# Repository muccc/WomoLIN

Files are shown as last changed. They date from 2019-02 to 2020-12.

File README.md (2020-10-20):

use: git clone https://github.com/muccc/WomoLIN.git

# WomoLIN Hardware und sonstige Infos zum Projekt

Neue Wege in der konfigurierbaren Software Entwicklung eines Community Projektes

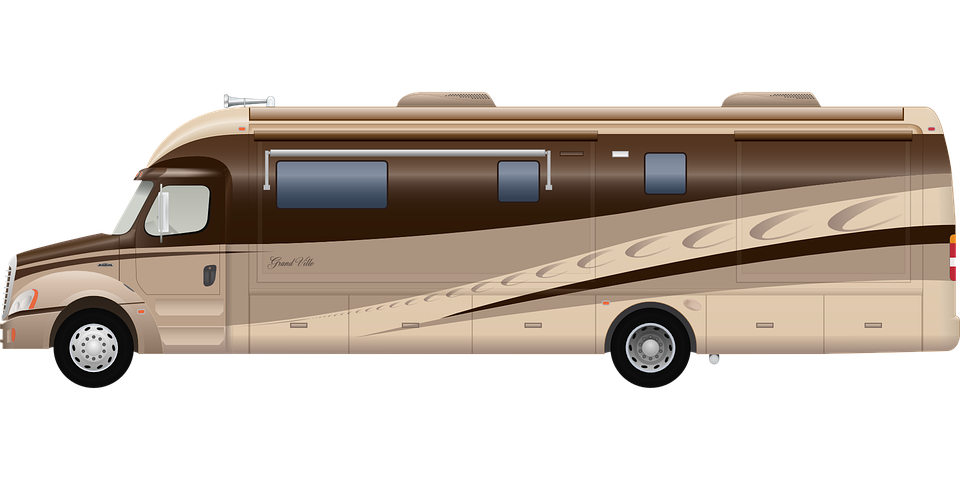
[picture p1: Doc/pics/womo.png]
Womo Bild


Alle Infos findet Ihr in unserem Wiki hier auf Github. 

https://github.com/muccc/WomoLIN/wiki/Home

# WomoLIN Meilensteine und Projektfortschritt

**18.Okt 2020  :** 100. Mitglied in unserer Telegramgruppe <br/>
**10.Aug 2020  :** Inbetriebnahme Controlboard 2.0.<br/>
**10.Juli 2020  :** Controlboard 2.0.<br/>
**10.Juni 2020  :** Beginn Einbau Controlboard in Womo von Jan.<br/>
**15.Mai 2020  :** Erstes Displayboard Kleinserie.<br/>
**11.Apr 2020  :** Erste Inbetriebnahme Display Unit mit Display.<br/>
**19.Mrz 2020  :** Die ersten Hardware für die Display Unit ist angekommen.<br/>
**16.Dez. bis 30.Dez.2019 :** 36th Chaos Communication Congress in Leipzig, Jan stellt die Hardware vor.<br/>
**10.Dez 2019  :** Die ersten Leiterplatten der Main Unit / Controlboard sind angekommen.<br/>
**03.Dez 2019  :** Der Schaltplan der Main Unit ist fertig gestellt.<br/> 

## **10.Aug 2020  :** Inbetriebnahme Controlboard 2.0.<br/>
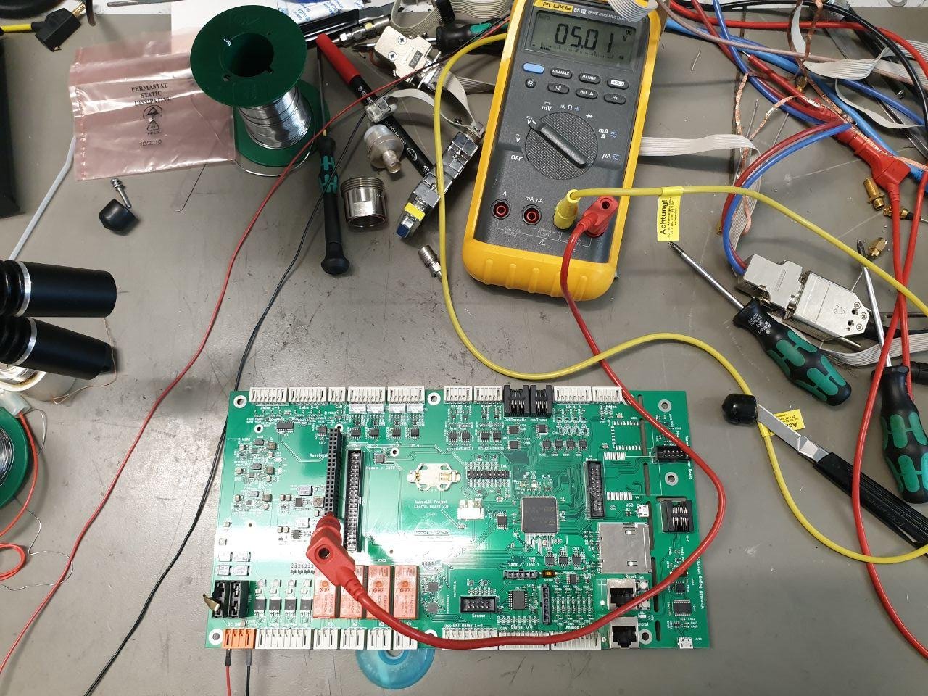
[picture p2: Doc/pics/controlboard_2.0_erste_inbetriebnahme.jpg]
Inbetriebnahme Controlboard 2.0


## **10.Juli 2020  :** Controlboard 2.0.<br/>
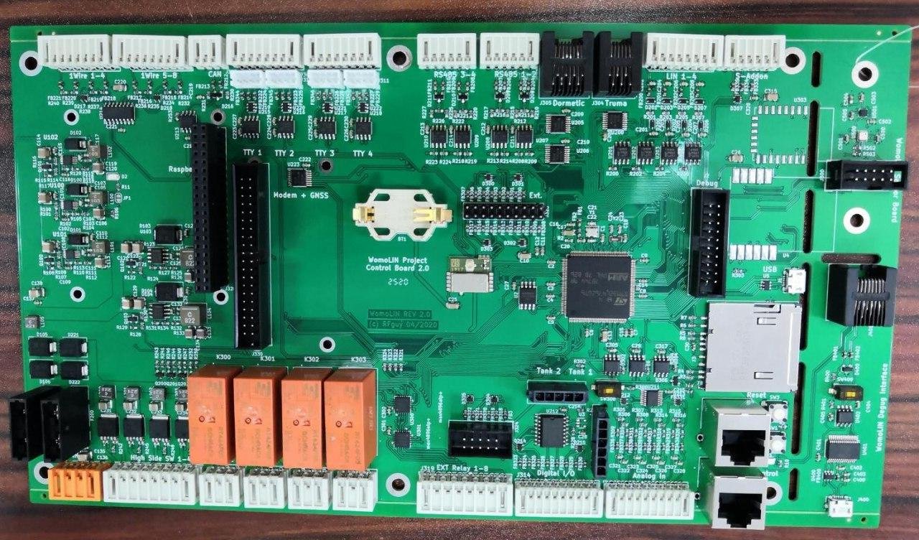
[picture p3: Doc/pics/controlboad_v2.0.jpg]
Controlboard 2.0


## **10.Juni 2020  :** Beginn Einbau Controlboard in Womo von Jan.<br/>
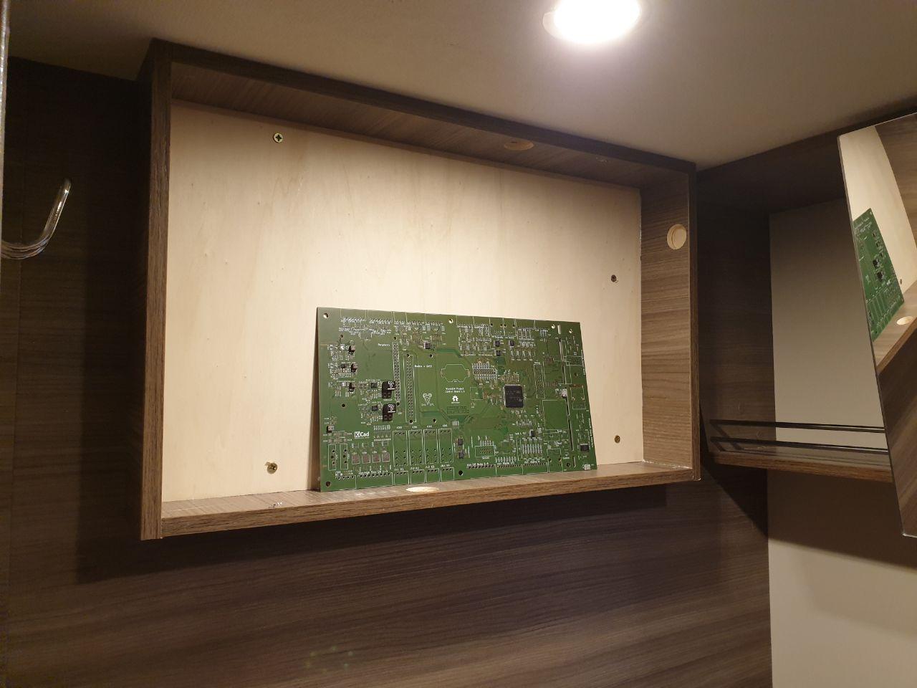
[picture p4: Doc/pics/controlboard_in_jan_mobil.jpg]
Beginn Einbau Controlboard in Womo von Jan


## **15.Mai 2020  :** Erstes Displayboard Kleinserie.<br/>
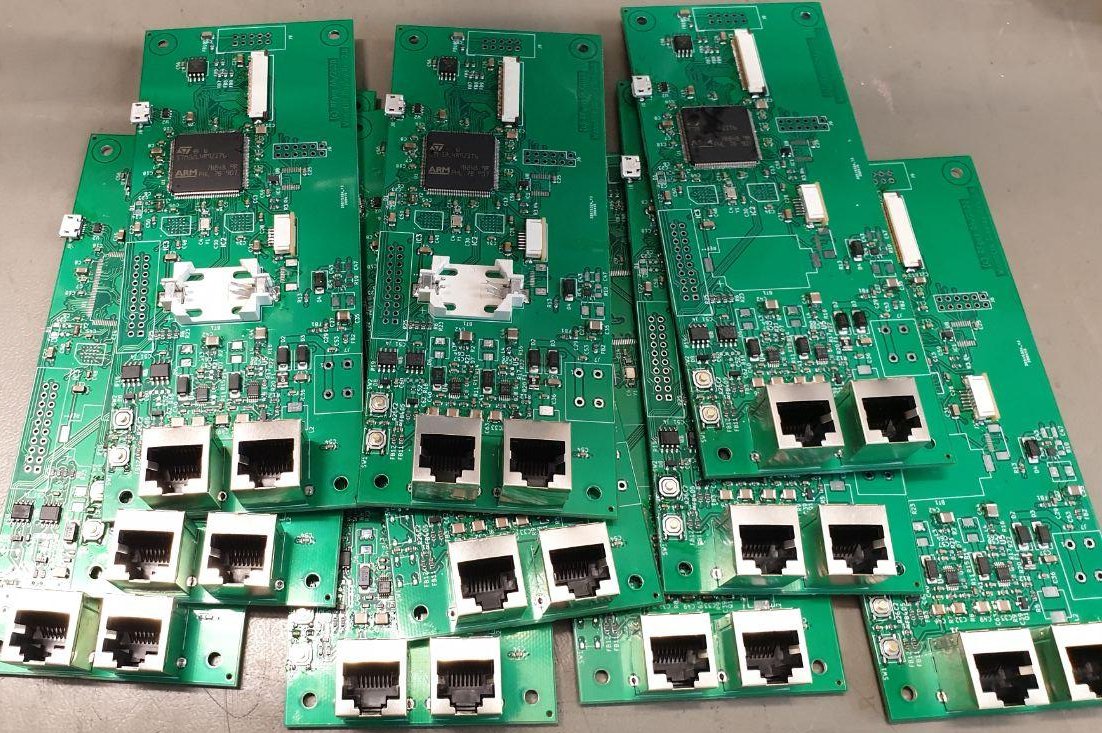
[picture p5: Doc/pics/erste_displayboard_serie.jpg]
Erstes Displayboard Kleinserie


## **11.Apr 2020  :** Erste Inbetriebnahme Display Unit mit Display.<br/>
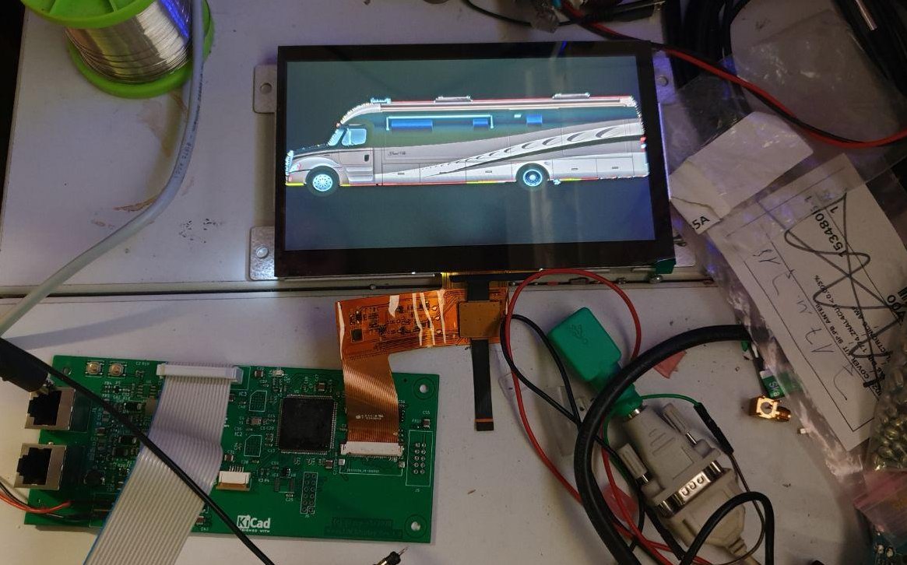
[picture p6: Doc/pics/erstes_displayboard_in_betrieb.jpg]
Erstes Displayboard in Betrieb mit Display


## **19.Mrz 2020  :** Die ersten Hardware für die Display Unit ist angekommen.<br/>
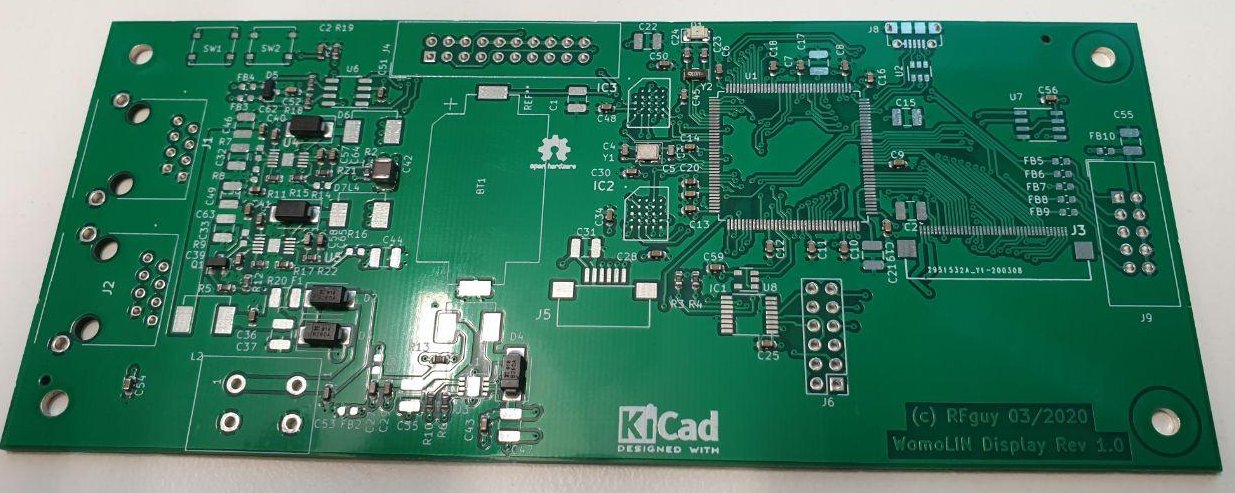
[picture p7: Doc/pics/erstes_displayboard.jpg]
Erstes Displayboard


## **16.Dez. bis 30.Dez.2019 :** 36th Chaos Communication Congress in Leipzig, Jan stellt die Hardware vor.<br/> 

## **10.Dez 2019  :** Die ersten Leiterplatten der Main Unit / Controlboard sind angekommen.<br/>
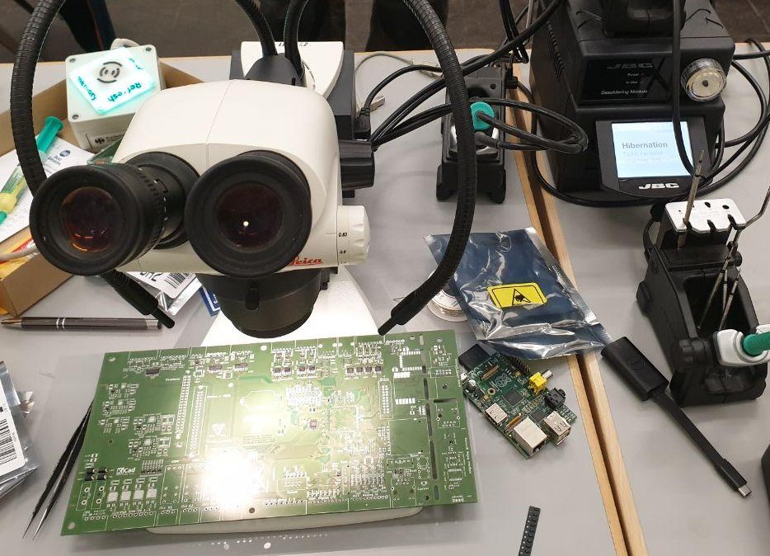
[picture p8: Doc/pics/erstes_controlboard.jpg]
Erstes Controlboard


## **03.Dez 2019  :** Der Schaltplan der Main Unit ist fertig gestellt.<br/>

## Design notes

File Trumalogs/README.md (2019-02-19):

# Womo_LIN

Open Source Steuerung von LIN Bus Geräten im Caravan Bereich.

Hier soll erstmal das System analysiert werden, die Caravanindustrie macht einen Riesenalarm um diese Daten, eine kommerzielle Nutzung könnte fraglich sein. Der ganze CI Bus kram läuft unter NDA.

Benutzt wir der Microchip Lin Bus Analyzer APGDT001, Pin3 vom RJ12 ist LIN, Pin5 ist GND. Masse und 12 V parallel zur Stromversorgung der Truma Inet Box. Alle Komponenten sind parallel am TIN1 Bus geschaltet (Mit RJ12 Verteilern).

Benutz wird die MAC Version V3 von Microchip.

## Truma CP plus iNet ready

Microcontroller ist ein [STM32L152R8](https://www.st.com/en/microcontrollers/stm32l152r8.html). 
Es gibt auf der Platine einen unbestückten 2x10 Pinheader mit viel GND. Das könnte ein ARM-JTAG
Connector sein.

## Logs

| Logfile | Truma Devices | Comment |
|---|---|---|
| cp_plus-combi_6d_e-inet_box.log | CP plus, Combi D6 E, iNet Box | Just powering on, no inputs done |
| cp_plus.log | CP plus | Just powering on the CP plus without connecting anything else |
| cp_plus-set_fan_eco.log | CP plus, Combi D6 E, iNet Box | Setting just the fan from high to eco mode once |
| cp_plus-set_fan_high.log | CP plus, Combi D6 E, iNet Box | Setting just the fan from eco to high mode once |
| cp_plus-set_heating_to_19.log | CP plus, Combi D6 E, iNet Box | Setting heating temperature to 19°C |
| cp_plus-set_heating_to_20.log | CP plus, Combi D6 E, iNet Box | Setting heating temperature to 20°C |
| cp_plus-set_heating_to_21.log | CP plus, Combi D6 E, iNet Box | Setting heating temperature to 21°C |
| cp_plus-toggle_fan.log | CP plus, Combi D6 E, iNet Box | Toggling the fan mode multiple times |
| cp_plus-toggle_heating_19_20.log | CP plus, Combi D6 E, iNet Box | Toggling the temperature between 19° and 20°C multiple times  |
| Log Truma CP Plus init mit AC | | |
| Log Truma CP Plus init mit Combi 6 | | |
| Log Truma CP Plus init mit Combi 6 und AC | | |
| truma_app-disable_heating.log | CP plus, Combi D6 E, iNet Box | Disable heating via android app |
| truma_app-enable_heating.log | CP plus, Combi D6 E, iNet Box | Enable heating via android app |
| truma_app-energy_sel_el1.log | CP plus, Combi D6 E, iNet Box | Set energy mode to EL1 via android app |
| truma_app-energy_sel_el2.log | CP plus, Combi D6 E, iNet Box | Set energy mode to EL2 via android app |
| truma_app-energy_sel_fuel.log | CP plus, Combi D6 E, iNet Box | Set energy mode to fuel  via android app |
| truma_app-energy_sel_mix1.log | CP plus, Combi D6 E, iNet Box | Set energy mode to MIX1 via android app |
| truma_app-energy_sel_mix2.log | CP plus, Combi D6 E, iNet Box | Set energy mode to MIX2 via android app |
| truma_app-set_fan_eco.log | CP plus, Combi D6 E, iNet Box | Set fan mode to eco  via android app |
| truma_app-set_fan_high.log | CP plus, Combi D6 E, iNet Box | Set fan mode to high via  via android app |
| truma_app-set_heating_to_13.log | CP plus, Combi D6 E, iNet Box | Set temperature to 13 °C via android app |
| truma_app-set_heating_to_14.log | CP plus, Combi D6 E, iNet Box | Set temperature to 14 °C via android app |
| truma_app-set_heating_to_15.log | CP plus, Combi D6 E, iNet Box | Set temperature to 15 °C via android app |
| truma_app-set_heating_to_16.log | CP plus, Combi D6 E, iNet Box | Set temperature to 16 °C via android app |
| truma_app-set_heating_to_17.log | CP plus, Combi D6 E, iNet Box | Set temperature to 17 °C via android app |
| truma_app-set_heating_to_18.log | CP plus, Combi D6 E, iNet Box | Set temperature to 18 °C via android app |
| truma_app-set_heating_to_19.log | CP plus, Combi D6 E, iNet Box | Set temperature to 19 °C via android app |
| truma_app-set_heating_to_20.log | CP plus, Combi D6 E, iNet Box | Set temperature to 20 °C via android app |
| truma_app-set_heating_to_21.log | CP plus, Combi D6 E, iNet Box | Set temperature to 21 °C via android app |
| truma_app-set_heating_to_22.log | CP plus, Combi D6 E, iNet Box | Set temperature to 22 °C via android app |

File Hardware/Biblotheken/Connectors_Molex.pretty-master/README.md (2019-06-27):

# Connectors_Molex.pretty

This library contains PCB footprints for Molex connectors - http://www.molex.com/molex/home

## Note

This repository is now marked as read-only and will no longer accept pull requests. To contribute, refer to the new footprints library at https://github.com/kicad/kicad-footprints

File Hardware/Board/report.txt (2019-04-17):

Hinweis: Überprüfe aus der Netzliste den Symbolfootprint „C52:/5C8BBC9A/5CC0C224:“.

Hinweis: Überprüfe aus der Netzliste den Symbolfootprint „C62:/5C9E4308/5CA32332:“.

Hinweis: Überprüfe aus der Netzliste den Symbolfootprint „C61:/5C9E4308/5CA32292:“.

Hinweis: Überprüfe aus der Netzliste den Symbolfootprint „C60:/5C8BC88B/5CB2F4A7:“.

Hinweis: Überprüfe aus der Netzliste den Symbolfootprint „C59:/5C8BC88B/5CC019EB:“.

Hinweis: Überprüfe aus der Netzliste den Symbolfootprint „C58:/5C8BC88B/5CC01965:“.

Hinweis: Überprüfe aus der Netzliste den Symbolfootprint „C57:/5C8BBC9A/5CA4FC89:“.

Hinweis: Überprüfe aus der Netzliste den Symbolfootprint „C56:/5C8BBC9A/5CA4FBFF:“.

Hinweis: Überprüfe aus der Netzliste den Symbolfootprint „C55:/5C8BBC9A/5CC0C17C:“.

Hinweis: Überprüfe aus der Netzliste den Symbolfootprint „C54:/5C8BBC9A/5CA4FC47:“.

Hinweis: Überprüfe aus der Netzliste den Symbolfootprint „C53:/5C8BBC9A/5CB6E23E:“.

Hinweis: Überprüfe aus der Netzliste den Symbolfootprint „D1:/5C8BBC94/5CAADD43:Package_TO_SOT_SMD:SOT-353_SC-70-5“.

Hinweis: Überprüfe aus der Netzliste den Symbolfootprint „C51:/5C8BBC9A/5CBBDA5B:“.

Hinweis: Überprüfe aus der Netzliste den Symbolfootprint „C50:/5C8BBC9A/5CC0C1AB:“.

Hinweis: Überprüfe aus der Netzliste den Symbolfootprint „C49:/5C8BBC9A/5CB6E102:“.

Hinweis: Überprüfe aus der Netzliste den Symbolfootprint „C48:/5C8BBC9A/5CA4FE23:“.

Hinweis: Überprüfe aus der Netzliste den Symbolfootprint „C47:/5C8BBC9A/5CC0C20A:“.

Hinweis: Überprüfe aus der Netzliste den Symbolfootprint „C46:/5C8BBC9A/5CC0C1A4:“.

Hinweis: Überprüfe aus der Netzliste den Symbolfootprint „C45:/5C8BBC9A/5CB6E345:“.

Hinweis: Überprüfe aus der Netzliste den Symbolfootprint „C44:/5C8BBC9A/5CA4FA44:“.

Hinweis: Überprüfe aus der Netzliste den Symbolfootprint „C43:/5C8BBC9A/5CB6E445:“.

Hinweis: Überprüfe aus der Netzliste den Symbolfootprint „D11:/5C8BBC97/5CA09B16:“.

Hinweis: Überprüfe aus der Netzliste den Symbolfootprint „FB6:/5C8BBC97/5CBC1E32:“.

Hinweis: Überprüfe aus der Netzliste den Symbolfootprint „FB5:/5C8BBC97/5CBB7155:“.

Hinweis: Überprüfe aus der Netzliste den Symbolfootprint „FB4:/5C8BBC97/5CBB38BB:“.

Hinweis: Überprüfe aus der Netzliste den Symbolfootprint „FB3:/5C8BBC97/5CB9B191:“.

Hinweis: Überprüfe aus der Netzliste den Symbolfootprint „FB2:/5C8BBC97/5CBA2081:“.

Hinweis: Überprüfe aus der Netzliste den Symbolfootprint „FB1:/5C8BBC97/5CB9AFD5:“.

Hinweis: Überprüfe aus der Netzliste den Symbolfootprint „F1:/5C8BBC9A/5CB6DEB6:“.

Hinweis: Überprüfe aus der Netzliste den Symbolfootprint „D13:/5C9E4308/5CA2F87E:Package_TO_SOT_SMD:SOT-353_SC-70-5“.

Hinweis: Überprüfe aus der Netzliste den Symbolfootprint „D12:/5C9E4308/5CA2F7A2:Package_TO_SOT_SMD:SOT-353_SC-70-5“.

Hinweis: Überprüfe aus der Netzliste den Symbolfootprint „C41:/5C8BBC9A/5CA4FAF6:“.

Hinweis: Überprüfe aus der Netzliste den Symbolfootprint „D10:/5C8BBC97/5CA046D0:“.

Hinweis: Überprüfe aus der Netzliste den Symbolfootprint „D9:/5C8BBC97/5CA5CD14:“.

Hinweis: Überprüfe aus der Netzliste den Symbolfootprint „D8:/5C8BBC97/5CA4F5D6:“.

Hinweis: Überprüfe aus der Netzliste den Symbolfootprint „D7:/5C8BBC97/5CA5F6FE:“.

Hinweis: Überprüfe aus der Netzliste den Symbolfootprint „D6:/5C8BBC97/5C9F7A03:“.

Hinweis: Überprüfe aus der Netzliste den Symbolfootprint „D5:/5C8BBC97/5C9F7854:“.

Hinweis: Überprüfe aus der Netzliste den Symbolfootprint „D4:/5C8BBC97/5C9F7715:“.

Hinweis: Überprüfe aus der Netzliste den Symbolfootprint „D3:/5C8BBC94/5CA2F4B9:Package_TO_SOT_SMD:SOT-353_SC-70-5“.

Hinweis: Überprüfe aus der Netzliste den Symbolfootprint „D2:/5C8BBC94/5CAB197E:Package_TO_SOT_SMD:SOT-353_SC-70-5“.

Hinweis: Überprüfe aus der Netzliste den Symbolfootprint „C11:/5C8BBC94/5CA058B6:“.

Hinweis: Überprüfe aus der Netzliste den Symbolfootprint „C20:/5C8BBC97/5C9B9A0F:“.

Hinweis: Überprüfe aus der Netzliste den Symbolfootprint „C19:/5C8BBC97/5C9B9930:“.

Hinweis: Überprüfe aus der Netzliste den Symbolfootprint „U2:/5C8BBC94/5C9E12E3:Package_SO:TSSOP-8_4.4x3mm_P0.65mm“.

Hinweis: Überprüfe aus der Netzliste den Symbolfootprint „C18:/5C8BBC97/5C9B97EB:“.

Hinweis: Überprüfe aus der Netzliste den Symbolfootprint „C17:/5C8BBC97/5C9B96D7:“.

Hinweis: Überprüfe aus der Netzliste den Symbolfootprint „C16:/5C8BBC97/5C9B95B0:“.

Hinweis: Überprüfe aus der Netzliste den Symbolfootprint „C15:/5C8BBC94/5CA9B7A9:“.

Hinweis: Überprüfe aus der Netzliste den Symbolfootprint „C14:/5C8BBC94/5CC5CD10:“.

Hinweis: Überprüfe aus der Netzliste den Symbolfootprint „C13:/5C8BBC94/5CA1D165:“.

Hinweis: Überprüfe aus der Netzliste den Symbolfootprint „C12:/5C8BBC94/5CA1D026:“.

Hinweis: Überprüfe aus der Netzliste den Symbolfootprint „C21:/5C8BBC97/5C9B9B27:“.

Hinweis: Überprüfe aus der Netzliste den Symbolfootprint „C10:/5C8BBC94/5CA05796:“.

Hinweis: Überprüfe aus der Netzliste den Symbolfootprint „C9:/5C8BBC94/5CA058F8:“.

Hinweis: Überprüfe aus der Netzliste den Symbolfootprint „U3:/5C8BBC97/5C8BC1B4:Package_SO:SOIC-8_3.9x4.9mm_P1.27mm“.

Hinweis: Überprüfe aus der Netzliste den Symbolfootprint „C8:/5C8BBC94/5C9DF521:“.

Hinweis: Überprüfe aus der Netzliste den Symbolfootprint „C7:/5C8BBC94/5C9DF5C2:“.

Hinweis: Überprüfe aus der Netzliste den Symbolfootprint „C6:/5C8BBC94/5C9DF60F:“.

Hinweis: Überprüfe aus der Netzliste den Symbolfootprint „C5:/5C8BBC94/5C9DF7EC:“.

Hinweis: Überprüfe aus der Netzliste den Symbolfootprint „C4:/5C8BBC94/5C9DF857:“.

Hinweis: Überprüfe aus der Netzliste den Symbolfootprint „C3:/5C8BBC94/5CA2B1BF:“.

Hinweis: Überprüfe aus der Netzliste den Symbolfootprint „C31:/5C8BBC9A/5CA8404B:“.

Hinweis: Überprüfe aus der Netzliste den Symbolfootprint „C40:/5C8BBC9A/5CA4FB3E:“.

Hinweis: Überprüfe aus der Netzliste den Symbolfootprint „C39:/5C8BBC9A/5CA78528:“.

Hinweis: Überprüfe aus der Netzliste den Symbolfootprint „C38:/5C8BBC9A/5CA5F7DC:“.

Hinweis: Überprüfe aus der Netzliste den Symbolfootprint „C37:/5C8BBC9A/5CA770C1:“.

Hinweis: Überprüfe aus der Netzliste den Symbolfootprint „C36:/5C8BBC9A/5CACF0A8:“.

Hinweis: Überprüfe aus der Netzliste den Symbolfootprint „C35:/5C8BBC9A/5CA78550:“.

Hinweis: Überprüfe aus der Netzliste den Symbolfootprint „C34:/5C8BBC9A/5CA63ED7:“.

Hinweis: Überprüfe aus der Netzliste den Symbolfootprint „C33:/5C8BBC9A/5CA770E9:“.

Hinweis: Überprüfe aus der Netzliste den Symbolfootprint „C32:/5C8BBC9A/5CAB698C:“.

Hinweis: Überprüfe aus der Netzliste den Symbolfootprint „FB7:/5C8BBC97/5CBC582D:“.

Hinweis: Überprüfe aus der Netzliste den Symbolfootprint „C30:/5C8BBC9A/5CA630A8:“.

Hinweis: Überprüfe aus der Netzliste den Symbolfootprint „C29:/5C8BBC9A/5CA8259F:“.

Hinweis: Überprüfe aus der Netzliste den Symbolfootprint „C28:/5C8BBC9A/5CA84058:“.

Hinweis: Überprüfe aus der Netzliste den Symbolfootprint „C27:/5C8BBC9A/5CA67A0B:“.

Hinweis: Überprüfe aus der Netzliste den Symbolfootprint „C26:/5C8BBC9A/5CA825AC:“.

Hinweis: Überprüfe aus der Netzliste den Symbolfootprint „C25:/5C8BBC97/5CA2DCD5:“.

Hinweis: Überprüfe aus der Netzliste den Symbolfootprint „C24:/5C8BBC97/5C9CD5F6:“.

Hinweis: Überprüfe aus der Netzliste den Symbolfootprint „C23:/5C8BBC97/5C9DF7C6:“.

Hinweis: Überprüfe aus der Netzliste den Symbolfootprint „C22:/5C8BBC97/5C9CCACE:“.

Hinweis: Überprüfe aus der Netzliste den Symbolfootprint „R16:/5C8BBC9A/5CB0A520:“.

Hinweis: Überprüfe aus der Netzliste den Symbolfootprint „R23:/5C8BBC9A/5CA770DC:“.

Hinweis: Überprüfe aus der Netzliste den Symbolfootprint „R22:/5C8BBC9A/5CA770D5:“.

Hinweis: Überprüfe aus der Netzliste den Symbolfootprint „R44:/5C9E4308/5CB09421:“.

Hinweis: Überprüfe aus der Netzliste den Symbolfootprint „R21:/5C8BBC9A/5CAB3DDA:“.

Hinweis: Überprüfe aus der Netzliste den Symbolfootprint „R20:/5C8BBC9A/5CA8406F:“.

Hinweis: Überprüfe aus der Netzliste den Symbolfootprint „R45:/5C9E4308/5CB0AFCE:“.

Hinweis: Überprüfe aus der Netzliste den Symbolfootprint „R19:/5C8BBC9A/5CA6F323:“.

Hinweis: Überprüfe aus der Netzliste den Symbolfootprint „R18:/5C8BBC9A/5CA825C3:“.

Hinweis: Überprüfe aus der Netzliste den Symbolfootprint „R46:/5C9E4308/5CB09A98:“.

Hinweis: Überprüfe aus der Netzliste den Symbolfootprint „R17:/5C8BBC9A/5CB07864:“.

Hinweis: Überprüfe aus der Netzliste den Symbolfootprint „R43:/5C9E4308/5CB0A956:“.

Hinweis: Überprüfe aus der Netzliste den Symbolfootprint „R47:/5C9E4308/5CB0B63D:“.

Hinweis: Überprüfe aus der Netzliste den Symbolfootprint „R15:/5C8BBC9A/5CAA3D7C:“.

Hinweis: Überprüfe aus der Netzliste den Symbolfootprint „R14:/5C8BBC9A/5CAA5DC1:“.

Hinweis: Überprüfe aus der Netzliste den Symbolfootprint „SW1:/5C8BBC94/5CA4B2AF:“.

Hinweis: Überprüfe aus der Netzliste den Symbolfootprint „R13:/5C8BBC9A/5CB04AF0:“.

Hinweis: Überprüfe aus der Netzliste den Symbolfootprint „R12:/5C8BBC9A/5CAFE75A:“.

Hinweis: Überprüfe aus der Netzliste den Symbolfootprint „U1:/5C8BBC94/5C9ED2F4:Package_QFP:LQFP-100_14x14mm_P0.5mm“.

Hinweis: Überprüfe aus der Netzliste den Symbolfootprint „R11:/5C8BBC97/5C9D51AA:“.

Hinweis: Überprüfe aus der Netzliste den Symbolfootprint „R10:/5C8BBC97/5CA09D45:“.

Hinweis: Überprüfe aus der Netzliste den Symbolfootprint „R30:/5C8BBC9A/5CA5594B:“.

Hinweis: Überprüfe aus der Netzliste den Symbolfootprint „R36:/5C8BBC9A/5CC0C190:“.

Hinweis: Überprüfe aus der Netzliste den Symbolfootprint „R37:/5C8BBC9A/5CC0C197:“.

Hinweis: Überprüfe aus der Netzliste den Symbolfootprint „R35:/5C8BBC9A/5CA5005E:“.

Hinweis: Überprüfe aus der Netzliste den Symbolfootprint „R34:/5C8BBC9A/5CC0C203:“.

Hinweis: Überprüfe aus der Netzliste den Symbolfootprint „R38:/5C8BBC9A/5CA4FF24:“.

Hinweis: Überprüfe aus der Netzliste den Symbolfootprint „R33:/5C8BBC9A/5CC0C1F2:“.

Hinweis: Überprüfe aus der Netzliste den Symbolfootprint „R32:/5C8BBC9A/5CB4A203:“.

Hinweis: Überprüfe aus der Netzliste den Symbolfootprint „R39:/5C8BBC9A/5CA4FFFE:“.

Hinweis: Überprüfe aus der Netzliste den Symbolfootprint „R31:/5C8BBC9A/5CC0C242:“.

Hinweis: Überprüfe aus der Netzliste den Symbolfootprint „R9:/5C8BBC97/5CA09C3A:“.

Hinweis: Überprüfe aus der Netzliste den Symbolfootprint „R40:/5C9E4308/5CB0822F:“.

Hinweis: Überprüfe aus der Netzliste den Symbolfootprint „R29:/5C8BBC9A/5CC0C23B:“.

Hinweis: Überprüfe aus der Netzliste den Symbolfootprint „R28:/5C8BBC9A/5CA54E27:“.

Hinweis: Überprüfe aus der Netzliste den Symbolfootprint „R41:/5C9E4308/5CB0A108:“.

Hinweis: Überprüfe aus der Netzliste den Symbolfootprint „R27:/5C8BBC9A/5CA78543:“.

Hinweis: Überprüfe aus der Netzliste den Symbolfootprint „R26:/5C8BBC9A/5CA7853C:“.

Hinweis: Überprüfe aus der Netzliste den Symbolfootprint „R42:/5C9E4308/5CB08DA5:“.

Hinweis: Überprüfe aus der Netzliste den Symbolfootprint „R25:/5C8BBC9A/5CA60ED9:“.

Hinweis: Überprüfe aus der Netzliste den Symbolfootprint „R24:/5C8BBC9A/5CA60ED2:“.

Hinweis: Überprüfe aus der Netzliste den Symbolfootprint „J2:/5C8BBC94/5CA7452F:“.

Hinweis: Überprüfe aus der Netzliste den Symbolfootprint „J11:/5CC9A992/5CBD13E9:“.

Hinweis: Überprüfe aus der Netzliste den Symbolfootprint „J10:/5CC9A992/5CB5FC2E:“.

Hinweis: Überprüfe aus der Netzliste den Symbolfootprint „J9:/5CC9A992/5CB5FBA8:“.

Hinweis: Überprüfe aus der Netzliste den Symbolfootprint „J8:/5CC9A992/5CB5F9FC:“.

Hinweis: Überprüfe aus der Netzliste den Symbolfootprint „J7:/5CC9A992/5CBD1756:“.

Hinweis: Überprüfe aus der Netzliste den Symbolfootprint „J6:/5C8BC88B/5C8BC8C5:“.

Hinweis: Überprüfe aus der Netzliste den Symbolfootprint „J5:/5C8BBC94/5CA25131:“.

Hinweis: Überprüfe aus der Netzliste den Symbolfootprint „J4:/5C8BBC94/5CA74436:“.

Hinweis: Überprüfe aus der Netzliste den Symbolfootprint „J3:/5C8BBC94/5CA22A0B:“.

Hinweis: Überprüfe aus der Netzliste den Symbolfootprint „J12:/5CC9A992/5CBD1556:“.

Hinweis: Überprüfe aus der Netzliste den Symbolfootprint „J1:/5C8BBC94/5CB67827:SamacSys_Parts:1-1734592-2“.

Hinweis: Überprüfe aus der Netzliste den Symbolfootprint „FB15:/5C9E4308/5CB802AF:“.

Hinweis: Überprüfe aus der Netzliste den Symbolfootprint „FB14:/5C9E4308/5CB7EBBA:“.

Hinweis: Überprüfe aus der Netzliste den Symbolfootprint „FB13:/5C9E4308/5CB802A8:“.

Hinweis: Überprüfe aus der Netzliste den Symbolfootprint „FB12:/5C9E4308/5CB7BD43:“.

Hinweis: Überprüfe aus der Netzliste den Symbolfootprint „FB11:/5C9E4308/5CB802A1:“.

Hinweis: Überprüfe aus der Netzliste den Symbolfootprint „FB10:/5C9E4308/5CB7A78A:“.

Hinweis: Überprüfe aus der Netzliste den Symbolfootprint „FB9:/5C9E4308/5CB8029A:“.

Hinweis: Überprüfe aus der Netzliste den Symbolfootprint „FB8:/5C9E4308/5CB78DEE:“.

Hinweis: Überprüfe aus der Netzliste den Symbolfootprint „Q3:/5C8BBC9A/5CA54BA8:“.

Hinweis: Überprüfe aus der Netzliste den Symbolfootprint „R8:/5C8BBC97/5CA11B40:“.

Hinweis: Überprüfe aus der Netzliste den Symbolfootprint „R7:/5C8BBC97/5CA11A13:“.

Hinweis: Überprüfe aus der Netzliste den Symbolfootprint „R6:/5C8BBC97/5C9B6CCB:“.

Hinweis: Überprüfe aus der Netzliste den Symbolfootprint „R5:/5C8BBC97/5C9B6BDC:“.

Hinweis: Überprüfe aus der Netzliste den Symbolfootprint „R4:/5C8BBC97/5C9B6B4C:“.

Hinweis: Überprüfe aus der Netzliste den Symbolfootprint „R3:/5C8BBC97/5C9B6F96:“.

Hinweis: Überprüfe aus der Netzliste den Symbolfootprint „R2:/5C8BBC97/5C9B6ECE:“.

Hinweis: Überprüfe aus der Netzliste den Symbolfootprint „R1:/5C8BBC97/5C9B6DD5:“.

Hinweis: Überprüfe aus der Netzliste den Symbolfootprint „Q4:/5C8BBC9A/5CC0C22E:“.

Hinweis: Überprüfe aus der Netzliste den Symbolfootprint „C42:/5C8BBC9A/5CC0C1C2:“.

Hinweis: Überprüfe aus der Netzliste den Symbolfootprint „Q2:/5C8BBC9A/5CB04AE3:“.

Hinweis: Überprüfe aus der Netzliste den Symbolfootprint „Q1:/5C8BBC9A/5CAED088:“.

Hinweis: Überprüfe aus der Netzliste den Symbolfootprint „L6:/5C8BBC9A/5CC0C183:“.

Hinweis: Überprüfe aus der Netzliste den Symbolfootprint „L5:/5C8BBC9A/5CA4FCEF:“.

Hinweis: Überprüfe aus der Netzliste den Symbolfootprint „L4:/5C8BBC9A/5CB6DCC1:“.

Hinweis: Überprüfe aus der Netzliste den Symbolfootprint „L3:/5C8BBC9A/5CA7852F:“.

Hinweis: Überprüfe aus der Netzliste den Symbolfootprint „L2:/5C8BBC9A/5CA5F7E3:“.

Hinweis: Überprüfe aus der Netzliste den Symbolfootprint „L1:/5C8BBC9A/5CA770C8:“.

Hinweis: Überprüfe aus der Netzliste den Symbolfootprint „J13:/5CC9A992/5CBE3A31:“.

Hinweis: Überprüfe aus der Netzliste den Symbolfootprint „C2:/5C8BBC94/5CA2B358:“.

Hinweis: Überprüfe aus der Netzliste den Symbolfootprint „U10:/5C8BBC9A/5CA4BA4B:Package_DFN_QFN:DFN-12-1EP_3x3mm_P0.5mm_EP2.05x2.86mm“.

Hinweis: Überprüfe aus der Netzliste den Symbolfootprint „U9:/5C8BBC9A/5CA4B9FD:Package_DFN_QFN:DFN-12-1EP_3x3mm_P0.5mm_EP2.05x2.86mm“.

Hinweis: Überprüfe aus der Netzliste den Symbolfootprint „U11:/5C8BBC9A/5CC0C21D:Package_DFN_QFN:DFN-12-1EP_3x3mm_P0.5mm_EP2.05x2.86mm“.

Hinweis: Überprüfe aus der Netzliste den Symbolfootprint „U8:/5C8BBC9A/5CA4B92D:Package_DFN_QFN:DFN-12-1EP_3x3mm_P0.5mm_EP2.05x2.86mm“.

Hinweis: Überprüfe aus der Netzliste den Symbolfootprint „U12:/5C8BBC9A/5CA4BB0F:Package_DFN_QFN:QFN-24-1EP_4x5mm_P0.5mm_EP2.65x3.65mm“.

Hinweis: Überprüfe aus der Netzliste den Symbolfootprint „U7:/5C8BBC97/5C8BC743:Package_SO:SOIC-8_3.9x4.9mm_P1.27mm“.

Hinweis: Überprüfe aus der Netzliste den Symbolfootprint „U6:/5C8BBC97/5C8BC5DF:Package_SO:SOIC-8_3.9x4.9mm_P1.27mm“.

Hinweis: Überprüfe aus der Netzliste den Symbolfootprint „U13:/5C8BC88B/5CAB8BB3:RF_Module:ESP-12E“.

Hinweis: Überprüfe aus der Netzliste den Symbolfootprint „U5:/5C8BBC97/5C8BC4A4:Package_SO:SOIC-8_3.9x4.9mm_P1.27mm“.

Hinweis: Überprüfe aus der Netzliste den Symbolfootprint „U4:/5C8BBC97/5C8BC3EB:Package_SO:SOIC-8_3.9x4.9mm_P1.27mm“.

Hinweis: Überprüfe aus der Netzliste den Symbolfootprint „Y2:/5C8BBC94/5CA1CD9F:“.

Hinweis: Überprüfe aus der Netzliste den Symbolfootprint „U14:/5C9E4308/5C9E4327:21-0041B_16“.

Hinweis: Überprüfe aus der Netzliste den Symbolfootprint „C1:/5C8BBC94/5CA39760:“.

Hinweis: Überprüfe aus der Netzliste den Symbolfootprint „Y1:/5C8BBC94/5CA1CF07:“.

Ändere Netzname von Footprint „U11:/5C8BBC9A/5CC0C21D“ Pin „6“ von „“ zu "Net-(R33-Pad1)".

Ändere Netzname von Footprint „U11:/5C8BBC9A/5CC0C21D“ Pin „13“ von „“ zu "GND".

Ändere Netzname von Footprint „U1:/5C8BBC94/5C9ED2F4“ Pin „30“ von „“ zu "Disp_SCK".

Ändere Netzname von Footprint „U11:/5C8BBC9A/5CC0C21D“ Pin „7“ von „“ zu "Net-(R36-Pad2)".

Ändere Netzname von Footprint „U1:/5C8BBC94/5C9ED2F4“ Pin „31“ von „“ zu "Disp_MISO".

Füge neues Bauteil „U11:/5C8BBC9A/5CC0C21D“ mit Footprint „Package_DFN_QFN:DFN-12-1EP_3x3mm_P0.5mm_EP2.05x2.86mm“ hinzu.

Ändere Netzname von Footprint „U1:/5C8BBC94/5C9ED2F4“ Pin „32“ von „“ zu "Disp_MOSI".

Ändere Netzname von Footprint „U1:/5C8BBC94/5C9ED2F4“ Pin „33“ von „“ zu "Net-(U1-Pad33)".

Ändere Netzname von Footprint „U10:/5C8BBC9A/5CA4BA4B“ Pin „7“ von „“ zu "Net-(R26-Pad2)".

Ändere Netzname von Footprint „U1:/5C8BBC94/5C9ED2F4“ Pin „34“ von „“ zu "Net-(U1-Pad34)".

Ändere Netzname von Footprint „U10:/5C8BBC9A/5CA4BA4B“ Pin „6“ von „“ zu "Net-(R20-Pad1)".

Ändere Netzname von Footprint „U1:/5C8BBC94/5C9ED2F4“ Pin „35“ von „“ zu "Net-(U1-Pad35)".

Ändere Netzname von Footprint „U10:/5C8BBC9A/5CA4BA4B“ Pin „13“ von „“ zu "GND".

Ändere Netzname von Footprint „U1:/5C8BBC94/5C9ED2F4“ Pin „36“ von „“ zu "Net-(U1-Pad36)".

Ändere Netzname von Footprint „U10:/5C8BBC9A/5CA4BA4B“ Pin „12“ von „“ zu "GND".

Ändere Netzname von Footprint „U1:/5C8BBC94/5C9ED2F4“ Pin „37“ von „“ zu "Net-(U1-Pad37)".

Ändere Netzname von Footprint „U1:/5C8BBC94/5C9ED2F4“ Pin „25“ von „“ zu "Net-(U1-Pad25)".

Ändere Netzname von Footprint „U1:/5C8BBC94/5C9ED2F4“ Pin „21“ von „“ zu "Net-(U1-Pad21)".

Ändere Netzname von Footprint „U11:/5C8BBC9A/5CC0C21D“ Pin „4“ von „“ zu "Net-(C46-Pad1)".

Ändere Netzname von Footprint „U1:/5C8BBC94/5C9ED2F4“ Pin „22“ von „“ zu "Net-(C10-Pad1)".

Ändere Netzname von Footprint „U11:/5C8BBC9A/5CC0C21D“ Pin „5“ von „“ zu "Net-(C52-Pad2)".

Ändere Netzname von Footprint „U1:/5C8BBC94/5C9ED2F4“ Pin „23“ von „“ zu "Net-(U1-Pad23)".

Ändere Netzname von Footprint „U11:/5C8BBC9A/5CC0C21D“ Pin „8“ von „“ zu "GND".

Ändere Netzname von Footprint „U1:/5C8BBC94/5C9ED2F4“ Pin „24“ von „“ zu "Net-(U1-Pad24)".

Ändere Netzname von Footprint „U11:/5C8BBC9A/5CC0C21D“ Pin „9“ von „“ zu "Net-(C47-Pad1)".

Ändere Netzname von Footprint „U1:/5C8BBC94/5C9ED2F4“ Pin „29“ von „“ zu "Net-(U1-Pad29)".

Ändere Netzname von Footprint „U11:/5C8BBC9A/5CC0C21D“ Pin „10“ von „“ zu "Net-(C50-Pad2)".

Ändere Netzname von Footprint „U1:/5C8BBC94/5C9ED2F4“ Pin „26“ von „“ zu "Net-(U1-Pad26)".

Ändere Netzname von Footprint „U11:/5C8BBC9A/5CC0C21D“ Pin „11“ von „“ zu "Net-(C50-Pad1)".

Ändere Netzname von Footprint „U1:/5C8BBC94/5C9ED2F4“ Pin „27“ von „“ zu "GND".

Ändere Netzname von Footprint „U11:/5C8BBC9A/5CC0C21D“ Pin „12“ von „“ zu "GND".

Ändere Netzname von Footprint „U1:/5C8BBC94/5C9ED2F4“ Pin „28“ von „“ zu "+3V3".

Ändere Netzname von Footprint „U10:/5C8BBC9A/5CA4BA4B“ Pin „11“ von „“ zu "Net-(C35-Pad1)".

Füge neues Bauteil „D13:/5C9E4308/5CA2F87E“ mit Footprint „Package_TO_SOT_SMD:SOT-353_SC-70-5“ hinzu.

Ändere Netzname von Footprint „U1:/5C8BBC94/5C9ED2F4“ Pin „47“ von „“ zu "Net-(U1-Pad47)".

Ändere Netzname von Footprint „D12:/5C9E4308/5CA2F7A2“ Pin „5“ von „“ zu "Net-(D12-Pad5)".

Ändere Netzname von Footprint „U1:/5C8BBC94/5C9ED2F4“ Pin „48“ von „“ zu "Net-(U1-Pad48)".

Ändere Netzname von Footprint „U9:/5C8BBC9A/5CA4B9FD“ Pin „1“ von „“ zu "+BATT".

Ändere Netzname von Footprint „D13:/5C9E4308/5CA2F87E“ Pin „5“ von „“ zu "Net-(D13-Pad5)".

Ändere Netzname von Footprint „D13:/5C9E4308/5CA2F87E“ Pin „4“ von „“ zu "Net-(D13-Pad4)".

Ändere Netzname von Footprint „D13:/5C9E4308/5CA2F87E“ Pin „2“ von „“ zu "GND".

Ändere Netzname von Footprint „D13:/5C9E4308/5CA2F87E“ Pin „3“ von „“ zu "Net-(D13-Pad3)".

Ändere Netzname von Footprint „D13:/5C9E4308/5CA2F87E“ Pin „1“ von „“ zu "Net-(D13-Pad1)".

Füge neues Bauteil „U10:/5C8BBC9A/5CA4BA4B“ mit Footprint „Package_DFN_QFN:DFN-12-1EP_3x3mm_P0.5mm_EP2.05x2.86mm“ hinzu.

Ändere Netzname von Footprint „U9:/5C8BBC9A/5CA4B9FD“ Pin „2“ von „“ zu "Net-(Q1-Pad1)".

Ändere Netzname von Footprint „D12:/5C9E4308/5CA2F7A2“ Pin „1“ von „“ zu "Net-(D12-Pad1)".

Ändere Netzname von Footprint „D12:/5C9E4308/5CA2F7A2“ Pin „3“ von „“ zu "Net-(D12-Pad3)".

Ändere Netzname von Footprint „D12:/5C9E4308/5CA2F7A2“ Pin „2“ von „“ zu "GND".

Ändere Netzname von Footprint „D12:/5C9E4308/5CA2F7A2“ Pin „4“ von „“ zu "Net-(D12-Pad4)".

Ändere Netzname von Footprint „U3:/5C8BBC97/5C8BC1B4“ Pin „4“ von „“ zu "RxD-LIN1".

Füge neues Bauteil „D12:/5C9E4308/5CA2F7A2“ mit Footprint „Package_TO_SOT_SMD:SOT-353_SC-70-5“ hinzu.

Ändere Netzname von Footprint „U9:/5C8BBC9A/5CA4B9FD“ Pin „3“ von „“ zu "Net-(U9-Pad3)".

Ändere Netzname von Footprint „U1:/5C8BBC94/5C9ED2F4“ Pin „42“ von „“ zu "QuadSPI_NCS".

Ändere Netzname von Footprint „U1:/5C8BBC94/5C9ED2F4“ Pin „38“ von „“ zu "Net-(U1-Pad38)".

Ändere Netzname von Footprint „U10:/5C8BBC9A/5CA4BA4B“ Pin „10“ von „“ zu "Net-(C35-Pad2)".

Ändere Netzname von Footprint „U1:/5C8BBC94/5C9ED2F4“ Pin „39“ von „“ zu "Net-(U1-Pad39)".

Ändere Netzname von Footprint „U10:/5C8BBC9A/5CA4BA4B“ Pin „9“ von „“ zu "GND".

Ändere Netzname von Footprint „U1:/5C8BBC94/5C9ED2F4“ Pin „40“ von „“ zu "Net-(U1-Pad40)".

Ändere Netzname von Footprint „U10:/5C8BBC9A/5CA4BA4B“ Pin „8“ von „“ zu "GND".

Ändere Netzname von Footprint „U1:/5C8BBC94/5C9ED2F4“ Pin „41“ von „“ zu "QuadSPI_CLK".

Ändere Netzname von Footprint „U10:/5C8BBC9A/5CA4BA4B“ Pin „5“ von „“ zu "GND".

Ändere Netzname von Footprint „U11:/5C8BBC9A/5CC0C21D“ Pin „3“ von „“ zu "Net-(U11-Pad3)".

Ändere Netzname von Footprint „U10:/5C8BBC9A/5CA4BA4B“ Pin „4“ von „“ zu "Net-(C31-Pad1)".

Ändere Netzname von Footprint „U1:/5C8BBC94/5C9ED2F4“ Pin „43“ von „“ zu "QuadSPI_IO0".

Ändere Netzname von Footprint „U10:/5C8BBC9A/5CA4BA4B“ Pin „3“ von „“ zu "Net-(U10-Pad3)".

Ändere Netzname von Footprint „U1:/5C8BBC94/5C9ED2F4“ Pin „44“ von „“ zu "QuadSPI_IO1".

Ändere Netzname von Footprint „U10:/5C8BBC9A/5CA4BA4B“ Pin „2“ von „“ zu "Net-(Q2-Pad1)".

Ändere Netzname von Footprint „U1:/5C8BBC94/5C9ED2F4“ Pin „45“ von „“ zu "QuadSPI_IO2".

Ändere Netzname von Footprint „U10:/5C8BBC9A/5CA4BA4B“ Pin „1“ von „“ zu "+BATT".

Ändere Netzname von Footprint „U1:/5C8BBC94/5C9ED2F4“ Pin „46“ von „“ zu "QuadSPI_IO3".

Ändere Netzname von Footprint „U12:/5C8BBC9A/5CA4BB0F“ Pin „19“ von „“ zu "Net-(R32-Pad1)".

Füge neues Bauteil „U13:/5C8BC88B/5CAB8BB3“ mit Footprint „RF_Module:ESP-12E“ hinzu.

Ändere Netzname von Footprint „U13:/5C8BC88B/5CAB8BB3“ Pin „20“ von „“ zu "Net-(U13-Pad20)".

Ändere Netzname von Footprint „U12:/5C8BBC9A/5CA4BB0F“ Pin „25“ von „“ zu "GND".

Ändere Netzname von Footprint „U12:/5C8BBC9A/5CA4BB0F“ Pin „24“ von „“ zu "Net-(C48-Pad1)".

Ändere Netzname von Footprint „U12:/5C8BBC9A/5CA4BB0F“ Pin „23“ von „“ zu "Net-(C48-Pad1)".

Ändere Netzname von Footprint „U12:/5C8BBC9A/5CA4BB0F“ Pin „22“ von „“ zu "Net-(C48-Pad2)".

Ändere Netzname von Footprint „U12:/5C8BBC9A/5CA4BB0F“ Pin „21“ von „“ zu "GND".

Ändere Netzname von Footprint „U12:/5C8BBC9A/5CA4BB0F“ Pin „20“ von „“ zu "Net-(R35-Pad2)".

Ändere Netzname von Footprint „U13:/5C8BC88B/5CAB8BB3“ Pin „19“ von „“ zu "Net-(U13-Pad19)".

Ändere Netzname von Footprint „U12:/5C8BBC9A/5CA4BB0F“ Pin „18“ von „“ zu "Net-(R38-Pad2)".

Ändere Netzname von Footprint „U12:/5C8BBC9A/5CA4BB0F“ Pin „17“ von „“ zu "Net-(U12-Pad17)".

Füge neues Bauteil „U1:/5C8BBC94/5C9ED2F4“ mit Footprint „Package_QFP:LQFP-100_14x14mm_P0.5mm“ hinzu.

Ändere Netzname von Footprint „U12:/5C8BBC9A/5CA4BB0F“ Pin „16“ von „“ zu "Net-(C44-Pad1)".

Ändere Netzname von Footprint „U1:/5C8BBC94/5C9ED2F4“ Pin „1“ von „“ zu "Net-(U1-Pad1)".

Ändere Netzname von Footprint „U12:/5C8BBC9A/5CA4BB0F“ Pin „15“ von „“ zu "Net-(U12-Pad15)".

Ändere Netzname von Footprint „U1:/5C8BBC94/5C9ED2F4“ Pin „2“ von „“ zu "Net-(U1-Pad2)".

Ändere Netzname von Footprint „U12:/5C8BBC9A/5CA4BB0F“ Pin „14“ von „“ zu "Net-(U12-Pad14)".

Ändere Netzname von Footprint „U13:/5C8BC88B/5CAB8BB3“ Pin „9“ von „“ zu "Net-(U13-Pad9)".

Ändere Netzname von Footprint „U13:/5C8BC88B/5CAB8BB3“ Pin „17“ von „“ zu "Net-(U13-Pad17)".

Ändere Netzname von Footprint „U13:/5C8BC88B/5CAB8BB3“ Pin „16“ von „“ zu "Net-(U13-Pad16)".

Ändere Netzname von Footprint „U13:/5C8BC88B/5CAB8BB3“ Pin „15“ von „“ zu "GND".

Ändere Netzname von Footprint „U13:/5C8BC88B/5CAB8BB3“ Pin „14“ von „“ zu "Net-(U13-Pad14)".

Ändere Netzname von Footprint „U13:/5C8BC88B/5CAB8BB3“ Pin „13“ von „“ zu "Net-(U13-Pad13)".

Ändere Netzname von Footprint „U13:/5C8BC88B/5CAB8BB3“ Pin „12“ von „“ zu "Net-(U13-Pad12)".

Ändere Netzname von Footprint „U13:/5C8BC88B/5CAB8BB3“ Pin „11“ von „“ zu "Net-(U13-Pad11)".

Ändere Netzname von Footprint „U13:/5C8BC88B/5CAB8BB3“ Pin „10“ von „“ zu "Net-(U13-Pad10)".

Ändere Netzname von Footprint „U13:/5C8BC88B/5CAB8BB3“ Pin „21“ von „“ zu "Net-(U13-Pad21)".

Ändere Netzname von Footprint „U13:/5C8BC88B/5CAB8BB3“ Pin „8“ von „“ zu "Net-(C60-Pad1)".

Ändere Netzname von Footprint „U13:/5C8BC88B/5CAB8BB3“ Pin „7“ von „“ zu "Net-(U13-Pad7)".

Ändere Netzname von Footprint „U13:/5C8BC88B/5CAB8BB3“ Pin „6“ von „“ zu "Net-(U13-Pad6)".

Ändere Netzname von Footprint „U13:/5C8BC88B/5CAB8BB3“ Pin „5“ von „“ zu "Net-(U13-Pad5)".

Ändere Netzname von Footprint „U13:/5C8BC88B/5CAB8BB3“ Pin „4“ von „“ zu "Net-(U13-Pad4)".

Ändere Netzname von Footprint „U13:/5C8BC88B/5CAB8BB3“ Pin „3“ von „“ zu "ESP_Enable".

Ändere Netzname von Footprint „U13:/5C8BC88B/5CAB8BB3“ Pin „2“ von „“ zu "Net-(U13-Pad2)".

Ändere Netzname von Footprint „U13:/5C8BC88B/5CAB8BB3“ Pin „1“ von „“ zu "ESP_Reset".

Ändere Netzname von Footprint „U12:/5C8BBC9A/5CA4BB0F“ Pin „1“ von „“ zu "Net-(C48-Pad1)".

Ändere Netzname von Footprint „U1:/5C8BBC94/5C9ED2F4“ Pin „12“ von „“ zu "Net-(C2-Pad1)".

Ändere Netzname von Footprint „U13:/5C8BC88B/5CAB8BB3“ Pin „22“ von „“ zu "Net-(U13-Pad22)".

Ändere Netzname von Footprint „U12:/5C8BBC9A/5CA4BB0F“ Pin „4“ von „“ zu "Net-(U12-Pad4)".

Ändere Netzname von Footprint „U1:/5C8BBC94/5C9ED2F4“ Pin „13“ von „“ zu "Net-(C3-Pad1)".

Ändere Netzname von Footprint „U12:/5C8BBC9A/5CA4BB0F“ Pin „3“ von „“ zu "GND".

Ändere Netzname von Footprint „U1:/5C8BBC94/5C9ED2F4“ Pin „14“ von „“ zu "Net-(C1-Pad1)".

Ändere Netzname von Footprint „U12:/5C8BBC9A/5CA4BB0F“ Pin „2“ von „“ zu "GND".

Ändere Netzname von Footprint „U1:/5C8BBC94/5C9ED2F4“ Pin „15“ von „“ zu "Net-(U1-Pad15)".

Ändere Netzname von Footprint „U12:/5C8BBC9A/5CA4BB0F“ Pin „5“ von „“ zu "+BATT".

Ändere Netzname von Footprint „U1:/5C8BBC94/5C9ED2F4“ Pin „16“ von „“ zu "Net-(U1-Pad16)".

Füge neues Bauteil „U12:/5C8BBC9A/5CA4BB0F“ mit Footprint „Package_DFN_QFN:QFN-24-1EP_4x5mm_P0.5mm_EP2.65x3.65mm“ hinzu.

Ändere Netzname von Footprint „U1:/5C8BBC94/5C9ED2F4“ Pin „17“ von „“ zu "Net-(U1-Pad17)".

Ändere Netzname von Footprint „U1:/5C8BBC94/5C9ED2F4“ Pin „18“ von „“ zu "Net-(U1-Pad18)".

Ändere Netzname von Footprint „U11:/5C8BBC9A/5CC0C21D“ Pin „1“ von „“ zu "+BATT".

Ändere Netzname von Footprint „U1:/5C8BBC94/5C9ED2F4“ Pin „19“ von „“ zu "Net-(U1-Pad19)".

Ändere Netzname von Footprint „U11:/5C8BBC9A/5CC0C21D“ Pin „2“ von „“ zu "Net-(Q4-Pad1)".

Ändere Netzname von Footprint „U1:/5C8BBC94/5C9ED2F4“ Pin „20“ von „“ zu "Net-(U1-Pad20)".

Ändere Netzname von Footprint „U1:/5C8BBC94/5C9ED2F4“ Pin „7“ von „“ zu "Net-(U1-Pad7)".

Ändere Netzname von Footprint „U1:/5C8BBC94/5C9ED2F4“ Pin „3“ von „“ zu "Net-(U1-Pad3)".

Ändere Netzname von Footprint „U12:/5C8BBC9A/5CA4BB0F“ Pin „13“ von „“ zu "Net-(U12-Pad13)".

Ändere Netzname von Footprint „U1:/5C8BBC94/5C9ED2F4“ Pin „4“ von „“ zu "Net-(U1-Pad4)".

Ändere Netzname von Footprint „U12:/5C8BBC9A/5CA4BB0F“ Pin „12“ von „“ zu "Net-(C51-Pad2)".

Ändere Netzname von Footprint „U1:/5C8BBC94/5C9ED2F4“ Pin „5“ von „“ zu "Net-(U1-Pad5)".

Ändere Netzname von Footprint „U12:/5C8BBC9A/5CA4BB0F“ Pin „11“ von „“ zu "GND".

Ändere Netzname von Footprint „U1:/5C8BBC94/5C9ED2F4“ Pin „6“ von „“ zu "Net-(U1-Pad6)".

Ändere Netzname von Footprint „U12:/5C8BBC9A/5CA4BB0F“ Pin „10“ von „“ zu "Net-(Q3-Pad1)".

Ändere Netzname von Footprint „U13:/5C8BC88B/5CAB8BB3“ Pin „18“ von „“ zu "ESP_Boot".

Ändere Netzname von Footprint „U12:/5C8BBC9A/5CA4BB0F“ Pin „9“ von „“ zu "+BATT".

Ändere Netzname von Footprint „U1:/5C8BBC94/5C9ED2F4“ Pin „8“ von „“ zu "Net-(C12-Pad2)".

Ändere Netzname von Footprint „U12:/5C8BBC9A/5CA4BB0F“ Pin „8“ von „“ zu "Net-(U12-Pad8)".

Ändere Netzname von Footprint „U1:/5C8BBC94/5C9ED2F4“ Pin „9“ von „“ zu "Net-(C13-Pad2)".

Ändere Netzname von Footprint „U12:/5C8BBC9A/5CA4BB0F“ Pin „7“ von „“ zu "+BATT".

Ändere Netzname von Footprint „U1:/5C8BBC94/5C9ED2F4“ Pin „10“ von „“ zu "GND".

Ändere Netzname von Footprint „U12:/5C8BBC9A/5CA4BB0F“ Pin „6“ von „“ zu "+BATT".

Ändere Netzname von Footprint „U1:/5C8BBC94/5C9ED2F4“ Pin „11“ von „“ zu "+3V3".

Ändere Netzname von Footprint „U6:/5C8BBC97/5C8BC5DF“ Pin „8“ von „“ zu "STB-CAN".

Ändere Netzname von Footprint „U1:/5C8BBC94/5C9ED2F4“ Pin „87“ von „“ zu "Net-(U1-Pad87)".

Ändere Netzname von Footprint „U6:/5C8BBC97/5C8BC5DF“ Pin „4“ von „“ zu "RxD-CAN".

Ändere Netzname von Footprint „U1:/5C8BBC94/5C9ED2F4“ Pin „88“ von „“ zu "Net-(U1-Pad88)".

Ändere Netzname von Footprint „U6:/5C8BBC97/5C8BC5DF“ Pin „5“ von „“ zu "+3V3".

Ändere Netzname von Footprint „U1:/5C8BBC94/5C9ED2F4“ Pin „89“ von „“ zu "JTAG_TDO".

Ändere Netzname von Footprint „U6:/5C8BBC97/5C8BC5DF“ Pin „6“ von „“ zu "Net-(D10-Pad1)".

Ändere Netzname von Footprint „U1:/5C8BBC94/5C9ED2F4“ Pin „90“ von „“ zu "JTAG_RES".

Ändere Netzname von Footprint „U6:/5C8BBC97/5C8BC5DF“ Pin „7“ von „“ zu "Net-(D10-Pad2)".

Ändere Netzname von Footprint „U1:/5C8BBC94/5C9ED2F4“ Pin „91“ von „“ zu "Net-(U1-Pad91)".

Ändere Netzname von Footprint „U6:/5C8BBC97/5C8BC5DF“ Pin „3“ von „“ zu "+5V".

Ändere Netzname von Footprint „U1:/5C8BBC94/5C9ED2F4“ Pin „92“ von „“ zu "Net-(U1-Pad92)".

Füge neues Bauteil „U6:/5C8BBC97/5C8BC5DF“ mit Footprint „Package_SO:SOIC-8_3.9x4.9mm_P1.27mm“ hinzu.

Ändere Netzname von Footprint „U1:/5C8BBC94/5C9ED2F4“ Pin „93“ von „“ zu "Net-(U1-Pad93)".

Ändere Netzname von Footprint „U1:/5C8BBC94/5C9ED2F4“ Pin „94“ von „“ zu "Net-(U1-Pad94)".

Ändere Netzname von Footprint „U5:/5C8BBC97/5C8BC4A4“ Pin „8“ von „“ zu "Net-(U5-Pad8)".

Ändere Netzname von Footprint „U1:/5C8BBC94/5C9ED2F4“ Pin „95“ von „“ zu "SCL-1WIRE".

Ändere Netzname von Footprint „U5:/5C8BBC97/5C8BC4A4“ Pin „7“ von „“ zu "+BATT".

Ändere Netzname von Footprint „U1:/5C8BBC94/5C9ED2F4“ Pin „96“ von „“ zu "SDA-1WIRE".

Ändere Netzname von Footprint „U7:/5C8BBC97/5C8BC743“ Pin „1“ von „“ zu "RxD-RS485".

Ändere Netzname von Footprint „U1:/5C8BBC94/5C9ED2F4“ Pin „77“ von „“ zu "JTAG_TDI".

Ändere Netzname von Footprint „U1:/5C8BBC94/5C9ED2F4“ Pin „78“ von „“ zu "Net-(U1-Pad78)".

Ändere Netzname von Footprint „U7:/5C8BBC97/5C8BC743“ Pin „4“ von „“ zu "TxD-RS485".

Ändere Netzname von Footprint „U1:/5C8BBC94/5C9ED2F4“ Pin „79“ von „“ zu "Net-(U1-Pad79)".

Ändere Netzname von Footprint „U7:/5C8BBC97/5C8BC743“ Pin „3“ von „“ zu "DE-RS485".

Ändere Netzname von Footprint „U1:/5C8BBC94/5C9ED2F4“ Pin „80“ von „“ zu "Net-(U1-Pad80)".

Ändere Netzname von Footprint „U7:/5C8BBC97/5C8BC743“ Pin „2“ von „“ zu "RE-RS485".

Ändere Netzname von Footprint „U1:/5C8BBC94/5C9ED2F4“ Pin „81“ von „“ zu "RxD-CAN".

Ändere Netzname von Footprint „U5:/5C8BBC97/5C8BC4A4“ Pin „6“ von „“ zu "Net-(C21-Pad1)".

Ändere Netzname von Footprint „U1:/5C8BBC94/5C9ED2F4“ Pin „82“ von „“ zu "TxD-CAN".

Füge neues Bauteil „U7:/5C8BBC97/5C8BC743“ mit Footprint „Package_SO:SOIC-8_3.9x4.9mm_P1.27mm“ hinzu.

Ändere Netzname von Footprint „U1:/5C8BBC94/5C9ED2F4“ Pin „83“ von „“ zu "Net-(U1-Pad83)".

Ändere Netzname von Footprint „U1:/5C8BBC94/5C9ED2F4“ Pin „84“ von „“ zu "Net-(U1-Pad84)".

Ändere Netzname von Footprint „U6:/5C8BBC97/5C8BC5DF“ Pin „1“ von „“ zu "TxD-CAN".

Ändere Netzname von Footprint „U1:/5C8BBC94/5C9ED2F4“ Pin „85“ von „“ zu "Net-(U1-Pad85)".

Ändere Netzname von Footprint „U6:/5C8BBC97/5C8BC5DF“ Pin „2“ von „“ zu "GND".

Ändere Netzname von Footprint „U1:/5C8BBC94/5C9ED2F4“ Pin „86“ von „“ zu "Net-(U1-Pad86)".

Füge neues Bauteil „U4:/5C8BBC97/5C8BC3EB“ mit Footprint „Package_SO:SOIC-8_3.9x4.9mm_P1.27mm“ hinzu.

Ändere Netzname von Footprint „U4:/5C8BBC97/5C8BC3EB“ Pin „5“ von „“ zu "GND".

Ändere Netzname von Footprint „U2:/5C8BBC94/5C9E12E3“ Pin „5“ von „“ zu "QuadSPI_IO0".

Ändere Netzname von Footprint „U4:/5C8BBC97/5C8BC3EB“ Pin „4“ von „“ zu "RxD-LIN2".

Ändere Netzname von Footprint „U2:/5C8BBC94/5C9E12E3“ Pin „6“ von „“ zu "QuadSPI_CLK".

Ändere Netzname von Footprint „U4:/5C8BBC97/5C8BC3EB“ Pin „3“ von „“ zu "Net-(U4-Pad3)".

Ändere Netzname von Footprint „U2:/5C8BBC94/5C9E12E3“ Pin „7“ von „“ zu "QuadSPI_IO3".

Ändere Netzname von Footprint „U4:/5C8BBC97/5C8BC3EB“ Pin „2“ von „“ zu "SLP-LIN2".

Ändere Netzname von Footprint „U2:/5C8BBC94/5C9E12E3“ Pin „8“ von „“ zu "+3V3".

Ändere Netzname von Footprint „U4:/5C8BBC97/5C8BC3EB“ Pin „1“ von „“ zu "TxD-LIN2".

Ändere Netzname von Footprint „U2:/5C8BBC94/5C9E12E3“ Pin „4“ von „“ zu "GND".

Füge neues Bauteil „U3:/5C8BBC97/5C8BC1B4“ mit Footprint „Package_SO:SOIC-8_3.9x4.9mm_P1.27mm“ hinzu.

Ändere Netzname von Footprint „U3:/5C8BBC97/5C8BC1B4“ Pin „1“ von „“ zu "TxD-LIN1".

Ändere Netzname von Footprint „U3:/5C8BBC97/5C8BC1B4“ Pin „8“ von „“ zu "Net-(U3-Pad8)".

Ändere Netzname von Footprint „U3:/5C8BBC97/5C8BC1B4“ Pin „2“ von „“ zu "SLP-LIN1".

Ändere Netzname von Footprint „U3:/5C8BBC97/5C8BC1B4“ Pin „7“ von „“ zu "+BATT".

Ändere Netzname von Footprint „U3:/5C8BBC97/5C8BC1B4“ Pin „6“ von „“ zu "Net-(C19-Pad1)".

Ändere Netzname von Footprint „U3:/5C8BBC97/5C8BC1B4“ Pin „3“ von „“ zu "Net-(U3-Pad3)".

Ändere Netzname von Footprint „U3:/5C8BBC97/5C8BC1B4“ Pin „5“ von „“ zu "GND".

Ändere Netzname von Footprint „U5:/5C8BBC97/5C8BC4A4“ Pin „1“ von „“ zu "TxD-LIN3".

Ändere Netzname von Footprint „U1:/5C8BBC94/5C9ED2F4“ Pin „97“ von „“ zu "Net-(U1-Pad97)".

Ändere Netzname von Footprint „U5:/5C8BBC97/5C8BC4A4“ Pin „5“ von „“ zu "GND".

Ändere Netzname von Footprint „U1:/5C8BBC94/5C9ED2F4“ Pin „98“ von „“ zu "Net-(U1-Pad98)".

Ändere Netzname von Footprint „U5:/5C8BBC97/5C8BC4A4“ Pin „4“ von „“ zu "RxD-LIN3".

Ändere Netzname von Footprint „U1:/5C8BBC94/5C9ED2F4“ Pin „99“ von „“ zu "GND".

Ändere Netzname von Footprint „U5:/5C8BBC97/5C8BC4A4“ Pin „3“ von „“ zu "Net-(U5-Pad3)".

Ändere Netzname von Footprint „U1:/5C8BBC94/5C9ED2F4“ Pin „100“ von „“ zu "+3V3".

Ändere Netzname von Footprint „U5:/5C8BBC97/5C8BC4A4“ Pin „2“ von „“ zu "SLP-LIN3".

Ändere Netzname von Footprint „U9:/5C8BBC9A/5CA4B9FD“ Pin „4“ von „“ zu "Net-(C30-Pad1)".

Füge neues Bauteil „U5:/5C8BBC97/5C8BC4A4“ mit Footprint „Package_SO:SOIC-8_3.9x4.9mm_P1.27mm“ hinzu.

Füge neues Bauteil „U2:/5C8BBC94/5C9E12E3“ mit Footprint „Package_SO:TSSOP-8_4.4x3mm_P0.65mm“ hinzu.

Ändere Netzname von Footprint „U2:/5C8BBC94/5C9E12E3“ Pin „1“ von „“ zu "QuadSPI_NCS".

Ändere Netzname von Footprint „U4:/5C8BBC97/5C8BC3EB“ Pin „8“ von „“ zu "Net-(U4-Pad8)".

Ändere Netzname von Footprint „U2:/5C8BBC94/5C9E12E3“ Pin „2“ von „“ zu "QuadSPI_IO1".

Ändere Netzname von Footprint „U4:/5C8BBC97/5C8BC3EB“ Pin „7“ von „“ zu "+BATT".

Ändere Netzname von Footprint „U2:/5C8BBC94/5C9E12E3“ Pin „3“ von „“ zu "QuadSPI_IO2".

Ändere Netzname von Footprint „U4:/5C8BBC97/5C8BC3EB“ Pin „6“ von „“ zu "Net-(C20-Pad1)".

Ändere Netzname von Footprint „U9:/5C8BBC9A/5CA4B9FD“ Pin „7“ von „“ zu "Net-(R24-Pad2)".

Ändere Netzname von Footprint „D3:/5C8BBC94/5CA2F4B9“ Pin „1“ von „“ zu "Net-(D3-Pad1)".

Füge neues Bauteil „D3:/5C8BBC94/5CA2F4B9“ mit Footprint „Package_TO_SOT_SMD:SOT-353_SC-70-5“ hinzu.

Ändere Netzname von Footprint „U9:/5C8BBC9A/5CA4B9FD“ Pin „6“ von „“ zu "Net-(R19-Pad1)".

Ändere Netzname von Footprint „D2:/5C8BBC94/5CAB197E“ Pin „5“ von „“ zu "Disp_Audio_L".

Ändere Netzname von Footprint „D2:/5C8BBC94/5CAB197E“ Pin „4“ von „“ zu "Disp_PD".

Ändere Netzname von Footprint „D2:/5C8BBC94/5CAB197E“ Pin „2“ von „“ zu "GND".

Ändere Netzname von Footprint „D2:/5C8BBC94/5CAB197E“ Pin „3“ von „“ zu "Disp_INT".

Ändere Netzname von Footprint „D2:/5C8BBC94/5CAB197E“ Pin „1“ von „“ zu "Disp_CS".

Füge neues Bauteil „D2:/5C8BBC94/5CAB197E“ mit Footprint „Package_TO_SOT_SMD:SOT-353_SC-70-5“ hinzu.

Ändere Netzname von Footprint „D3:/5C8BBC94/5CA2F4B9“ Pin „3“ von „“ zu "USB_D+".

Ändere Netzname von Footprint „D1:/5C8BBC94/5CAADD43“ Pin „1“ von „“ zu "+5VL".

Ändere Netzname von Footprint „D1:/5C8BBC94/5CAADD43“ Pin „3“ von „“ zu "Disp_SCK".

Ändere Netzname von Footprint „D1:/5C8BBC94/5CAADD43“ Pin „2“ von „“ zu "GND".

Ändere Netzname von Footprint „D1:/5C8BBC94/5CAADD43“ Pin „4“ von „“ zu "Disp_MISO".

Ändere Netzname von Footprint „D1:/5C8BBC94/5CAADD43“ Pin „5“ von „“ zu "Disp_MOSI".

Füge neues Bauteil „D1:/5C8BBC94/5CAADD43“ mit Footprint „Package_TO_SOT_SMD:SOT-353_SC-70-5“ hinzu.

Füge neues Bauteil „U9:/5C8BBC9A/5CA4B9FD“ mit Footprint „Package_DFN_QFN:DFN-12-1EP_3x3mm_P0.5mm_EP2.05x2.86mm“ hinzu.

Ändere Netzname von Footprint „U1:/5C8BBC94/5C9ED2F4“ Pin „57“ von „“ zu "Net-(U1-Pad57)".

Ändere Netzname von Footprint „U1:/5C8BBC94/5C9ED2F4“ Pin „54“ von „“ zu "Net-(U1-Pad54)".

Ändere Netzname von Footprint „U1:/5C8BBC94/5C9ED2F4“ Pin „49“ von „“ zu "GND".

Ändere Netzname von Footprint „U1:/5C8BBC94/5C9ED2F4“ Pin „50“ von „“ zu "+3V3".

Ändere Netzname von Footprint „U9:/5C8BBC9A/5CA4B9FD“ Pin „5“ von „“ zu "Net-(C36-Pad2)".

Ändere Netzname von Footprint „U1:/5C8BBC94/5C9ED2F4“ Pin „51“ von „“ zu "Net-(U1-Pad51)".

Ändere Netzname von Footprint „U9:/5C8BBC9A/5CA4B9FD“ Pin „8“ von „“ zu "GND".

Ändere Netzname von Footprint „U1:/5C8BBC94/5C9ED2F4“ Pin „52“ von „“ zu "Net-(U1-Pad52)".

Ändere Netzname von Footprint „U9:/5C8BBC9A/5CA4B9FD“ Pin „9“ von „“ zu "Net-(C32-Pad1)".

Ändere Netzname von Footprint „U1:/5C8BBC94/5C9ED2F4“ Pin „53“ von „“ zu "Net-(U1-Pad53)".

Ändere Netzname von Footprint „U9:/5C8BBC9A/5CA4B9FD“ Pin „10“ von „“ zu "Net-(C34-Pad2)".

Ändere Netzname von Footprint „U1:/5C8BBC94/5C9ED2F4“ Pin „76“ von „“ zu "JTAG_TCK".

Ändere Netzname von Footprint „U9:/5C8BBC9A/5CA4B9FD“ Pin „11“ von „“ zu "Net-(C34-Pad1)".

Ändere Netzname von Footprint „U1:/5C8BBC94/5C9ED2F4“ Pin „55“ von „“ zu "Net-(U1-Pad55)".

Ändere Netzname von Footprint „U9:/5C8BBC9A/5CA4B9FD“ Pin „12“ von „“ zu "GND".

Ändere Netzname von Footprint „U1:/5C8BBC94/5C9ED2F4“ Pin „56“ von „“ zu "Net-(U1-Pad56)".

Ändere Netzname von Footprint „U9:/5C8BBC9A/5CA4B9FD“ Pin „13“ von „“ zu "GND".

Ändere Netzname von Footprint „D3:/5C8BBC94/5CA2F4B9“ Pin „5“ von „“ zu "USB_ID".

Ändere Netzname von Footprint „D3:/5C8BBC94/5CA2F4B9“ Pin „4“ von „“ zu "USB_D-".

Ändere Netzname von Footprint „D3:/5C8BBC94/5CA2F4B9“ Pin „2“ von „“ zu "GND".

Ändere Netzname von Footprint „U1:/5C8BBC94/5C9ED2F4“ Pin „71“ von „“ zu "USB_D+".

Ändere Netzname von Footprint „U1:/5C8BBC94/5C9ED2F4“ Pin „66“ von „“ zu "Net-(U1-Pad66)".

Ändere Netzname von Footprint „U8:/5C8BBC9A/5CA4B92D“ Pin „5“ von „“ zu "GND".

Ändere Netzname von Footprint „U1:/5C8BBC94/5C9ED2F4“ Pin „67“ von „“ zu "USB_SOF".

Ändere Netzname von Footprint „U8:/5C8BBC9A/5CA4B92D“ Pin „4“ von „“ zu "Net-(C29-Pad1)".

Ändere Netzname von Footprint „U1:/5C8BBC94/5C9ED2F4“ Pin „68“ von „“ zu "Net-(U1-Pad68)".

Ändere Netzname von Footprint „U8:/5C8BBC9A/5CA4B92D“ Pin „3“ von „“ zu "PWR_Reset".

Ändere Netzname von Footprint „U1:/5C8BBC94/5C9ED2F4“ Pin „69“ von „“ zu "USB_ID".

Ändere Netzname von Footprint „U8:/5C8BBC9A/5CA4B92D“ Pin „2“ von „“ zu "Net-(R14-Pad2)".

Ändere Netzname von Footprint „U1:/5C8BBC94/5C9ED2F4“ Pin „70“ von „“ zu "USB_D-".

Ändere Netzname von Footprint „U8:/5C8BBC9A/5CA4B92D“ Pin „1“ von „“ zu "+BATT".

Ändere Netzname von Footprint „U8:/5C8BBC9A/5CA4B92D“ Pin „7“ von „“ zu "Net-(R22-Pad2)".

Füge neues Bauteil „U8:/5C8BBC9A/5CA4B92D“ mit Footprint „Package_DFN_QFN:DFN-12-1EP_3x3mm_P0.5mm_EP2.05x2.86mm“ hinzu.

Ändere Netzname von Footprint „U1:/5C8BBC94/5C9ED2F4“ Pin „72“ von „“ zu "JTAG_TMS".

Ändere Netzname von Footprint „U1:/5C8BBC94/5C9ED2F4“ Pin „73“ von „“ zu "Net-(U1-Pad73)".

Ändere Netzname von Footprint „U7:/5C8BBC97/5C8BC743“ Pin „8“ von „“ zu "+3V3".

Ändere Netzname von Footprint „U1:/5C8BBC94/5C9ED2F4“ Pin „74“ von „“ zu "GND".

Ändere Netzname von Footprint „U7:/5C8BBC97/5C8BC743“ Pin „7“ von „“ zu "Net-(R8-Pad2)".

Ändere Netzname von Footprint „U1:/5C8BBC94/5C9ED2F4“ Pin „75“ von „“ zu "+3V3".

Ändere Netzname von Footprint „U7:/5C8BBC97/5C8BC743“ Pin „6“ von „“ zu "Net-(R7-Pad2)".

Ändere Netzname von Footprint „U7:/5C8BBC97/5C8BC743“ Pin „5“ von „“ zu "GND".

Ändere Netzname von Footprint „U8:/5C8BBC9A/5CA4B92D“ Pin „8“ von „“ zu "GND".

Ändere Netzname von Footprint „U8:/5C8BBC9A/5CA4B92D“ Pin „6“ von „“ zu "Net-(R18-Pad1)".

Ändere Netzname von Footprint „U1:/5C8BBC94/5C9ED2F4“ Pin „60“ von „“ zu "Net-(U1-Pad60)".

Ändere Netzname von Footprint „U8:/5C8BBC9A/5CA4B92D“ Pin „13“ von „“ zu "GND".

Ändere Netzname von Footprint „U1:/5C8BBC94/5C9ED2F4“ Pin „61“ von „“ zu "Net-(U1-Pad61)".

Ändere Netzname von Footprint „U1:/5C8BBC94/5C9ED2F4“ Pin „59“ von „“ zu "Net-(U1-Pad59)".

Ändere Netzname von Footprint „U8:/5C8BBC9A/5CA4B92D“ Pin „12“ von „“ zu "GND".

Ändere Netzname von Footprint „U1:/5C8BBC94/5C9ED2F4“ Pin „62“ von „“ zu "Net-(U1-Pad62)".

Ändere Netzname von Footprint „U8:/5C8BBC9A/5CA4B92D“ Pin „11“ von „“ zu "Net-(C33-Pad1)".

Ändere Netzname von Footprint „U1:/5C8BBC94/5C9ED2F4“ Pin „63“ von „“ zu "Net-(U1-Pad63)".

Ändere Netzname von Footprint „U8:/5C8BBC9A/5CA4B92D“ Pin „10“ von „“ zu "Net-(C33-Pad2)".

Ändere Netzname von Footprint „U1:/5C8BBC94/5C9ED2F4“ Pin „64“ von „“ zu "Net-(U1-Pad64)".

Ändere Netzname von Footprint „U1:/5C8BBC94/5C9ED2F4“ Pin „58“ von „“ zu "Net-(U1-Pad58)".

Ändere Netzname von Footprint „U8:/5C8BBC9A/5CA4B92D“ Pin „9“ von „“ zu "GND".

Ändere Netzname von Footprint „U1:/5C8BBC94/5C9ED2F4“ Pin „65“ von „“ zu "Net-(U1-Pad65)".

Fehler: Neues Bauteil „R37:/5C8BBC9A/5CC0C197“ konnte nicht hinzugefügt werden, wegen fehlendem Footprint „“.

Fehler: Neues Bauteil „L1:/5C8BBC9A/5CA770C8“ konnte nicht hinzugefügt werden, wegen fehlendem Footprint „“.

Fehler: Neues Bauteil „Y1:/5C8BBC94/5CA1CF07“ konnte nicht hinzugefügt werden, wegen fehlendem Footprint „“.

Fehler: Neues Bauteil „U14:/5C9E4308/5C9E4327“ konnte nicht hinzugefügt werden, wegen fehlendem Footprint „21-0041B_16“.

Fehler: Neues Bauteil „R44:/5C9E4308/5CB09421“ konnte nicht hinzugefügt werden, wegen fehlendem Footprint „“.

Fehler: Neues Bauteil „R38:/5C8BBC9A/5CA4FF24“ konnte nicht hinzugefügt werden, wegen fehlendem Footprint „“.

Fehler: Neues Bauteil „Y2:/5C8BBC94/5CA1CD9F“ konnte nicht hinzugefügt werden, wegen fehlendem Footprint „“.

Fehler: Neues Bauteil „SW1:/5C8BBC94/5CA4B2AF“ konnte nicht hinzugefügt werden, wegen fehlendem Footprint „“.

Fehler: Neues Bauteil „R39:/5C8BBC9A/5CA4FFFE“ konnte nicht hinzugefügt werden, wegen fehlendem Footprint „“.

Fehler: Neues Bauteil „R47:/5C9E4308/5CB0B63D“ konnte nicht hinzugefügt werden, wegen fehlendem Footprint „“.

Fehler: Neues Bauteil „R40:/5C9E4308/5CB0822F“ konnte nicht hinzugefügt werden, wegen fehlendem Footprint „“.

Fehler: Neues Bauteil „R41:/5C9E4308/5CB0A108“ konnte nicht hinzugefügt werden, wegen fehlendem Footprint „“.

Fehler: Neues Bauteil „R46:/5C9E4308/5CB09A98“ konnte nicht hinzugefügt werden, wegen fehlendem Footprint „“.

Fehler: Neues Bauteil „R42:/5C9E4308/5CB08DA5“ konnte nicht hinzugefügt werden, wegen fehlendem Footprint „“.

Fehler: Neues Bauteil „R45:/5C9E4308/5CB0AFCE“ konnte nicht hinzugefügt werden, wegen fehlendem Footprint „“.

Fehler: Neues Bauteil „R43:/5C9E4308/5CB0A956“ konnte nicht hinzugefügt werden, wegen fehlendem Footprint „“.

Fehler: Es wurde kein Footprint für das Bauteil „C11“ definiert.

Fehler: Es wurde kein Footprint für das Bauteil „D4“ definiert.

Fehler: Es wurde kein Footprint für das Bauteil „D5“ definiert.

Fehler: Es wurde kein Footprint für das Bauteil „D6“ definiert.

Fehler: Es wurde kein Footprint für das Bauteil „C12“ definiert.

Fehler: Es wurde kein Footprint für das Bauteil „C7“ definiert.

Fehler: Es wurde kein Footprint für das Bauteil „C6“ definiert.

Fehler: Es wurde kein Footprint für das Bauteil „C5“ definiert.

Fehler: Es wurde kein Footprint für das Bauteil „C4“ definiert.

Fehler: Es wurde kein Footprint für das Bauteil „C10“ definiert.

Fehler: Es wurde kein Footprint für das Bauteil „C23“ definiert.

Fehler: Es wurde kein Footprint für das Bauteil „C9“ definiert.

Fehler: Es wurde kein Footprint für das Bauteil „Y2“ definiert.

Fehler: Es wurde kein Footprint für das Bauteil „Y1“ definiert.

Fehler: Es wurde kein Footprint für das Bauteil „D10“ definiert.

Fehler: Es wurde kein Footprint für das Bauteil „C13“ definiert.

Fehler: Es wurde kein Footprint für das Bauteil „C3“ definiert.

Fehler: Es wurde kein Footprint für das Bauteil „C2“ definiert.

Fehler: Es wurde kein Footprint für das Bauteil „C1“ definiert.

Fehler: Es wurde kein Footprint für das Bauteil „C16“ definiert.

Fehler: Es wurde kein Footprint für das Bauteil „R44“ definiert.

Fehler: Es wurde kein Footprint für das Bauteil „C19“ definiert.

Fehler: Es wurde kein Footprint für das Bauteil „C14“ definiert.

Fehler: Es wurde kein Footprint für das Bauteil „R4“ definiert.

Fehler: Es wurde kein Footprint für das Bauteil „R5“ definiert.

Fehler: Es wurde kein Footprint für das Bauteil „R6“ definiert.

Fehler: Es wurde kein Footprint für das Bauteil „R1“ definiert.

Fehler: Es wurde kein Footprint für das Bauteil „R2“ definiert.

Fehler: Es wurde kein Footprint für das Bauteil „R3“ definiert.

Fehler: Es wurde kein Footprint für das Bauteil „J3“ definiert.

Fehler: Es wurde kein Footprint für das Bauteil „C17“ definiert.

Fehler: Es wurde kein Footprint für das Bauteil „C18“ definiert.

Fehler: Es wurde kein Footprint für das Bauteil „C15“ definiert.

Fehler: Es wurde kein Footprint für das Bauteil „C20“ definiert.

Fehler: Es wurde kein Footprint für das Bauteil „C21“ definiert.

Fehler: Es wurde kein Footprint für das Bauteil „C22“ definiert.

Fehler: Es wurde kein Footprint für das Bauteil „C24“ definiert.

Fehler: Es wurde kein Footprint für das Bauteil „R11“ definiert.

Fehler: Es wurde kein Footprint für das Bauteil „R10“ definiert.

Fehler: Es wurde kein Footprint für das Bauteil „C30“ definiert.

Fehler: Es wurde kein Footprint für das Bauteil „C34“ definiert.

Fehler: Es wurde kein Footprint für das Bauteil „C27“ definiert.

Fehler: Es wurde kein Footprint für das Bauteil „R19“ definiert.

Fehler: Es wurde kein Footprint für das Bauteil „C37“ definiert.

Fehler: Es wurde kein Footprint für das Bauteil „L1“ definiert.

Fehler: Es wurde kein Footprint für das Bauteil „FB1“ definiert.

Fehler: Es wurde kein Footprint für das Bauteil „D11“ definiert.

Fehler: Es wurde kein Footprint für das Bauteil „R9“ definiert.

Fehler: Es wurde kein Footprint für das Bauteil „C8“ definiert.

Fehler: Es wurde kein Footprint für das Bauteil „R7“ definiert.

Fehler: Es wurde kein Footprint für das Bauteil „R8“ definiert.

Fehler: Es wurde kein Footprint für das Bauteil „C25“ definiert.

Fehler: Es wurde kein Footprint für das Bauteil „D8“ definiert.

Fehler: Es wurde kein Footprint für das Bauteil „D9“ definiert.

Fehler: Es wurde kein Footprint für das Bauteil „D7“ definiert.

Fehler: Es wurde kein Footprint für das Bauteil „R22“ definiert.

Fehler: Es wurde kein Footprint für das Bauteil „FB3“ definiert.

Fehler: Es wurde kein Footprint für das Bauteil „R38“ definiert.

Fehler: Es wurde kein Footprint für das Bauteil „J5“ definiert.

Fehler: Es wurde kein Footprint für das Bauteil „SW1“ definiert.

Fehler: Es wurde kein Footprint für das Bauteil „J4“ definiert.

Fehler: Es wurde kein Footprint für das Bauteil „J2“ definiert.

Fehler: Es wurde kein Footprint für das Bauteil „C38“ definiert.

Fehler: Es wurde kein Footprint für das Bauteil „C54“ definiert.

Fehler: Es wurde kein Footprint für das Bauteil „C57“ definiert.

Fehler: Es wurde kein Footprint für das Bauteil „L5“ definiert.

Fehler: Es wurde kein Footprint für das Bauteil „C48“ definiert.

Fehler: Es wurde kein Footprint für das Bauteil „R42“ definiert.

Fehler: Es wurde kein Footprint für das Bauteil „R39“ definiert.

Fehler: Es wurde kein Footprint für das Bauteil „R35“ definiert.

Fehler: Es wurde kein Footprint für das Bauteil „Q3“ definiert.

Fehler: Es wurde kein Footprint für das Bauteil „R28“ definiert.

Fehler: Es wurde kein Footprint für das Bauteil „R30“ definiert.

Fehler: Es wurde kein Footprint für das Bauteil „C56“ definiert.

Fehler: Es wurde kein Footprint für das Bauteil „L2“ definiert.

Fehler: Es wurde kein Footprint für das Bauteil „R24“ definiert.

Fehler: Es wurde kein Footprint für das Bauteil „R20“ definiert.

Fehler: Es wurde kein Footprint für das Bauteil „L3“ definiert.

Fehler: Es wurde kein Footprint für das Bauteil „R26“ definiert.

Fehler: Es wurde kein Footprint für das Bauteil „R27“ definiert.

Fehler: Es wurde kein Footprint für das Bauteil „C35“ definiert.

Fehler: Es wurde kein Footprint für das Bauteil „C29“ definiert.

Fehler: Es wurde kein Footprint für das Bauteil „C26“ definiert.

Fehler: Es wurde kein Footprint für das Bauteil „R18“ definiert.

Fehler: Es wurde kein Footprint für das Bauteil „R13“ definiert.

Fehler: Es wurde kein Footprint für das Bauteil „C28“ definiert.

Fehler: Es wurde kein Footprint für das Bauteil „C39“ definiert.

Fehler: Es wurde kein Footprint für das Bauteil „R15“ definiert.

Fehler: Es wurde kein Footprint für das Bauteil „R14“ definiert.

Fehler: Es wurde kein Footprint für das Bauteil „R21“ definiert.

Fehler: Es wurde kein Footprint für das Bauteil „C32“ definiert.

Fehler: Es wurde kein Footprint für das Bauteil „C36“ definiert.

Fehler: Es wurde kein Footprint für das Bauteil „Q1“ definiert.

Fehler: Es wurde kein Footprint für das Bauteil „R12“ definiert.

Fehler: Es wurde kein Footprint für das Bauteil „Q2“ definiert.

Fehler: Es wurde kein Footprint für das Bauteil „C45“ definiert.

Fehler: Bauteil „U14“ mit Footprint „21-0041B_16“ konnte in keiner Bibliothek der Footprintbibliothekstabelle gefunden werden.

Fehler: Es wurde kein Footprint für das Bauteil „R36“ definiert.

Fehler: Es wurde kein Footprint für das Bauteil „R17“ definiert.

Fehler: Es wurde kein Footprint für das Bauteil „R16“ definiert.

Fehler: Es wurde kein Footprint für das Bauteil „R32“ definiert.

Fehler: Es wurde kein Footprint für das Bauteil „L4“ definiert.

Fehler: Es wurde kein Footprint für das Bauteil „F1“ definiert.

Fehler: Es wurde kein Footprint für das Bauteil „C49“ definiert.

Fehler: Es wurde kein Footprint für das Bauteil „C53“ definiert.

Fehler: Es wurde kein Footprint für das Bauteil „FB11“ definiert.

Fehler: Es wurde kein Footprint für das Bauteil „C43“ definiert.

Fehler: Es wurde kein Footprint für das Bauteil „C51“ definiert.

Fehler: Es wurde kein Footprint für das Bauteil „C55“ definiert.

Fehler: Es wurde kein Footprint für das Bauteil „L6“ definiert.

Fehler: Es wurde kein Footprint für das Bauteil „C52“ definiert.

Fehler: Es wurde kein Footprint für das Bauteil „C31“ definiert.

Fehler: Es wurde kein Footprint für das Bauteil „R23“ definiert.

Fehler: Es wurde kein Footprint für das Bauteil „C33“ definiert.

Fehler: Es wurde kein Footprint für das Bauteil „R29“ definiert.

Fehler: Es wurde kein Footprint für das Bauteil „R31“ definiert.

Fehler: Es wurde kein Footprint für das Bauteil „C46“ definiert.

Fehler: Es wurde kein Footprint für das Bauteil „C50“ definiert.

Fehler: Es wurde kein Footprint für das Bauteil „C42“ definiert.

Fehler: Es wurde kein Footprint für das Bauteil „R33“ definiert.

Fehler: Es wurde kein Footprint für das Bauteil „R34“ definiert.

Fehler: Es wurde kein Footprint für das Bauteil „C47“ definiert.

Fehler: Es wurde kein Footprint für das Bauteil „R25“ definiert.

Fehler: Es wurde kein Footprint für das Bauteil „Q4“ definiert.

Fehler: Es wurde kein Footprint für das Bauteil „J13“ definiert.

Fehler: Es wurde kein Footprint für das Bauteil „R37“ definiert.

Fehler: Es wurde kein Footprint für das Bauteil „J6“ definiert.

Fehler: Es wurde kein Footprint für das Bauteil „C58“ definiert.

Fehler: Es wurde kein Footprint für das Bauteil „C59“ definiert.

Fehler: Es wurde kein Footprint für das Bauteil „C60“ definiert.

Fehler: Es wurde kein Footprint für das Bauteil „C61“ definiert.

Fehler: Es wurde kein Footprint für das Bauteil „C62“ definiert.

Fehler: Es wurde kein Footprint für das Bauteil „R40“ definiert.

Fehler: Es wurde kein Footprint für das Bauteil „R46“ definiert.

Fehler: Es wurde kein Footprint für das Bauteil „R41“ definiert.

Fehler: Es wurde kein Footprint für das Bauteil „R43“ definiert.

Fehler: Es wurde kein Footprint für das Bauteil „R45“ definiert.

Fehler: Es wurde kein Footprint für das Bauteil „R47“ definiert.

Fehler: Es wurde kein Footprint für das Bauteil „FB8“ definiert.

Fehler: Es wurde kein Footprint für das Bauteil „FB10“ definiert.

Fehler: Es wurde kein Footprint für das Bauteil „FB12“ definiert.

Fehler: Es wurde kein Footprint für das Bauteil „FB14“ definiert.

Fehler: Es wurde kein Footprint für das Bauteil „FB9“ definiert.

Fehler: Es wurde kein Footprint für das Bauteil „FB2“ definiert.

Fehler: Es wurde kein Footprint für das Bauteil „FB13“ definiert.

Fehler: Es wurde kein Footprint für das Bauteil „FB15“ definiert.

Fehler: Es wurde kein Footprint für das Bauteil „J8“ definiert.

Fehler: Es wurde kein Footprint für das Bauteil „J9“ definiert.

Fehler: Es wurde kein Footprint für das Bauteil „J10“ definiert.

Fehler: Es wurde kein Footprint für das Bauteil „J11“ definiert.

Fehler: Es wurde kein Footprint für das Bauteil „J12“ definiert.

Fehler: Es wurde kein Footprint für das Bauteil „J7“ definiert.

Fehler: Neues Bauteil „J12:/5CC9A992/5CBD1556“ konnte nicht hinzugefügt werden, wegen fehlendem Footprint „“.

Fehler: Neues Bauteil „J3:/5C8BBC94/5CA22A0B“ konnte nicht hinzugefügt werden, wegen fehlendem Footprint „“.

Fehler: Neues Bauteil „J4:/5C8BBC94/5CA74436“ konnte nicht hinzugefügt werden, wegen fehlendem Footprint „“.

Fehler: Neues Bauteil „J5:/5C8BBC94/5CA25131“ konnte nicht hinzugefügt werden, wegen fehlendem Footprint „“.

Fehler: Neues Bauteil „J6:/5C8BC88B/5C8BC8C5“ konnte nicht hinzugefügt werden, wegen fehlendem Footprint „“.

Fehler: Neues Bauteil „J7:/5CC9A992/5CBD1756“ konnte nicht hinzugefügt werden, wegen fehlendem Footprint „“.

Fehler: Neues Bauteil „J8:/5CC9A992/5CB5F9FC“ konnte nicht hinzugefügt werden, wegen fehlendem Footprint „“.

Fehler: Neues Bauteil „J9:/5CC9A992/5CB5FBA8“ konnte nicht hinzugefügt werden, wegen fehlendem Footprint „“.

Fehler: Neues Bauteil „J10:/5CC9A992/5CB5FC2E“ konnte nicht hinzugefügt werden, wegen fehlendem Footprint „“.

Fehler: Neues Bauteil „J11:/5CC9A992/5CBD13E9“ konnte nicht hinzugefügt werden, wegen fehlendem Footprint „“.

Fehler: Neues Bauteil „J2:/5C8BBC94/5CA7452F“ konnte nicht hinzugefügt werden, wegen fehlendem Footprint „“.

Fehler: Neues Bauteil „J13:/5CC9A992/5CBE3A31“ konnte nicht hinzugefügt werden, wegen fehlendem Footprint „“.

Fehler: Bauteil „J1“ mit Footprint „1-1734592-2“ konnte in keiner Bibliothek der Footprintbibliothekstabelle gefunden werden.

Fehler: Neues Bauteil „L2:/5C8BBC9A/5CA5F7E3“ konnte nicht hinzugefügt werden, wegen fehlendem Footprint „“.

Fehler: Neues Bauteil „L3:/5C8BBC9A/5CA7852F“ konnte nicht hinzugefügt werden, wegen fehlendem Footprint „“.

Fehler: Neues Bauteil „L4:/5C8BBC9A/5CB6DCC1“ konnte nicht hinzugefügt werden, wegen fehlendem Footprint „“.

Fehler: Neues Bauteil „L5:/5C8BBC9A/5CA4FCEF“ konnte nicht hinzugefügt werden, wegen fehlendem Footprint „“.

Fehler: Neues Bauteil „L6:/5C8BBC9A/5CC0C183“ konnte nicht hinzugefügt werden, wegen fehlendem Footprint „“.

Fehler: Neues Bauteil „Q1:/5C8BBC9A/5CAED088“ konnte nicht hinzugefügt werden, wegen fehlendem Footprint „“.

Fehler: Neues Bauteil „FB8:/5C9E4308/5CB78DEE“ konnte nicht hinzugefügt werden, wegen fehlendem Footprint „“.

Fehler: Neues Bauteil „D11:/5C8BBC97/5CA09B16“ konnte nicht hinzugefügt werden, wegen fehlendem Footprint „“.

Fehler: Neues Bauteil „F1:/5C8BBC9A/5CB6DEB6“ konnte nicht hinzugefügt werden, wegen fehlendem Footprint „“.

Fehler: Neues Bauteil „FB1:/5C8BBC97/5CB9AFD5“ konnte nicht hinzugefügt werden, wegen fehlendem Footprint „“.

Fehler: Neues Bauteil „FB2:/5C8BBC97/5CBA2081“ konnte nicht hinzugefügt werden, wegen fehlendem Footprint „“.

Fehler: Neues Bauteil „FB3:/5C8BBC97/5CB9B191“ konnte nicht hinzugefügt werden, wegen fehlendem Footprint „“.

Fehler: Neues Bauteil „FB4:/5C8BBC97/5CBB38BB“ konnte nicht hinzugefügt werden, wegen fehlendem Footprint „“.

Fehler: Neues Bauteil „FB5:/5C8BBC97/5CBB7155“ konnte nicht hinzugefügt werden, wegen fehlendem Footprint „“.

Fehler: Neues Bauteil „FB6:/5C8BBC97/5CBC1E32“ konnte nicht hinzugefügt werden, wegen fehlendem Footprint „“.

Fehler: Neues Bauteil „FB7:/5C8BBC97/5CBC582D“ konnte nicht hinzugefügt werden, wegen fehlendem Footprint „“.

Fehler: Neues Bauteil „Q2:/5C8BBC9A/5CB04AE3“ konnte nicht hinzugefügt werden, wegen fehlendem Footprint „“.

Fehler: Neues Bauteil „FB9:/5C9E4308/5CB8029A“ konnte nicht hinzugefügt werden, wegen fehlendem Footprint „“.

Fehler: Neues Bauteil „FB10:/5C9E4308/5CB7A78A“ konnte nicht hinzugefügt werden, wegen fehlendem Footprint „“.

Fehler: Neues Bauteil „FB11:/5C9E4308/5CB802A1“ konnte nicht hinzugefügt werden, wegen fehlendem Footprint „“.

Fehler: Neues Bauteil „FB12:/5C9E4308/5CB7BD43“ konnte nicht hinzugefügt werden, wegen fehlendem Footprint „“.

Fehler: Neues Bauteil „FB13:/5C9E4308/5CB802A8“ konnte nicht hinzugefügt werden, wegen fehlendem Footprint „“.

Fehler: Neues Bauteil „FB14:/5C9E4308/5CB7EBBA“ konnte nicht hinzugefügt werden, wegen fehlendem Footprint „“.

Fehler: Neues Bauteil „FB15:/5C9E4308/5CB802AF“ konnte nicht hinzugefügt werden, wegen fehlendem Footprint „“.

Fehler: Neues Bauteil „J1:/5C8BBC94/5CB67827“ konnte nicht hinzugefügt werden, wegen fehlendem Footprint „SamacSys_Parts:1-1734592-2“.

Fehler: Neues Bauteil „R27:/5C8BBC9A/5CA78543“ konnte nicht hinzugefügt werden, wegen fehlendem Footprint „“.

Fehler: Neues Bauteil „R18:/5C8BBC9A/5CA825C3“ konnte nicht hinzugefügt werden, wegen fehlendem Footprint „“.

Fehler: Neues Bauteil „R19:/5C8BBC9A/5CA6F323“ konnte nicht hinzugefügt werden, wegen fehlendem Footprint „“.

Fehler: Neues Bauteil „R20:/5C8BBC9A/5CA8406F“ konnte nicht hinzugefügt werden, wegen fehlendem Footprint „“.

Fehler: Neues Bauteil „R21:/5C8BBC9A/5CAB3DDA“ konnte nicht hinzugefügt werden, wegen fehlendem Footprint „“.

Fehler: Neues Bauteil „R22:/5C8BBC9A/5CA770D5“ konnte nicht hinzugefügt werden, wegen fehlendem Footprint „“.

Fehler: Neues Bauteil „R23:/5C8BBC9A/5CA770DC“ konnte nicht hinzugefügt werden, wegen fehlendem Footprint „“.

Fehler: Neues Bauteil „R24:/5C8BBC9A/5CA60ED2“ konnte nicht hinzugefügt werden, wegen fehlendem Footprint „“.

Fehler: Neues Bauteil „R25:/5C8BBC9A/5CA60ED9“ konnte nicht hinzugefügt werden, wegen fehlendem Footprint „“.

Fehler: Neues Bauteil „R26:/5C8BBC9A/5CA7853C“ konnte nicht hinzugefügt werden, wegen fehlendem Footprint „“.

Fehler: Neues Bauteil „R17:/5C8BBC9A/5CB07864“ konnte nicht hinzugefügt werden, wegen fehlendem Footprint „“.

Fehler: Neues Bauteil „R28:/5C8BBC9A/5CA54E27“ konnte nicht hinzugefügt werden, wegen fehlendem Footprint „“.

Fehler: Neues Bauteil „R29:/5C8BBC9A/5CC0C23B“ konnte nicht hinzugefügt werden, wegen fehlendem Footprint „“.

Fehler: Neues Bauteil „R30:/5C8BBC9A/5CA5594B“ konnte nicht hinzugefügt werden, wegen fehlendem Footprint „“.

Fehler: Neues Bauteil „R31:/5C8BBC9A/5CC0C242“ konnte nicht hinzugefügt werden, wegen fehlendem Footprint „“.

Fehler: Neues Bauteil „R32:/5C8BBC9A/5CB4A203“ konnte nicht hinzugefügt werden, wegen fehlendem Footprint „“.

Fehler: Neues Bauteil „R33:/5C8BBC9A/5CC0C1F2“ konnte nicht hinzugefügt werden, wegen fehlendem Footprint „“.

Fehler: Neues Bauteil „R34:/5C8BBC9A/5CC0C203“ konnte nicht hinzugefügt werden, wegen fehlendem Footprint „“.

Fehler: Neues Bauteil „R35:/5C8BBC9A/5CA5005E“ konnte nicht hinzugefügt werden, wegen fehlendem Footprint „“.

Fehler: Neues Bauteil „R8:/5C8BBC97/5CA11B40“ konnte nicht hinzugefügt werden, wegen fehlendem Footprint „“.

Fehler: Neues Bauteil „Q3:/5C8BBC9A/5CA54BA8“ konnte nicht hinzugefügt werden, wegen fehlendem Footprint „“.

Fehler: Neues Bauteil „Q4:/5C8BBC9A/5CC0C22E“ konnte nicht hinzugefügt werden, wegen fehlendem Footprint „“.

Fehler: Neues Bauteil „R1:/5C8BBC97/5C9B6DD5“ konnte nicht hinzugefügt werden, wegen fehlendem Footprint „“.

Fehler: Neues Bauteil „R2:/5C8BBC97/5C9B6ECE“ konnte nicht hinzugefügt werden, wegen fehlendem Footprint „“.

Fehler: Neues Bauteil „R3:/5C8BBC97/5C9B6F96“ konnte nicht hinzugefügt werden, wegen fehlendem Footprint „“.

Fehler: Neues Bauteil „R4:/5C8BBC97/5C9B6B4C“ konnte nicht hinzugefügt werden, wegen fehlendem Footprint „“.

Fehler: Neues Bauteil „R5:/5C8BBC97/5C9B6BDC“ konnte nicht hinzugefügt werden, wegen fehlendem Footprint „“.

Fehler: Neues Bauteil „R6:/5C8BBC97/5C9B6CCB“ konnte nicht hinzugefügt werden, wegen fehlendem Footprint „“.

Fehler: Neues Bauteil „R7:/5C8BBC97/5CA11A13“ konnte nicht hinzugefügt werden, wegen fehlendem Footprint „“.

Fehler: Neues Bauteil „D10:/5C8BBC97/5CA046D0“ konnte nicht hinzugefügt werden, wegen fehlendem Footprint „“.

Fehler: Neues Bauteil „R9:/5C8BBC97/5CA09C3A“ konnte nicht hinzugefügt werden, wegen fehlendem Footprint „“.

Fehler: Neues Bauteil „R10:/5C8BBC97/5CA09D45“ konnte nicht hinzugefügt werden, wegen fehlendem Footprint „“.

Fehler: Neues Bauteil „R11:/5C8BBC97/5C9D51AA“ konnte nicht hinzugefügt werden, wegen fehlendem Footprint „“.

Fehler: Neues Bauteil „R12:/5C8BBC9A/5CAFE75A“ konnte nicht hinzugefügt werden, wegen fehlendem Footprint „“.

Fehler: Neues Bauteil „R13:/5C8BBC9A/5CB04AF0“ konnte nicht hinzugefügt werden, wegen fehlendem Footprint „“.

Fehler: Neues Bauteil „R14:/5C8BBC9A/5CAA5DC1“ konnte nicht hinzugefügt werden, wegen fehlendem Footprint „“.

Fehler: Neues Bauteil „R15:/5C8BBC9A/5CAA3D7C“ konnte nicht hinzugefügt werden, wegen fehlendem Footprint „“.

Fehler: Neues Bauteil „R16:/5C8BBC9A/5CB0A520“ konnte nicht hinzugefügt werden, wegen fehlendem Footprint „“.

Fehler: Neues Bauteil „C22:/5C8BBC97/5C9CCACE“ konnte nicht hinzugefügt werden, wegen fehlendem Footprint „“.

Fehler: Neues Bauteil „C13:/5C8BBC94/5CA1D165“ konnte nicht hinzugefügt werden, wegen fehlendem Footprint „“.

Fehler: Neues Bauteil „C14:/5C8BBC94/5CC5CD10“ konnte nicht hinzugefügt werden, wegen fehlendem Footprint „“.

Fehler: Neues Bauteil „C15:/5C8BBC94/5CA9B7A9“ konnte nicht hinzugefügt werden, wegen fehlendem Footprint „“.

Fehler: Neues Bauteil „C16:/5C8BBC97/5C9B95B0“ konnte nicht hinzugefügt werden, wegen fehlendem Footprint „“.

Fehler: Neues Bauteil „C17:/5C8BBC97/5C9B96D7“ konnte nicht hinzugefügt werden, wegen fehlendem Footprint „“.

Fehler: Neues Bauteil „C18:/5C8BBC97/5C9B97EB“ konnte nicht hinzugefügt werden, wegen fehlendem Footprint „“.

Fehler: Neues Bauteil „C19:/5C8BBC97/5C9B9930“ konnte nicht hinzugefügt werden, wegen fehlendem Footprint „“.

Fehler: Neues Bauteil „C20:/5C8BBC97/5C9B9A0F“ konnte nicht hinzugefügt werden, wegen fehlendem Footprint „“.

Fehler: Neues Bauteil „C21:/5C8BBC97/5C9B9B27“ konnte nicht hinzugefügt werden, wegen fehlendem Footprint „“.

Fehler: Neues Bauteil „C12:/5C8BBC94/5CA1D026“ konnte nicht hinzugefügt werden, wegen fehlendem Footprint „“.

Fehler: Neues Bauteil „C23:/5C8BBC97/5C9DF7C6“ konnte nicht hinzugefügt werden, wegen fehlendem Footprint „“.

Fehler: Neues Bauteil „C24:/5C8BBC97/5C9CD5F6“ konnte nicht hinzugefügt werden, wegen fehlendem Footprint „“.

Fehler: Neues Bauteil „C25:/5C8BBC97/5CA2DCD5“ konnte nicht hinzugefügt werden, wegen fehlendem Footprint „“.

Fehler: Neues Bauteil „C26:/5C8BBC9A/5CA825AC“ konnte nicht hinzugefügt werden, wegen fehlendem Footprint „“.

Fehler: Neues Bauteil „C27:/5C8BBC9A/5CA67A0B“ konnte nicht hinzugefügt werden, wegen fehlendem Footprint „“.

Fehler: Neues Bauteil „C28:/5C8BBC9A/5CA84058“ konnte nicht hinzugefügt werden, wegen fehlendem Footprint „“.

Fehler: Neues Bauteil „C29:/5C8BBC9A/5CA8259F“ konnte nicht hinzugefügt werden, wegen fehlendem Footprint „“.

Fehler: Neues Bauteil „C30:/5C8BBC9A/5CA630A8“ konnte nicht hinzugefügt werden, wegen fehlendem Footprint „“.

Fehler: Neues Bauteil „C3:/5C8BBC94/5CA2B1BF“ konnte nicht hinzugefügt werden, wegen fehlendem Footprint „“.

Fehler: Es wurde kein Footprint für das Bauteil „FB4“ definiert.

Fehler: Es wurde kein Footprint für das Bauteil „FB5“ definiert.

Fehler: Es wurde kein Footprint für das Bauteil „FB6“ definiert.

Fehler: Es wurde kein Footprint für das Bauteil „FB7“ definiert.

Fehler: Es wurde kein Footprint für das Bauteil „C44“ definiert.

Fehler: Es wurde kein Footprint für das Bauteil „C41“ definiert.

Fehler: Es wurde kein Footprint für das Bauteil „C40“ definiert.

Fehler: Neues Bauteil „C1:/5C8BBC94/5CA39760“ konnte nicht hinzugefügt werden, wegen fehlendem Footprint „“.

Fehler: Neues Bauteil „C2:/5C8BBC94/5CA2B358“ konnte nicht hinzugefügt werden, wegen fehlendem Footprint „“.

Fehler: Neues Bauteil „C31:/5C8BBC9A/5CA8404B“ konnte nicht hinzugefügt werden, wegen fehlendem Footprint „“.

Fehler: Neues Bauteil „C4:/5C8BBC94/5C9DF857“ konnte nicht hinzugefügt werden, wegen fehlendem Footprint „“.

Fehler: Neues Bauteil „C5:/5C8BBC94/5C9DF7EC“ konnte nicht hinzugefügt werden, wegen fehlendem Footprint „“.

Fehler: Neues Bauteil „C6:/5C8BBC94/5C9DF60F“ konnte nicht hinzugefügt werden, wegen fehlendem Footprint „“.

Fehler: Neues Bauteil „C7:/5C8BBC94/5C9DF5C2“ konnte nicht hinzugefügt werden, wegen fehlendem Footprint „“.

Fehler: Neues Bauteil „C8:/5C8BBC94/5C9DF521“ konnte nicht hinzugefügt werden, wegen fehlendem Footprint „“.

Fehler: Neues Bauteil „C9:/5C8BBC94/5CA058F8“ konnte nicht hinzugefügt werden, wegen fehlendem Footprint „“.

Fehler: Neues Bauteil „C10:/5C8BBC94/5CA05796“ konnte nicht hinzugefügt werden, wegen fehlendem Footprint „“.

Fehler: Neues Bauteil „C11:/5C8BBC94/5CA058B6“ konnte nicht hinzugefügt werden, wegen fehlendem Footprint „“.

Fehler: Neues Bauteil „C60:/5C8BC88B/5CB2F4A7“ konnte nicht hinzugefügt werden, wegen fehlendem Footprint „“.

Fehler: Neues Bauteil „C51:/5C8BBC9A/5CBBDA5B“ konnte nicht hinzugefügt werden, wegen fehlendem Footprint „“.

Fehler: Neues Bauteil „C52:/5C8BBC9A/5CC0C224“ konnte nicht hinzugefügt werden, wegen fehlendem Footprint „“.

Fehler: Neues Bauteil „C53:/5C8BBC9A/5CB6E23E“ konnte nicht hinzugefügt werden, wegen fehlendem Footprint „“.

Fehler: Neues Bauteil „C54:/5C8BBC9A/5CA4FC47“ konnte nicht hinzugefügt werden, wegen fehlendem Footprint „“.

Fehler: Neues Bauteil „C55:/5C8BBC9A/5CC0C17C“ konnte nicht hinzugefügt werden, wegen fehlendem Footprint „“.

Fehler: Neues Bauteil „C56:/5C8BBC9A/5CA4FBFF“ konnte nicht hinzugefügt werden, wegen fehlendem Footprint „“.

Fehler: Neues Bauteil „C57:/5C8BBC9A/5CA4FC89“ konnte nicht hinzugefügt werden, wegen fehlendem Footprint „“.

Fehler: Neues Bauteil „C58:/5C8BC88B/5CC01965“ konnte nicht hinzugefügt werden, wegen fehlendem Footprint „“.

Fehler: Neues Bauteil „C59:/5C8BC88B/5CC019EB“ konnte nicht hinzugefügt werden, wegen fehlendem Footprint „“.

Fehler: Neues Bauteil „C50:/5C8BBC9A/5CC0C1AB“ konnte nicht hinzugefügt werden, wegen fehlendem Footprint „“.

Fehler: Neues Bauteil „C61:/5C9E4308/5CA32292“ konnte nicht hinzugefügt werden, wegen fehlendem Footprint „“.

Fehler: Neues Bauteil „C62:/5C9E4308/5CA32332“ konnte nicht hinzugefügt werden, wegen fehlendem Footprint „“.

Fehler: Neues Bauteil „D4:/5C8BBC97/5C9F7715“ konnte nicht hinzugefügt werden, wegen fehlendem Footprint „“.

Fehler: Neues Bauteil „D5:/5C8BBC97/5C9F7854“ konnte nicht hinzugefügt werden, wegen fehlendem Footprint „“.

Fehler: Neues Bauteil „D6:/5C8BBC97/5C9F7A03“ konnte nicht hinzugefügt werden, wegen fehlendem Footprint „“.

Fehler: Neues Bauteil „D7:/5C8BBC97/5CA5F6FE“ konnte nicht hinzugefügt werden, wegen fehlendem Footprint „“.

Fehler: Neues Bauteil „D8:/5C8BBC97/5CA4F5D6“ konnte nicht hinzugefügt werden, wegen fehlendem Footprint „“.

Fehler: Neues Bauteil „D9:/5C8BBC97/5CA5CD14“ konnte nicht hinzugefügt werden, wegen fehlendem Footprint „“.

Fehler: Neues Bauteil „C41:/5C8BBC9A/5CA4FAF6“ konnte nicht hinzugefügt werden, wegen fehlendem Footprint „“.

Fehler: Neues Bauteil „C32:/5C8BBC9A/5CAB698C“ konnte nicht hinzugefügt werden, wegen fehlendem Footprint „“.

Fehler: Neues Bauteil „C33:/5C8BBC9A/5CA770E9“ konnte nicht hinzugefügt werden, wegen fehlendem Footprint „“.

Fehler: Neues Bauteil „C34:/5C8BBC9A/5CA63ED7“ konnte nicht hinzugefügt werden, wegen fehlendem Footprint „“.

Fehler: Neues Bauteil „C35:/5C8BBC9A/5CA78550“ konnte nicht hinzugefügt werden, wegen fehlendem Footprint „“.

Fehler: Neues Bauteil „C36:/5C8BBC9A/5CACF0A8“ konnte nicht hinzugefügt werden, wegen fehlendem Footprint „“.

Fehler: Neues Bauteil „C37:/5C8BBC9A/5CA770C1“ konnte nicht hinzugefügt werden, wegen fehlendem Footprint „“.

Fehler: Neues Bauteil „C38:/5C8BBC9A/5CA5F7DC“ konnte nicht hinzugefügt werden, wegen fehlendem Footprint „“.

Fehler: Neues Bauteil „C39:/5C8BBC9A/5CA78528“ konnte nicht hinzugefügt werden, wegen fehlendem Footprint „“.

Fehler: Neues Bauteil „C40:/5C8BBC9A/5CA4FB3E“ konnte nicht hinzugefügt werden, wegen fehlendem Footprint „“.

Fehler: Neues Bauteil „R36:/5C8BBC9A/5CC0C190“ konnte nicht hinzugefügt werden, wegen fehlendem Footprint „“.

Fehler: Neues Bauteil „C42:/5C8BBC9A/5CC0C1C2“ konnte nicht hinzugefügt werden, wegen fehlendem Footprint „“.

Fehler: Neues Bauteil „C43:/5C8BBC9A/5CB6E445“ konnte nicht hinzugefügt werden, wegen fehlendem Footprint „“.

Fehler: Neues Bauteil „C44:/5C8BBC9A/5CA4FA44“ konnte nicht hinzugefügt werden, wegen fehlendem Footprint „“.

Fehler: Neues Bauteil „C45:/5C8BBC9A/5CB6E345“ konnte nicht hinzugefügt werden, wegen fehlendem Footprint „“.

Fehler: Neues Bauteil „C46:/5C8BBC9A/5CC0C1A4“ konnte nicht hinzugefügt werden, wegen fehlendem Footprint „“.

Fehler: Neues Bauteil „C47:/5C8BBC9A/5CC0C20A“ konnte nicht hinzugefügt werden, wegen fehlendem Footprint „“.

Fehler: Neues Bauteil „C48:/5C8BBC9A/5CA4FE23“ konnte nicht hinzugefügt werden, wegen fehlendem Footprint „“.

Fehler: Neues Bauteil „C49:/5C8BBC9A/5CB6E102“ konnte nicht hinzugefügt werden, wegen fehlendem Footprint „“.

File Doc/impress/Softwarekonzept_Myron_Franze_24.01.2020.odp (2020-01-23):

## WomoLIN Softwarekonzept Flexibel, Variabel, Benutzer & Resourcenfreundlich

24/01/2020, Myron Franze

## Anwendersicht

WomoLIN, Softwarekonzept, 24/01/2020, Myron Franze

## Anwendersicht

WomoLIN, Softwarekonzept, 24/01/2020, Myron Franze

## Anwendersicht

WomoLIN, Softwarekonzept, 24/01/2020, Myron Franze

## Anwendersicht

WomoLIN, Softwarekonzept, 24/01/2020, Myron Franze

## Anwendersicht

WomoLIN, Softwarekonzept, 24/01/2020, Myron Franze

## Anwendersicht

Stromsparend

Günstig

Flexibel

Anwenderfreundlich

Erweiterbar

Sicher

WomoLIN, Softwarekonzept, 24/01/2020, Myron Franze

## Technische Sicht

WomoLIN, Softwarekonzept, 24/01/2020, Myron Franze

## Technische Sicht

WomoLIN, Softwarekonzept, 24/01/2020, Myron Franze

## Technische Sicht

CAN

LIN

RS485

RS232

Bluetooths

WomoLIN, Softwarekonzept, 24/01/2020, Myron Franze

## Technische Sicht

PROTOKOLLE

CAN

LIN

RS485

RS232

Bluetooths

WomoLIN, Softwarekonzept, 24/01/2020, Myron Franze

## Technische Sicht

PROTOKOLLE

CAN

LIN

RS485

RS232

Bluetooths

WomoLIN, Softwarekonzept, 24/01/2020, Myron Franze

## Technische Sicht

PROTOKOLLE

CAN

LIN

RS485

RS232

Bluetooths

WomoLIN, Softwarekonzept, 24/01/2020, Myron Franze

## Technische Sicht

PROTOKOLLE

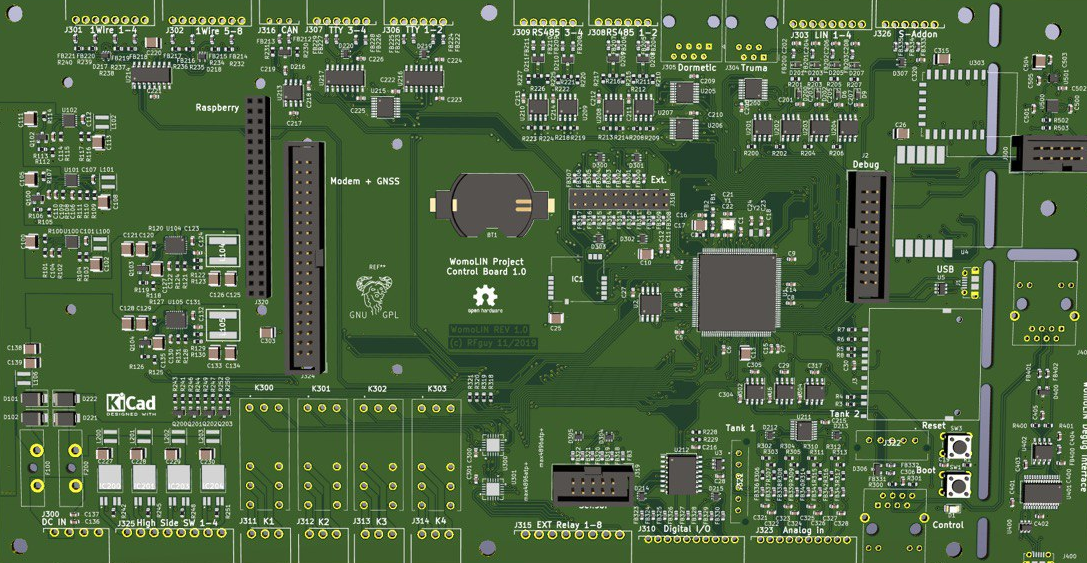
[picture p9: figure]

WomoLIN MainUnit

CAN

LIN

RS485

RS232

Bluetooths

WomoLIN, Softwarekonzept, 24/01/2020, Myron Franze

## Herausforderung

WomoLIN, Softwarekonzept, 24/01/2020, Myron Franze

## Herausforderung

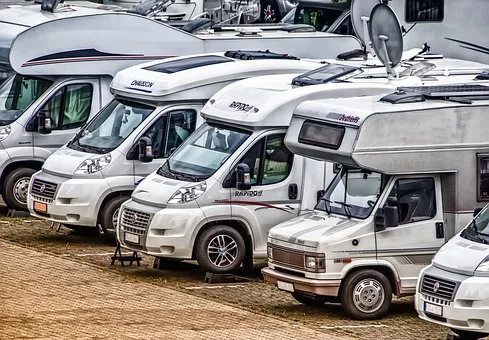
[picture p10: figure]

WomoLIN, Softwarekonzept, 24/01/2020, Myron Franze

## Lösung “Generierte Software”

WomoLIN, Softwarekonzept, 24/01/2020, Myron Franze

## Lösung “Generierte Software”

Protokol

LIN

WomoLIN, Softwarekonzept, 24/01/2020, Myron Franze

## Lösung “Generierte Software”

Units

Protokol

LIN

WomoLIN, Softwarekonzept, 24/01/2020, Myron Franze

## Lösung “Generierte Software”

Units

Was ist die aktuelle Batteriespannung?

Protokol

LIN

WomoLIN, Softwarekonzept, 24/01/2020, Myron Franze

## Lösung “Generierte Software”

Signals

Was ist die aktuelle Batteriespannung?

Units

Protokol

LIN

WomoLIN, Softwarekonzept, 24/01/2020, Myron Franze

## Lösung “Generierte Software”

Signals

Was ist die aktuelle Batteriespannung?

<signal>

<type>voltage</type>

<name>batterie_sig</name>

<description>
Aktuelle Batteriespannung
</description>

</signal>

Units

Protokol

LIN

WomoLIN, Softwarekonzept, 24/01/2020, Myron Franze

## Lösung “Generierte Software”

Signals

Was ist die aktuelle Batteriespannung?

<signal>

<type>voltage</type>

<name>batterie_sig</name>

<description>
Aktuelle Batteriespannung
</description>

</signal>

Units

<unit>

<name>batterie</name>

<protokol>bat_lin</protokol>

<signal>batterie_sig</signal>

<port>LIN1</port>

</units>

Protokol

LIN

WomoLIN, Softwarekonzept, 24/01/2020, Myron Franze

## Lösung “Generierte Software”

Signals

Was ist die aktuelle Batteriespannung?

<signal>

<type>voltage</type>

<name>batterie_sig</name>

<description>
Aktuelle Batteriespannung
</description>

</signal>

Units

<unit>

<name>batterie</name>

<protokol>bat_lin</protokol>

<signal>batterie_sig</signal>

<port>LIN1</port>

</units>

Protokol

LIN

CODE

GENERATOR

WomoLIN, Softwarekonzept, 24/01/2020, Myron Franze

## Lösung “Generierte Software”

Signals

Was ist die aktuelle Batteriespannung?

<signal>

<type>voltage</type>

<name>batterie_sig</name>

<description>
Aktuelle Batteriespannung
</description>

</signal>

Units

<unit>

<name>batterie</name>

<protokol>bat_lin</protokol>

<signal>batterie_sig</signal>

<port>LIN1</port>

</units>

Protokol

LIN

CODE

GENERATOR

WomoLIN, Softwarekonzept, 24/01/2020, Myron Franze

## WomoLIN https://github.com/muccc/WomoLIN

24/01/2020, Myron Franze

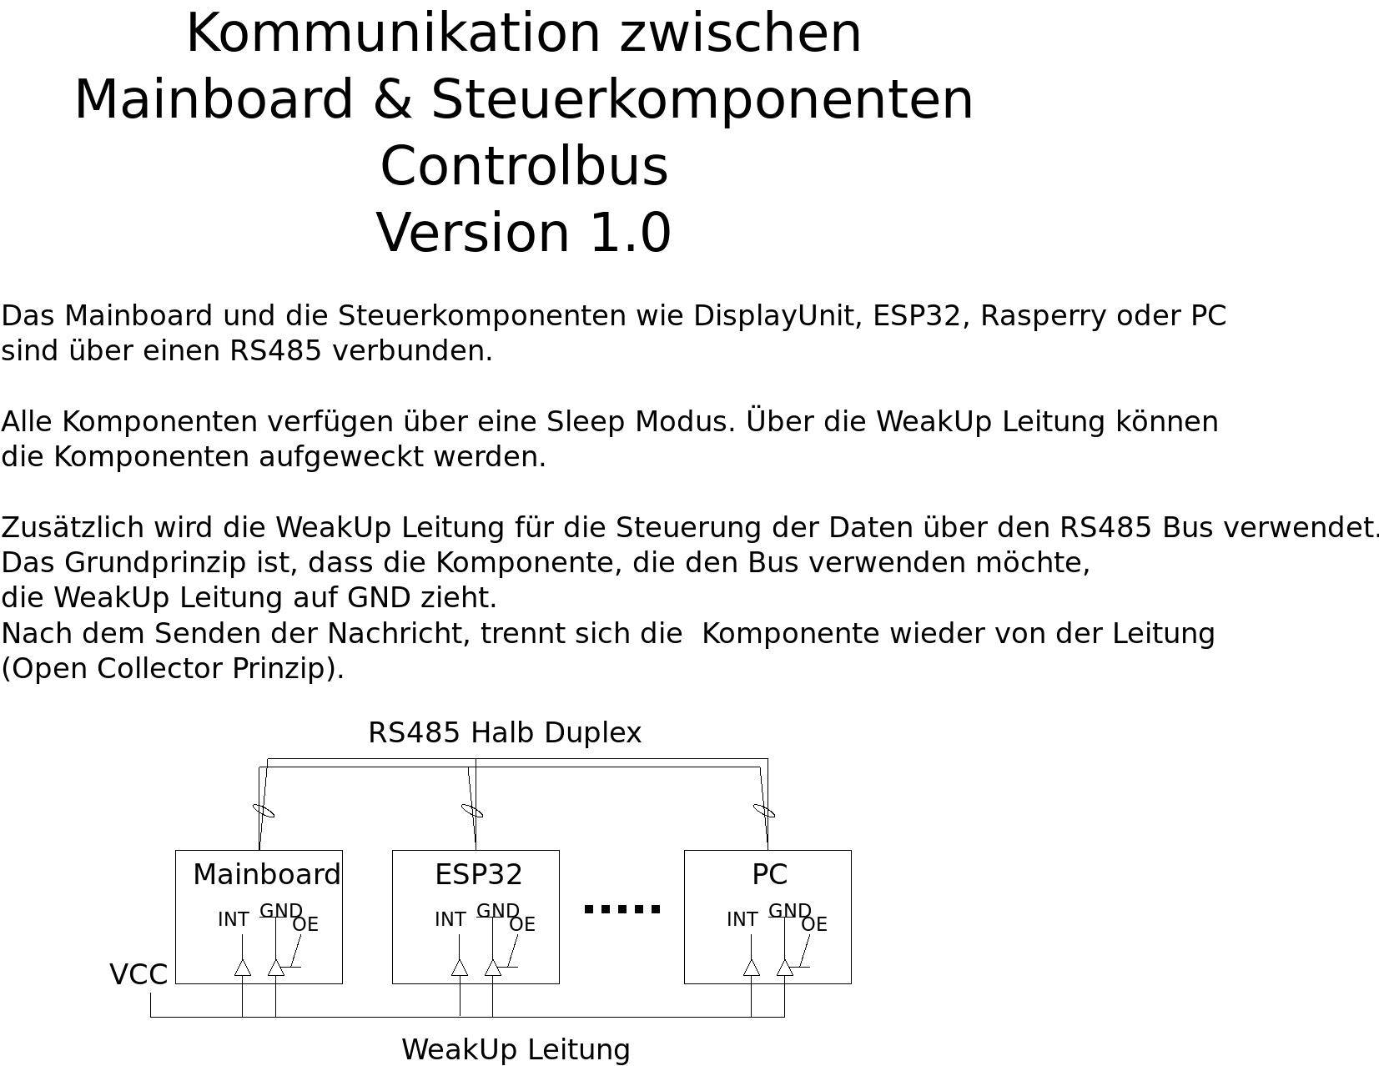
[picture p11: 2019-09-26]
Doc/dia/hardware-conrolbus-v1.0.png

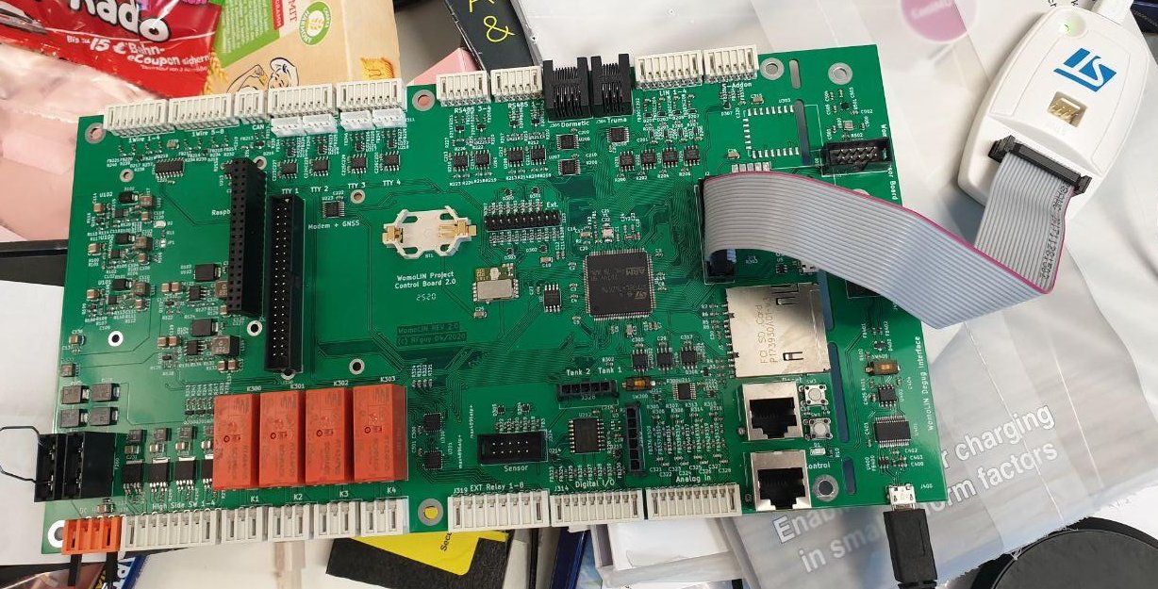
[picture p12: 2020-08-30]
Doc/pics/controlboard_2.0_anschluss_jtag.jpg

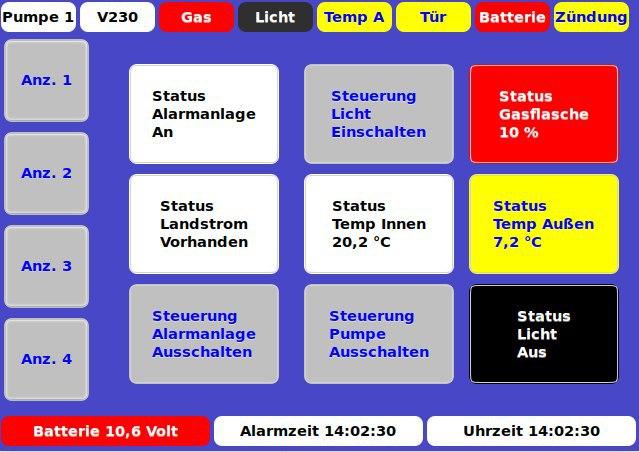
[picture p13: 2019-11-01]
Doc/pics/womolin_display_mygui.jpg

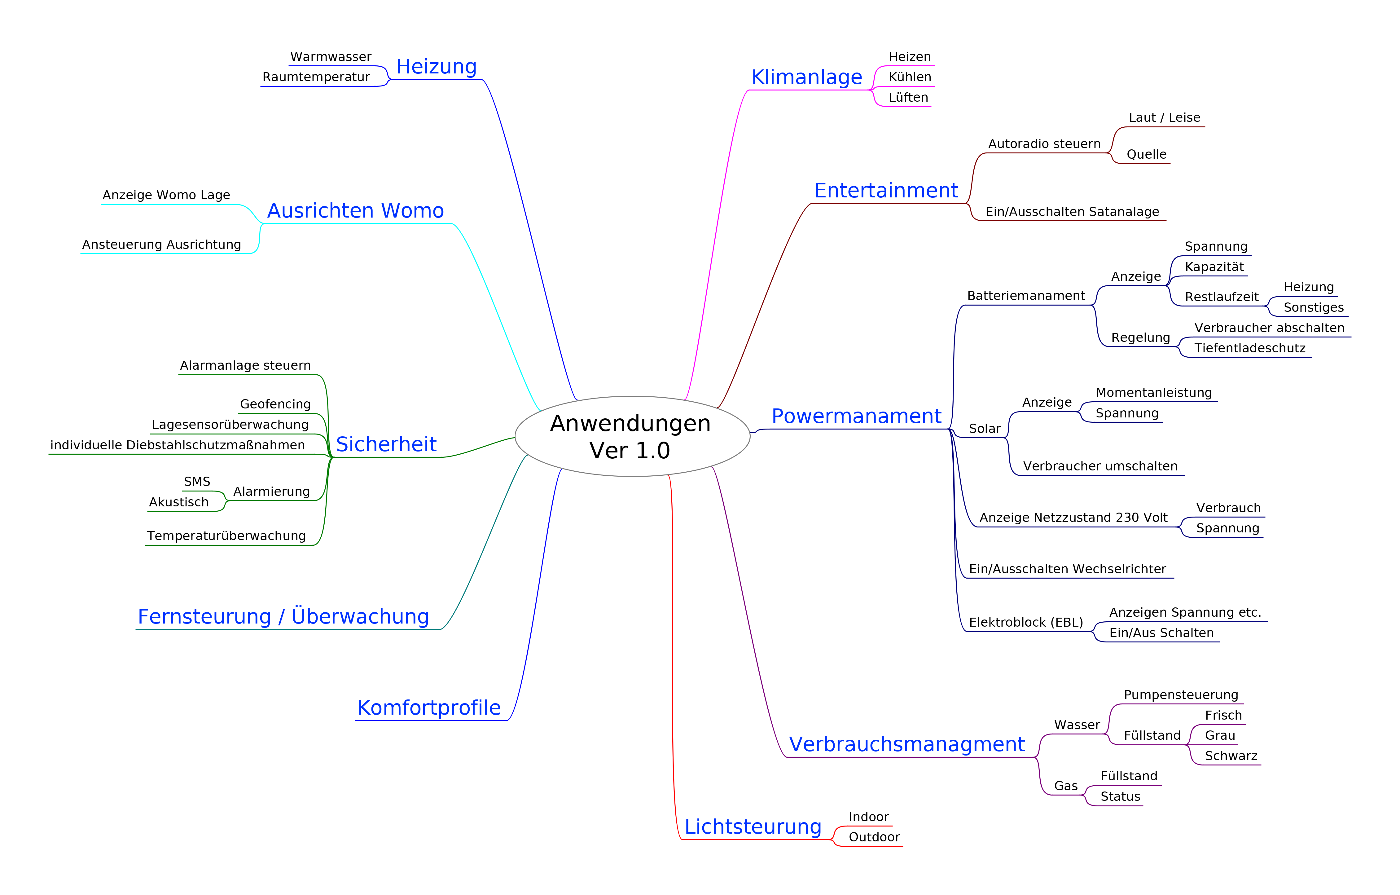
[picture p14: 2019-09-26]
Doc/freeplan/system_applikationen_v1.0.png

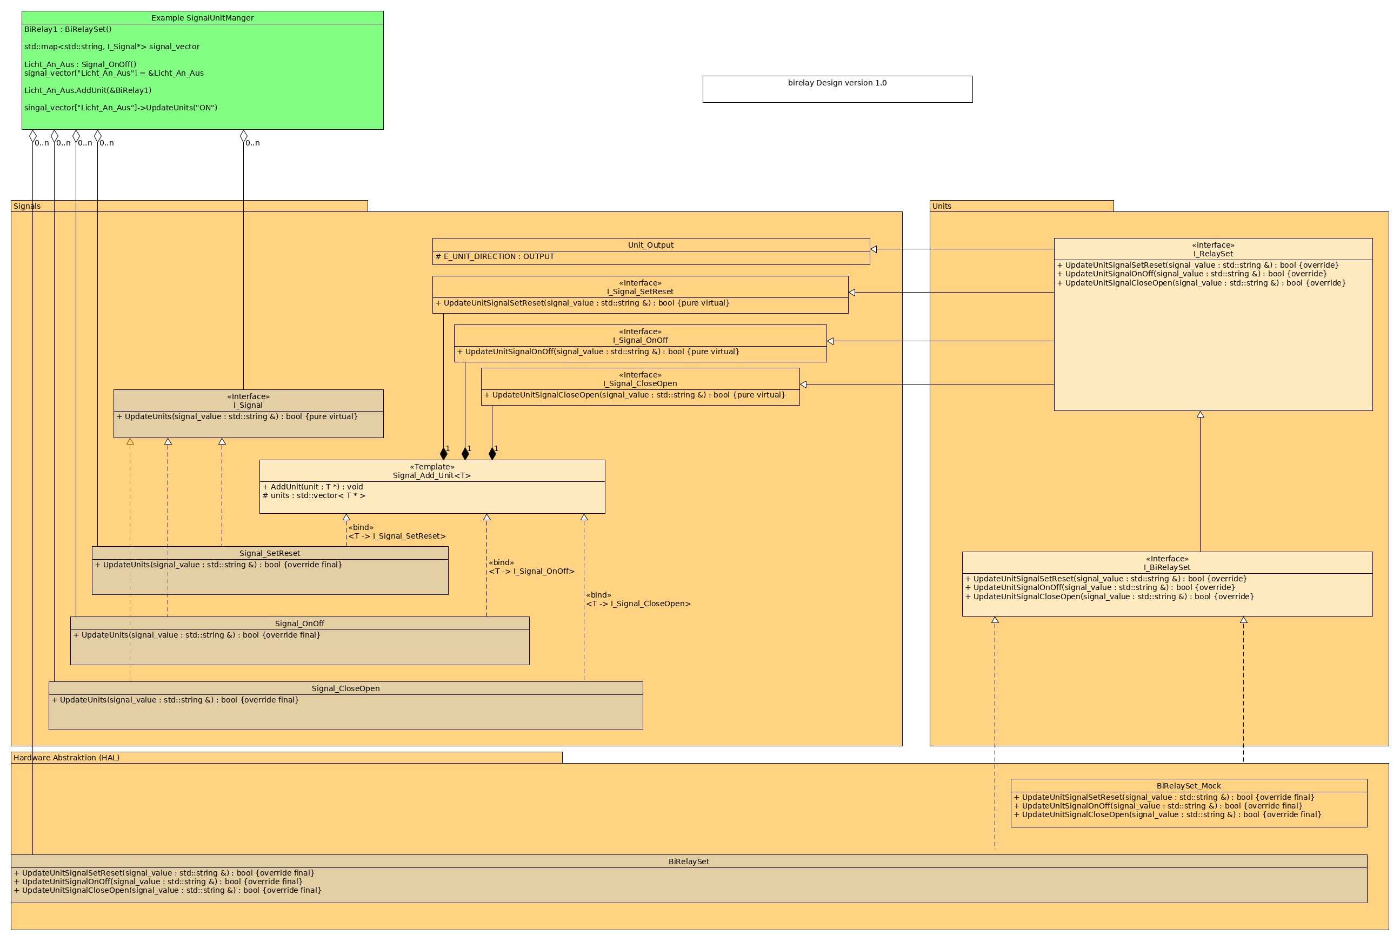
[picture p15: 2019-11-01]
Doc/umlet/birelay_v1.0.png

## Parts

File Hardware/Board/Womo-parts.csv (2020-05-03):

Source: | /Users/rfguy/git/womo-lin/Hardware/Board/Womo.sch
Date: | 2020 May 02, Saturday 23:29:32
Tool: | Eeschema (5.1.0-0)
Generator: | WomoLIN Control Board 2.0
Component Count: | 501
Ref | Qnty | Value | Cmp name | Footprint | Description | Vendor | LCSC# | Mouser#
BT1, | 1 | Battery_Cell | Battery_Cell-Device | Battery:BatteryHolder_Keystone_1058_1x2032 |  | Keystone |  | 534-1058
C24, C23, | 2 | 4p7 | C-Device | Capacitor_SMD:C_0603_1608Metric |  | Standard Part | C1669
C102, C109, C116, C11, | 4 | 10n | C-Device | Capacitor_SMD:C_0603_1608Metric |  | Standard Part | C57112
C104, C111, C118, C22, C21, | 5 | 6p8 | C-Device | Capacitor_SMD:C_0603_1608Metric |  | Standard Part | C1679
C105, C112, C119, | 3 | 2n7 | C-Device | Capacitor_SMD:C_0603_1608Metric |  | Standard Part | C1609
C122, C121, C138, C129, C128, C100, C107, C114, C136 | 9 | 2u2 50V | C-Device | Capacitor_SMD:C_1210_3225Metric |  | Standard Part | C1950
C123, C103, C137, C135, C130, C101, C108, C110, C115, C117, C305, C402, C404, C401, C400, C501, C500, C503, C502, C317, C300, C301, C320, C5, C4, C3, C2, C1, C19, C6, C7, C8, C9, C16, C15, C14, C27, C29, C28, C201, C203, C205, C217, C212, C216, C215, C221, C207, C211, C213, C214, C200, C209, C210, C222, C227, C223, C224, C225, C226, C229, C228, C230, | 63 | 100n | C-Device | Capacitor_SMD:C_0603_1608Metric |  | Standard Part | C14663
C124, C131, | 2 | 6n8 | C-Device | Capacitor_SMD:C_0603_1608Metric |  | Standard Part | C1631
C125, C132, | 2 | 47p | C-Device | Capacitor_SMD:C_0603_1608Metric |  | Standard Part | C1671
C126, C127, C106, C133, C134, C113, C120, | 7 | 22u 16V | C-Device | Capacitor_SMD:C_1210_3225Metric |  | Standard Part | C89148
C204, C206, C208, C202, | 4 | 220p | C-Device | Capacitor_SMD:C_0603_1608Metric |  | Standard Part | C1603
C219, | 1 | 5n6 | C-Device | Capacitor_SMD:C_0603_1608Metric |  | Standard Part | C170143
C232, C231, C233, C234, | 4 | 10u 16V | C-Device | Capacitor_SMD:C_1210_3225Metric |  | Standard Part | C92769
C303, C315, C10, C17, C13, C26, C25, C220, | 8 | 1u | C-Device | Capacitor_SMD:C_1206_3216Metric |  | Standard Part | C1848
C321, C322, C323, C324, C325, C326, C327, C328, | 8 | 100p | C-Device | Capacitor_SMD:C_0603_1608Metric |  | Standard Part | C14858
C403, | 1 | 4u7 | C-Device | Capacitor_SMD:C_0603_1608Metric |  | Standard Part | C19666
C405, C504, C12, C18, C30, C20, | 6 | 1u | C-Device | Capacitor_SMD:C_0603_1608Metric |  | Standard Part | C15849
C505, | 1 | 220n | C-Device | Capacitor_SMD:C_0603_1608Metric |  | Standard Part | C21120
D1, D2, | 2 | LED red | LED-Device | LED_SMD:LED_1206_3216Metric |  | Standard Part | C88326
D100, D101, D102, | 3 | B260 | B260-13-F | Diode_SMD:D_SMB | 60V 2A Schottky Barrier Rectifier Diode, SMB | Diodes Inc. | C72265 | 621-B260-F
D103, D104, D105, D106, D221, D222, | 6 | B560C | B560C-13-F | Diode_SMD:D_SMC | 60V 5A Schottky Barrier Rectifier Diode, SMC | Diodes Inc. | C85100 | 621-B560C-F
D200, D202, D204, D206, | 4 | 1N4148 | D-Device | Diode_SMD:D_SOD-323 |  | Standard Part | C2128 | 621-1N4148WS-F
D201, D203, D205, D207, | 4 | ESDLIN1524BJ | D_TVS-Device | Diode_SMD:D_SOD-323 |  | STM | C130452 | 511-ESDLIN1524BJ-HQ
D300, D301, D302, D305, D303, D304, D307, D217, D218, D214, D215, D212, D213, | 13 | SP0504BAJT | SP0504BAJT-Power_Protection | Package_TO_SOT_SMD:SOT-353_SC-70-5 |  | Littlefuse | C207263 | 576-SP0504BAJTG
D306, D400, D216, D208, D210, D211, D209, | 7 | NUP2105L | D_TVS_x2_AAC-Device | Package_TO_SOT_SMD:SOT-23 |  | ON Semi | C14486 | 863-NUP2105LT1G
F100, F200 | 2 | KFZ Fuse | 178.6164.001 | Fuse:Fuseholder_Blade_ATO_Littelfuse_Pudenz_2_Pin |  | Littlefuse |  | 576-178.6164.0001
FB336, FB337, FB338, FB339, FB340, FB341, FB342, FB343, FB300, FB301, FB302, FB303, FB304, FB305, FB306, FB307, FB314, FB315, FB316, FB317, FB312, FB313, FB311, FB331, FB332, FB401, FB402, FB400, FB318, FB319, FB320, FB321, FB322, FB323, FB324, FB325, FB326, FB327, FB328, FB329, FB330, FB310, FB309, FB308, FB3, FB334, FB335, FB333, FB344, FB345, FB346, FB347, FB1, FB2, FB202, FB201, FB200, FB212, FB213, FB206, FB207, FB214, FB215, FB216, FB217, FB218, FB219, FB220, FB221, FB203, FB204, FB205, FB208, FB209, FB210, FB211, FB224, FB225, FB226, FB227, FB228, FB229, FB223, FB222, | 84 | 120R | Ferrite_Bead_Small-Device | Inductor_SMD:L_0603_1608Metric |  | Standard Part | C42102 | 810-MPZ1608S101ATAH0
IC1, | 1 | SPSGRFC-868 | SPSGRFC-868 | Womo-Lin:SPSGRFC868 | SPSGRFC-868 - RF TRANSCEIVERS | STM | not fitted | not fitted
J2, | 1 | Conn_ARM_JTAG_SWD_20 | Conn_ARM_JTAG_SWD_20-Connector | Connector_IDC:IDC-Header_2x10_P2.54mm_Vertical |  | Standard Part | C221052 | 710-61202021621
J3, | 1 | SD_Card | SD_Card-Connector | Connector_Card:10067847-001RLF |  | Ampenol FCI |  | 649-10067847-001RLF
J300, | 1 | 734-264 | Wago 734-264 | WAGO:SHDR4W120P0X381_1X4_1640X1030X850P |  | Wago
J303, J302, J301, J306, J309, | 5 | 733-368 | Wago 733-368 | WAGO:SHDR8W80P0X250_1X8_2250X890X780P |  | Wago
J304, | 1 | Truma | RJ12-Connector | Connector_RJ:RJ12_Amphenol_54601 |  |  | not fitted | not fitted
J305, J401, | 2 | Dormetic | RJ45-Connector | Connector_RJ:RJ45_Amphenol_54602-x08_Horizontal |  |  | not fitted | not fitted
J307, J308, J311, J310, | 4 | Conn_01x04 | JST B4B-PH-K-S | Connector_JST:JST_PH_B4B-PH-K_1x04_P2.00mm_Vertical |  |  | C131334
J312, J313, J329, | 3 | 733-366 | Wago 733-366 | WAGO:SHDR6W80P0X250_1X6_1750X890X780P |  | Wago
J314, J327, | 2 | 733-370 | Wago 733-370 | WAGO:SHDR10W80P0X250_1X10_2750X890X780P |  | Wago
J315, J316, J317, J318, | 4 | 734-163 | Wago 734-163 | WAGO:SHDR3W100P0X350_1X3_1290X1030X850P |  | Wago
J319, J331, | 2 | 734-168 | Wago 734-168 | WAGO:SHDR8W150P350X350_1X8_3040X1030X860P |  | Wago
J320, | 1 | 733-363 | Wago 733-363 | WAGO:SHDR3W80P0X250_1X3_1000X890X780P |  | Wago
J322, J321, | 2 | RJ45 Shielded | Wurth 615008138221 | Womo-Lin:615008138221 |  | Wurth |  | 710-615008138221
J323, | 1 | Spare | Conn_02x10_Odd_Even-Connector_Generic | Connector_PinHeader_2.54mm:PinHeader_2x10_P2.54mm_Vertical |  | Standard Part | not fitted | not fitted
J325, | 1 | Wasser | Molex 43650-0628 | Womo-Lin:436500628 |  | Molex | not fitted | not fitted
J326, | 1 | Abwasser | Molex 43650-0527 | Womo-Lin:436500527 |  | Molex | not fitted | not fitted
J328, | 1 | Raspberry_Pi_2_3 | Raspberry_Pi_2_3-Connector | Connector_PinSocket_2.54mm:PinSocket_2x20_P2.54mm_Vertical |  | Standard Part
J330, | 1 | Waveshare IoT Hat | Conn_02x20_Odd_Even-Connector_Generic | Connector_IDC:IDC-Header_2x20_P2.54mm_Vertical |  | Standard Part
J400, J1, | 2 | USB_B_Micro | USB_B_Micro-Connector | Connector_USB:USB_Micro-B_Molex-105017-0001 |  | Molex | C136000 | 538-105017-1001
J500, J324, | 2 | SENSOR | Conn_02x05_Odd_Even-Connector_Generic | Connector_IDC:IDC-Header_2x05_P2.54mm_Vertical |  | Standard Part
JP1, | 1 | SolderJumper_2_Open | SolderJumper_2_Open | Jumper:SolderJumper-2_P1.3mm_Open_RoundedPad1.0x1.5mm | Solder Jumper, 2-pole, open |  | not fitted | not fitted
K300, K301, K302, K303, | 4 | 5-1393243-2 | 5-1393243-2 | Womo-Lin:513932432 | General Purpose Relays RT424F05 | TE |  | 655-5-1393243-2
L100, L101, L102, | 3 | 10u | L-Device | Inductor_SMD:L_Coilcraft_XxL4040 |  | Coilcraft |  | 994-XAL4040-103MEC
L103, L104, | 2 | 8u2 | L-Device | Inductor_SMD:L_Coilcraft_XAL60xx_6.36x6.56mm |  | Coilcraft |  | 994-XAL6060-822MEC
L105, L200, L202, L203, L201, | 5 | 0u22 | L-Device | Inductor_SMD:L_Coilcraft_XxL4020 |  | Coilcraft |  | 994-XAL4020-221MEB
Q102, Q103, Q100, Q101, Q200, Q201, Q202, Q203, | 8 | 2N7002 | 2N7002-Transistor_FET | Package_TO_SOT_SMD:SOT-23 |  | Standard Part | C8545 | 512-2N7002
R100, R109, R116, | 3 | 332k | R-Device | Resistor_SMD:R_0603_1608Metric |  | Standard Part | C23139
R101, | 1 | 61k9 | R-Device | Resistor_SMD:R_0603_1608Metric |  | Standard Part | C23091
R102, R110, R117, | 3 | 90k9 | R-Device | Resistor_SMD:R_0603_1608Metric |  | Standard Part | C23129
R103, R111, R118, | 3 | 32k4 | R-Device | Resistor_SMD:R_0603_1608Metric |  | Standard Part | C13187
R104, R119, | 2 | 31k6 | R-Device | Resistor_SMD:R_0603_1608Metric |  | Standard Part | C25967
R121, R128, R107, R114, R243, R246, R249, R252, | 8 | 100k | R-Device | Resistor_SMD:R_0603_1608Metric |  | Standard Part | C25803
R122, R105, R129, R106, R113, R108, R120, R115, R310, R309, R311, R312, R318, R317, R319, R320, R503, R502, R1, R200, R202, R204, R229, R228, R206, R241, R244, R247, R250, | 29 | 10k | R-Device | Resistor_SMD:R_0603_1608Metric |  | Standard Part | C25804
R123, R130, | 2 | 532k | R-Device | Resistor_SMD:R_0603_1608Metric |  | Standard Part
R124, R131, | 2 | 162k | R-Device | Resistor_SMD:R_0603_1608Metric |  | Standard Part | C22815
R126, R133, R112, | 3 | 53k6 | R-Device | Resistor_SMD:R_0603_1608Metric |  | Standard Part | C23074
R127, R125, R134, R132, | 4 | 10k2 | R-Device | Resistor_SMD:R_0603_1608Metric |  | Standard Part | C22772
R215, R217, R210, R212, R220, R222, R225, R227, | 8 | 10R | R-Device | Resistor_SMD:R_0603_1608Metric |  | Standard Part | C22859
R230, R231, | 2 | 60R | R-Device | Resistor_SMD:R_0603_1608Metric |  | Standard Part | C23090
R232, R235, R237, R239, R234, R236, R238, R240, | 8 | 4k7 | R-Device | Resistor_SMD:R_0603_1608Metric |  | Standard Part | C23162
R300, R400, R10, R11, R216, R211, R221, R226, | 8 | 120R | R-Device | Resistor_SMD:R_0603_1608Metric |  | Standard Part | C22787
R305, R306, R307, R308, R313, R314, R315, R316, R2, R201, R203, R205, R207, R242, R245, R248, R251, | 17 | 1k | R-Device | Resistor_SMD:R_0603_1608Metric |  | Standard Part | C21190
R401, R321, R322, R323, R324, R301, R302, R304, R303, R9, R7, R6, R5, R4, R8, R3, R219, R218, R224, R223, R214, R213, R209, R208, R253, | 25 | 47k | R-Device | Resistor_SMD:R_0603_1608Metric |  | Standard Part | C25819
SW1, SW3 | 1 | B3F-1000 | SW_Push-Switch | Button_Switch_THT:SW_PUSH_6mm |  | Standard Part | C93157 | 653-B3F-1000
SW300, SW400, | 2 | SW_DIP_x01 | SDA01H0SBR | Button_Switch_SMD:SW_DIP_SPSTx01_Slide_6.7x4.1mm_W6.73mm_P2.54mm_LowProfile_JPin | 1x DIP Switch, Single Pole Single Throw (SPST) switch | C&K | C221943 | 611-SDA01H0SBR
U1, | 1 | STM32L476ZGTx | STM32L476ZGTx-MCU_ST_STM32L4 | Package_QFP:LQFP-144_20x20mm_P0.5mm |  | STM |  | 511-STM32L476ZGT6TR
U2, | 1 | W25Q128JVSIQ | 16M-byte-Memory_Flash | Package_SO:SOIJ-8_5.3x5.3mm_P1.27mm |  | Winbond | C97521 | 454-W25Q128JVSIQ
U3, | 1 | 24AA025E48T-I/OT | 24AA02-OT-Memory_EEPROM | Package_TO_SOT_SMD:SOT-23-5 |  | Microchip | C129895 | 579-24AA025E48T-I/OT
U4, | 1 | MOD-nRF8001 | MOD-nRF8001-RF_Bluetooth | RF_Module:MOD-nRF8001 |  | Nordic | not fitted | not fitted
U100, U101, U102, | 3 | TPS54160DGQR | TPS54160DGQR | Womo-Lin:SOP50P490X110-11N | 3.5V to 60V Input, 1.5A Step-Down Converter with Eco-Mode | TI | C13530 | 595-TPS54160DGQR
U104, U103, | 2 | TPS54360BDDAR | TPS54340DDA | Package_SO:TI_SO-PowerPAD-8_ThermalVias | 3.5A, Step Down DC-DC Converter with Eco-mode | TI | C44377 | 595-TPS54360BDDAR
U200, U205, U206, U223, | 4 | SN74LV4052A | 4052-4xxx | Package_SO:TSSOP-16_4.4x5mm_P0.65mm |  | TI | C8142 | 595-SN74LV4052APWR
U201, U202, U203, U204, | 4 | TJA1029T | TJA1029T-Interface_CAN_LIN | Package_SO:SOIC-8_3.9x4.9mm_P1.27mm |  | NXP | C132188 | 771-TJA1029T118
U208, U207, U209, U210, | 4 | SN65HVD11DR | SN65HVD11DR | Package_SO:SOIC-8_3.9x4.9mm_P1.27mm |  | TI | C68886 | 595-SN65HVD11DR
U211, | 1 | MAX11615 | MAX11615-Analog_ADC | Package_SO:QSOP-16_3.9x4.9mm_P0.635mm |  | Maxim |  | 700-MAX11615EEE+T
U212, | 1 | PCF8574A | PCF8574A-Interface_Expansion | Package_SO:SOIC-16W_7.5x10.3mm_P1.27mm |  | NXP | C7605 | 771-PCF8574TDK-T
U214, | 1 | DS2482S-800+ | DS2482S-800+-2019-03-28_15-45-29 | Package_SO:SOIC-16_3.9x9.9mm_P1.27mm |  | Maxim |  | 700-DS2482S-800T&R
U215, U217, U216, U218, | 4 | SI8422BB-D-IS | SI8422BB-D-IS | Package_SO:SO-8_3.9x4.9mm_P1.27mm |  | SiLabs |  | 634-SI8422BB-D-IS
U224, U225, U226, U227, | 4 | BTS6143D | BTS6143D | Womo-Lin:BTS6143D | INFINEON - BTS6143D - IC, PROFET, P-TO252-5 | Infinion | C95232 | 726-BTS6143D
U300, U301, | 2 | max4896etp+ | max4896etp+ | Womo-Lin:max4896atp&plus_ |  | Maxim |  | 700-MAX4896ETP
U302, U304, U402, U6, U213, | 5 | SN65HVD234 | SN65HVD234 | Package_SO:SOIC-8_3.9x4.9mm_P1.27mm | CAN Bus Transceiver, 3.3V, 1Mbps, Enable feature, SOIC | TI | C99818 | 595-SN65HVD234DR
U303, | 1 | ESP-12F | ESP-12F-RF_Module | RF_Module:ESP-12E |  | Espressif | not fitted | not fitted
U400, U5, U219, U220, U221, U222, | 6 | USBLC6-2SC6 | USBLC6-2SC6-Power_Protection | Package_TO_SOT_SMD:SOT-23-6 |  | STM | C7519 | 511-USBLC6-2SC6
U401, | 1 | FT232RL | FT232RL-Interface_USB | Package_SO:SSOP-28_5.3x10.2mm_P0.65mm |  | FTDI | C8690 | 895-FT232RL
U500, | 1 | BME680 | BME680-Sensor | Package_LGA:Bosch_LGA-8_3x3mm_P0.8mm_ClockwisePinNumbering |  | Bosch Sensortec | C125972 | 262-BME680
U501, | 1 | LSM303AGR | LSM303C-Sensor_Motion | Package_LGA:LGA-12_2x2mm_P0.5mm |  | STM | C126671 | 511-LSM303AGRTR
Y1, | 1 | 25 MHz | Crystal_GND24-Device | Crystal:Crystal_SMD_3225-4Pin_3.2x2.5mm |  | Standard Part | C9006 | 449-LFXTAL071758CUTT
Y2, | 1 | 32.768 KHz | Crystal-Device | Crystal:Crystal_SMD_MicroCrystal_CC7V-T1A-2Pin_3.2x1.5mm |  | Standard Part | C32346 | 449-LFXTAL009678BULK

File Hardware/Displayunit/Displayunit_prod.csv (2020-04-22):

Designator | Footprint | Comment | LCSC Part #
BT1 | Womo-Lin:QJ.BS-6 | Battery_Cell | C70377
C15 C17 | Capacitor_SMD:C_1206_3216Metric | 10uF | C13585
C23 C24 | Capacitor_SMD:C_0603_1608Metric | 3p3 | C159789
C47 | Capacitor_SMD:C_1210_3225Metric | 1u
C3 C4 C58 C57 | Capacitor_SMD:C_0603_1608Metric | 6p8 | C1679
C32 C33 C21 | Capacitor_SMD:C_1210_3225Metric | 2u2
C35 | Capacitor_SMD:C_1210_3225Metric | 4u7
C38 C39 C29 C16 | Capacitor_SMD:C_0603_1608Metric | 10n | C57112
C41 C36 C50 C48 C45 C34 C30 C28 C25 C18 C19 C14 C13 C12 C11 C2 C6 C7 C8 C9 C10 C51 C53 C54 C56 C59 C40 C63 C62 C27 C60 | Capacitor_SMD:C_0603_1608Metric | 100n | C14663
C42 C44 | Capacitor_SMD:C_1210_3225Metric | 22u | C268020
C43 | Capacitor_SMD:C_0603_1608Metric | 220n | C21120
C46 C49 | Capacitor_SMD:C_1210_3225Metric | 10u | C268020
C37 C31 C1 C22 C55 C26 | Capacitor_SMD:C_1206_3216Metric | 1u | C1848
C5 | Capacitor_SMD:C_0603_1608Metric | 1u | C15849
C52 | Capacitor_SMD:C_0603_1608Metric | 5n6 | C170143
C65 C64 | Capacitor_SMD:C_0603_1608Metric | 2n7 | C1609
D1 | LED_SMD:LED_1206_3216Metric | LED | C125086
D2 D3 D4 D6 D7 | Diode_SMD:D_SMB | B260A-13-F | C109094
D5 D8 | Package_TO_SOT_SMD:SOT-23 | NUP2105L | C284104
F1 | Fuse:Fuse_1210_3225Metric | PFUF.150.2 30V 1.5A | C70100
FB1 FB2 FB3 FB4 FB11 FB12 FB5 FB6 FB7 FB8 FB9 FB10 | Inductor_SMD:L_0603_1608Metric | 100R | C21189
IC1 | Package_SO:TSSOP-16_4.4x5mm_P0.65mm | TSC2007
IC2 | Womo-Lin:BGA24C100P5X5_600X800X35 | MX25LM51245GXDI00
IC3 | Womo-Lin:BGA24C100P5X5_600X800X35 | IS66WVH8M8BLL-100B1LI_0
IC4 | Package_SON:WSON-6-1EP_2x2mm_P0.65mm_EP1x1.6mm_ThermalVias | TPS61165DRVR | C122568
J1 J2 | Womo-Lin:615008138221 | 615008138221
J10 | Womo-Lin:ER-CON10HT-1 | ER-CON10HT-1
J3 | Womo-Lin:54104-4031 | 54104-4031
J4 | Connector_IDC:IDC-Header_2x10_P2.54mm_Vertical | Conn_ARM_JTAG_SWD_20
J5 | Womo-Lin:52271-0679 | 52271-0679
J6 | Connector_PinHeader_2.54mm:PinHeader_2x06_P2.54mm_Vertical | Conn_02x06_Odd_Even
J7 | WAGO:WAGO_Klemmleiste_Hebel4mm²Horizontal_RM5mm_2-pol | WAGO_Klemmleiste_2-pol
J8 | Connector_USB:USB_Micro-B_Molex-105017-0001 | USB_B_Micro
J9 | Connector_IDC:IDC-Header_2x05_P2.54mm_Vertical | Conn_02x05_Odd_Even
L2 | Womo-Lin:MWSA0603 | 2uH2 | C112125
L4 L1 L3 | Womo-Lin:MWSA0503 | 10uH | C139506
Q1 | Package_TO_SOT_SMD:SOT-23 | 2N7002 | C8545
R10 | Resistor_SMD:R_1206_3216Metric | 1R1 | C22936
R11 R12 | Resistor_SMD:R_0603_1608Metric | 90k9 | C23129
R14 R16 | Resistor_SMD:R_0603_1608Metric | 31k6 | C25967
R13 R4 R3 R1 R15 R2 R17 R5 | Resistor_SMD:R_0603_1608Metric | 10k | C25804
R18 R19 | Resistor_SMD:R_0603_1608Metric | 60R4 | C23222
R20 | Resistor_SMD:R_0603_1608Metric | 100k | C25803
R21 R22 | Resistor_SMD:R_0603_1608Metric | 76K8 | C23107
R23 R6 R24 R25 | Resistor_SMD:R_0603_1608Metric | 0R | C21189
R26 | Resistor_SMD:R_0603_1608Metric | 120R | C22787
R7 R9 | Resistor_SMD:R_0603_1608Metric | 332k | C23137
R8 | Resistor_SMD:R_0603_1608Metric | 61k9 | C23221
SW1 | Womo-Lin:TS-1187A | Boot | C318887
SW2 | Womo-Lin:TS-1187A | Reset | C318887
U1 | Package_QFP:LQFP-144_20x20mm_P0.5mm | STM32L4R9ZITx
U2 | Package_TO_SOT_SMD:SOT-23-6 | USBLC6-2SC6 | C7519
U3 | Package_SO:SOIC-8_3.9x4.9mm_P1.27mm | SP3485EN-L/TR | C8963
U5 U4 | Womo-Lin:SOP50P490X110-11N | TPS54160DGQR | C390949
U6 | Package_SO:SOIC-8_3.9x4.9mm_P1.27mm | SN65HVD231DR | C129257
U7 | Package_SO:SO-8_5.3x6.2mm_P1.27mm | AT25SF161-SHD-T | C93710
U8 | Package_TO_SOT_SMD:SOT-23-5 | 24AA02E48T-I/OT | C38987
Y1 | Crystal:Crystal_SMD_3225-4Pin_3.2x2.5mm | X322516MLB4SI | C13738
Y2 | Crystal:Crystal_SMD_MicroCrystal_CC7V-T1A-2Pin_3.2x1.5mm | Q13FC1350000400 | C32346

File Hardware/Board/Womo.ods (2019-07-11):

Referenz | Stück | Wert | Name/Bezeichnung | Footprint | Beschreibung | Hersteller | Mouser Nr. | Mouser Preis | Reichelt Nr. | Reichelt Preis | Digikey Nr. | Digikey Preis | Bemerkung | Kalkulation Mouser
BT1, | 1 | Battery_Cell | Battery_Cell | Battery:BatteryHolder_Keystone_1058_1x2032 | Single-cell battery | Keystone | 534-1058 | 0,703 |  |  |  |  |  | 0,703
C11, C116, C118 | 3 | 10nF | C | Capacitor_SMD:C_0603_1608Metric | Unpolarized capacitor | Yageo | 603-AC603KRX7R9BB103 | 0,021 | X7R-G0603 10N | 0,05 |  |  |  | 0,063
C12, C26, C18, C25, C20, C35, C36, C37, C129 | 8 | 1uF | C | Capacitor_SMD:C_0603_1608Metric | Unpolarized capacitor | Yageo | 603-CC603KRX5R8BB105 | 0,04 | X7R-G0603 1,0/25 |  |  |  |  | 0,32
C22, C21, | 2 | 6p8 | C | Capacitor_SMD:C_0603_1608Metric | Unpolarized capacitor | Yageo | 603-CC0603DRNPO9BN8R2 (https://www.mouser.de/ProductDetail/Yageo/CC0603DRNPO9BN8R2?qs=sGAEpiMZZMs0AnBnWHyRQMMzfhmH8IQXU1ZZ2w8KRdA%3D) | 0,019 |  |  |  |  |  | 0,038
C24, C23, | 2 | 3p3 | C | Capacitor_SMD:C_0603_1608Metric | Unpolarized capacitor | Yageo | 603-CC603CRNPO9BN3R3 | 0,019 |  |  |  |  |  | 0,038
C109, C137, C117, C119 | 2 | 4u7 | C | Capacitor_SMD:C_1210_3225Metric | Unpolarized capacitor | Yageo | 603-CC121KKX7R8BB475 | 0,135 | X7R-G1210 4,7 | 0,35 |  |  |  | 0,27
C110, C104, C114, C133, C210 | 4 | 5n6 | C | Capacitor_SMD:C_0603_1608Metric | Unpolarized capacitor | Yageo | 603-CC603KRX7R9BB562 | 0,019 |  |  |  |  |  | 0,076
C121, C120, C105, C100, C111, C132, C17, | 7 | 2u2 | C | Capacitor_SMD:C_1210_3225Metric | Unpolarized capacitor | Taiyo | 963-TMK325B7225KH-T | 0,134 | X7R-G1210 2,2 | 0,43 |  |  |  | 0,938
C122, | 1 | 22nF | C | Capacitor_SMD:C_0603_1608Metric | Unpolarized capacitor | Yageo | 603-CC603KRX7R9BB223 | 0,018 | X7R-G0603 22N | 0,05 |  |  |  | 0,018
C125, C126, C102, C113, | 4 | 22uF | C | Capacitor_SMD:C_1210_3225Metric | Unpolarized capacitor | Taiyo | 963-JMK325BJ226MM-T | 0,183 | X7R-G1210 22 | 0,48 |  |  |  | 0,732
C127, C309, C312, C311, C310, C34, | 11 | 10uF | C | Capacitor_SMD:C_1210_3225Metric | Unpolarized capacitor | Taiyo | 963-EMK325BJ106MN-T | 0,11 | X7R-G1210 10 | 0,54 |  |  |  | 1,21
C130, C131, C308, C206, C108, C136, C10, C13, | 3 | 47u | C | Capacitor_SMD:C_1210_3225Metric | Unpolarized capacitor | Taiyo | 963-JMK325BJ476MMHP | 0,258 | X7R-G1210 47 | 0,45 |  |  |  | 0,774
C200, C202, C204, C208, C209, C211, C212, C213, C214, C207, C124, C123, C107, C101, C112, C135, C19, C33, C32, C31, C30, C29, C28, C106, C128, C134, C115, C5, C4, C3, C2, C1, C6, C7, C8, C9, C16, C15, C14, C27, | 40 | 100nF | C | Capacitor_SMD:C_0603_1608Metric | Unpolarized capacitor | Yageo | 603-C0603ZRY5V9BB104 | 0,005 | X7R-G0603 100N | 0,05 |  |  |  | 0,2
C201, C203, C205, | 3 | 220pF | C | Capacitor_SMD:C_0603_1608Metric | Unpolarized capacitor | Yageo | 603-C0603JRNPO9BN221 | 0,019 | NP0-G0603 220P | 0,05 |  |  |  | 0,057
C300, C301, C302, C303, C304, C305, C306, C307, | 8 | 100pF | C | Capacitor_SMD:C_0603_1608Metric | Unpolarized capacitor | Yageo | 603-CC603JPNPO9BN101 | 0,017 | NP0-G0603 100P | 0,05 |  |  |  | 0,136
D1, | 1 | LED | LED | LED_SMD:LED_1206_3216Metric | Light emitting diode |  |  |  |  |  |  |  |  | 0
D4, D5, D6, | 3 | D | D | Diode_SMD:D_SOD-323 | Diode |  |  |  |  |  |  |  |  | 0
D200, D201, D202, | 3 | ESDLIN1524BJ | D_TVS | Diode_SMD:D_SOD-323 | Bidirectional transient-voltage-suppression diode | STM | 511-ESDLIN1524BJ-HQ | 0,262 |  |  |  |  |  | 0,786
D203, D204 | 1 | NUP2105L | D_TVS_x2_AAC | Package_TO_SOT_SMD:SOT-23 | Bidirectional dual transient-voltage-suppression diode, center on pin 3 | ON | 863-NUP2105LT1G | 0,258 |  |  |  |  |  | 0,258
D205, D206, D207, D208, D209, D210, D303, D304, D305, | 9 | SP0504BAJT | SP0504BAJT | Package_TO_SOT_SMD:SOT-353_SC-70-5 | TVS Diode Array, 5.5V Standoff, 4 Channels, SC-70-5 package | Littlefuse | 576-SP0504BAJTG | 0,73 |  |  |  |  |  | 6,57
D100, D101, D102, D300, D301, D302, | 6 | B230 | B230 | Diode_SMD:D_SMB | 30V 2A Schottky Barrier Rectifier Diode, SMB | Diodes | 621-B345BE-13 | 0,245 |  |  |  |  |  | 1,47
F1, | 1 | KFZ 5A | Fuse | Fuse:Fuseholder_Blade_ATO_Littelfuse_Pudenz_2_Pin | Fuse |  |  |  |  |  |  |  |  | 0
FB1, FB4, FB3, FB2, FB5, FB202, FB201, FB200, FB211, FB212, FB213, FB214, FB203, FB204, FB205, FB206, FB207, FB208, FB209, FB210, FB100, FB101, FB300, FB301, FB302, FB303, FB304, FB305, FB306, FB307, FB309, FB310, FB311, FB308, FB312, FB313, FB314, FB315, FB316, FB317, FB318, FB319, FB323, FB324, FB325, FB326, FB321, FB322, FB320, | 49 | 100R | Ferrite_Bead_Small | Inductor_SMD:L_0603_1608Metric | Ferrite bead, small symbol | TDK | 810-MPZ1608S101ATAH0 | 0,031 |  |  |  |  |  | 1,519
IC1, | 1 | MX25LM51245GXDI00 | MX25LM51245GXDI00-SamacSys_Parts | SamacSys_Parts:BGA24C100P5X5_600X800X35 |  | Macronix |  |  |  |  | 1092-1248-ND |  | Optional | 0
IC2, | 1 | IS66WVH8M8BLL-100B1LI_0 | IS66WVH8M8BLL-100B1LI_0-SamacSys_Parts | SamacSys_Parts:BGA24C100P5X5_600X800X35 |  | ISSI | 870-WVH8M8BLL100B1LI | 3,9 |  |  |  |  | Optional | 3,9
IC3, | 1 | TSC2007 | TSC2007-opendous | Package_SO:TSSOP-16_4.4x5mm_P0.65mm |  | TI | 595-TSC2007IPWR | 2,04 |  |  |  |  | Nur bei resitiven Touch Display | 2,04
J1, | 1 | Conn_02x25_Odd_Even | Conn_02x25_Odd_Even | Connector_PinHeader_2.54mm:PinHeader_2x25_P2.54mm_Vertical | Generic connector, double row, 02x25, odd/even pin numbering scheme (row 1 odd numbers, row 2 even numbers), script generated (kicad-library-utils/schlib/autogen/connector/) | Molex | 538-87834-2643 | 3,15 | WSL 50G | 0,32 |  |  |  | 3,15
J2, | 1 | 54104-4031 | FPC 40 Pin 0,5mm | SamacSys_Parts:54104-4031 |  | Molex | 538-54104-4031 | 2,34 |  |  |  |  |  | 2,34
J3, | 1 | 52271-0679 | FPC 6 Pin 1mm | SamacSys_Parts:52271-0679 |  | Molex | 538-52271-0679 | 0,74 |  |  |  |  |  | 0,74
J4, | 1 | Conn_02x06_Odd_Even | Conn_02x06_Odd_Even | Connector_PinHeader_2.54mm:PinHeader_2x06_P2.54mm_Vertical | Generic connector, double row, 02x06, odd/even pin numbering scheme (row 1 odd numbers, row 2 even numbers), script generated (kicad-library-utils/schlib/autogen/connector/) |  | n.f. |  |  |  |  |  | Nicht bestückt, Verdrahtung Display Option | 0
J6, | 1 | USB_B_Micro | USB_B_Micro | Connector_USB:USB_Micro-B_Molex-105017-0001 | USB Micro Type B connector | Molex | 538-105017-1001 | 1,19 |  |  |  |  |  | 1,19
J7, | 1 | Conn_ARM_JTAG_SWD_20 | Conn_ARM_JTAG_SWD_20 | Connector_IDC:IDC-Header_2x10_P2.54mm_Vertical | Standard IDC20 Male Connector, ARM legacy JTAG and SWD interface | Würth | 710-61201021621 | 0,48 | WSL 20G | 0,12 |  |  |  | 0,48
J300, | 1 | Power In | WAGO_Klemmleiste_4-pol-WAGO_Klemmleisten | WAGO Klemmleisten:WAGO_Klemmleiste_Hebel4mmÂ²Vertikal_RM5mm_4-pol | WAGO 2604 | Wago |  |  | WAGO 2604-1104 | 2,65 |  |  |  | 0
J301, J302, J306, J307 | 4 | 1Wire+Analog 1-4 + 5-8 | WAGO_Klemmleiste_8-pol-WAGO_Klemmleisten | WAGO Klemmleisten:WAGO_Klemmleiste_Hebel4mmÂ²Vertikal_RM5mm_8-pol | WAGO 2604 | Wago |  |  | WAGO 2604-3104 | 3,99 |  |  |  | 0
J303, J310 | 1 | LIN 1-3, CAN-RS485 | WAGO_Klemmleiste_6-pol-WAGO_Klemmleisten | WAGO Klemmleisten:WAGO_Klemmleiste_Hebel4mmÂ²Vertikal_RM5mm_6-pol | WAGO 2604 | Wago |  |  |  |  |  |  |  | 0
J304, | 1 | Truma | RJ12 | Connector_RJ:RJ12_Amphenol_54601 | RJ connector, 6P6C (6 positions 6 connected) | AMP | 649-54601-906001WPLF | 0,21 |  |  |  |  |  | 0,21
J305, | 1 | Dormetic | RJ45 | Connector_RJ:RJ45_Amphenol_54602-x08_Horizontal | RJ connector, 8P8C (8 positions 8 connected) | AMP | 649-54602-908LF | 0,524 |  |  |  |  |  | 0,524
J308, | 1 | Wasser | Conn_01x06 | SamacSys_Parts:436500628 | Generic connector, single row, 01x06, script generated (kicad-library-utils/schlib/autogen/connector/) | Molex | 538-43650-0628 | 1,49 |  |  |  |  | Für Schaudt Wassersensor | 1,49
J309, | 1 | Abwasser | Conn_01x05 | SamacSys_Parts:436500527 | Generic connector, single row, 01x05, script generated (kicad-library-utils/schlib/autogen/connector/) | Molex | 538-43650-0527 | 1,14 |  |  |  |  | Für Schaudt Abwassersensor | 1,14
J311, | 1 | Schaudt EBL | Conn_02x03_Top_Bottom | Connectors_Molex:Molex_Microfit3_Header_02x03_Straight_43045-0628 | Generic connector, double row, 02x03, top/bottom pin numbering scheme (row 1: 1...pins_per_row, row2: pins_per_row+1 ... num_pins), script generated (kicad-library-utils/schlib/autogen/connector/) | Molex | 538-43045-0628 | 1,58 |  |  |  |  | Für Schaudt EBL | 1,58
J313, | 1 | CPU | Conn_02x25_Odd_Even | Connector_PinSocket_2.54mm:PinSocket_2x25_P2.54mm_Vertical | Generic connector, double row, 02x25, odd/even pin numbering scheme (row 1 odd numbers, row 2 even numbers), script generated (kicad-library-utils/schlib/autogen/connector/) | Samtec | 200-SSQ12501GD | 6,18 | BL 2X25G8 2,54 | 0,62 |  |  |  | 6,18
J5, J314, J315 | 1 | SIM800-1, SIM800-2, Spare | Conn_01x06 | Connector_PinHeader_2.54mm:PinHeader_1x06_P2.54mm_Vertical | Generic connector, single row, 01x06, script generated (kicad-library-utils/schlib/autogen/connector/) | Preci-DIP | 437-8018300610001101 | 0,742 | BL 1X10G 2,54 | 0,61 |  |  |  | 0,742
J315, | 1 | Raspberry_Pi_2_3 | Raspberry_Pi_2_3 | Connector_IDC:IDC-Header_2x20_P2.54mm_Vertical | expansion header for Raspberry Pi 2 & 3 | Harwin | 855-M20-7831046 | 1,57 |  |  |  |  |  | 1,57
J316, | 4 | 15uH | L | Inductor_SMD:L_Coilcraft_XxL4040 | Inductor | Coilcraft | 994-XAL4040-153MEC | 3,02 |  |  |  |  |  | 12,08
L101, L100, L102, L106, | 1 | 4uH7 | L | Inductor_SMD:L_Coilcraft_XxL4030 | Inductor | Coilcraft | 994-XAL4030-472MEC | 1,95 |  |  |  |  |  | 1,95
L103, | 1 | 10uH | L | SamacSys_Parts:XAL8080 | Inductor | Coilcraft | 994-XAL8080-103MEB | 5,66 |  |  |  |  |  | 5,66
L104, | 1 | L_Core_Ferrite | L | Inductor_SMD:L_Coilcraft_XxL4020 | Inductor with ferrite core | Coilcraft | 994-XAL4020-221MEB | 1,75 |  |  |  |  |  | 1,75
L105, | 6 | 2N7002 | 2N7002 | Package_TO_SOT_SMD:SOT-23 | 0.115A Id, 60V Vds, N-channel MOSFET, SOT-23 | ON | 512-2N7002 | 0,199 |  |  |  |  |  | 1,194
Q100, Q102, Q104, Q103, Q301, Q300, | 1 | 3M3 | R | Resistor_SMD:R_0603_1608Metric | Resistor | Yageo | 603-RC0603JR-073M3L | 0,005 |  |  |  |  |  | 0,005
R100, | 1 | 432k | R | Resistor_SMD:R_0603_1608Metric | Resistor | Yageo | 603-RC0603FR-07432KL | 0,005 |  |  |  |  |  | 0,005
R101, | 2 | 86k6 | R | Resistor_SMD:R_0603_1608Metric | Resistor | Yageo | 603-RC0603FR-0786K6L | 0,005 |  |  |  |  |  | 0,01
R103, R114, | 3 | 32k4 | R | Resistor_SMD:R_0603_1608Metric | Resistor | Yageo | 603-RC0603FR-0732K4L | 0,005 |  |  |  |  |  | 0,015
R104, R115, R118, | 2 | 178k | R | Resistor_SMD:R_0603_1608Metric | Resistor | Yageo | 603-RC0603FR-07178KL | 0,005 |  |  |  |  |  | 0,01
R109, R128, | 2 | 39k | R | Resistor_SMD:R_0603_1608Metric | Resistor | Yageo | 603-RC0603FR-0739KL | 0,005 |  |  |  |  |  | 0,01
R110, R129, | 1 | 100K | R | Resistor_SMD:R_0603_1608Metric | Resistor | Yageo | 603-RC0603FR-07100KL | 0,005 |  |  |  |  |  | 0,005
R116, | 1 | 10R 1% | R | Resistor_SMD:R_0603_1608Metric | Resistor | Yageo | 603-RC0603FR-1310RL | 0,01 |  |  |  |  |  | 0,01
R117, R208, R210 | 25 | 10K | R | Resistor_SMD:R_0603_1608Metric | Resistor | Yageo | 603-RC0603FR-0710KL | 0,005 |  |  |  |  |  | 0,125
R119, R105, R111, R125, R305, R304, R306, R307, R313, R312, R314, R315, R316, R318, R321, R320, R200, R202, R204, R49, R48, R4, R3, R1, R2, | 8 | 40k2 | R | Resistor_SMD:R_0603_1608Metric | Resistor | Yageo | 603-RC0603FR-0740K2L | 0,005 |  |  |  |  |  | 0,04
R120, R107, R102, R113, R112, R106, R127, R126, | 1 | 49k9 | R | Resistor_SMD:R_0603_1608Metric | Resistor | Yageo | 603-RC0603FR-0749K9L | 0,005 |  |  |  |  |  | 0,005
R121, | 3 | 4r7 | R | Resistor_SMD:R_0603_1608Metric | Resistor | Yageo | 603-RC0603FR-074R7L | 0,01 |  |  |  |  |  | 0,03
R122, R108, R130, | 1 | 105k | R | Resistor_SMD:R_0603_1608Metric | Resistor | Yageo | 603-RC0603FR-07105KL | 0,005 |  |  |  |  |  | 0,005
R123, | 1 | 22k6 | R | Resistor_SMD:R_0603_1608Metric | Resistor | Yageo | 603-AC0603FR-0722K6L | 0,007 |  |  |  |  |  | 0,007
R124, | 13 | 1K | R | Resistor_SMD:R_0603_1608Metric | Resistor | Yageo | 603-RC0603FR-071KL | 0,005 |  |  |  |  |  | 0,065
R201, R203, R205, R300, R301, R302, R303, R308, R309, R310, R311, R317, R319, | 2 | 60R4 | R | Resistor_SMD:R_0603_1608Metric | Resistor | Yageo | 603-RC0603FR-0760R4L | 0,005 |  |  |  |  |  | 0,01
R206, R207, | 1 | 120R | R | Resistor_SMD:R_0603_1608Metric | Resistor | Yageo | 603-RC0603FR-07120RL | 0,005 |  |  |  |  |  | 0,005
R209, | 8 | 4k7 | R | Resistor_SMD:R_0603_1608Metric | Resistor | Yageo | 603-RC0603FR-074K7L | 0,005 |  |  |  |  |  | 0,04
R211, R213, R215, R217, R212, R214, R216, R218, | 1 | Boot | SW_Push | Button_Switch_THT:SW_PUSH_6mm | Push button switch, generic, two pins | Grayhill | 706-95C06A2T | 0,148 |  |  |  |  |  | 0,148
SW1, | 1 | Wakeup | SW_Push | Button_Switch_THT:SW_PUSH_6mm_H8.5mm | Push button switch, generic, two pins | Grayhill | (706-95C06A2T) | 0,148 |  |  |  |  |  | 0,148
SW2, | 1 | Reset | SW_Push | Button_Switch_THT:SW_PUSH_6mm | Push button switch, generic, two pins | Grayhill | 706-95C06A2T | 0,148 |  |  |  |  |  | 0,148
SW3, | 1 | STM32L4R9ZITx | STM32L4R9ZITx | Package_QFP:LQFP-144_20x20mm_P0.5mm | ARM Cortex-M4 MCU, 2048KB flash, 640KB RAM, 120MHz, 1.71-3.6V, 110 GPIO, LQFP-144 | STM | 511-STM32L4R9ZIT6 | 14,56 |  |  |  |  |  | 14,56
U1, | 1 | USBLC6-2SC6 | USBLC6-2SC6 | Package_TO_SOT_SMD:SOT-23-6 | Bidirectional ESD Protection Diode, SOT-23-6 | STM | 511-USBLC6-2SC6 | 0,393 |  |  |  |  |  | 0,393
U2, | 1 | MOD-nRF8001 | MOD-nRF8001 | RF_Module:MOD-nRF8001 | Bluetooth Low Energy module based on nRF8001 chipset |  |  |  |  |  |  |  |  | 0
U3, | 4 | MAX17572 | MAX17572 | Package_DFN_QFN:DFN-12-1EP_3x3mm_P0.5mm_EP2.05x2.86mm | 4.5Vâ 60V, 1A, High-Efficiency, Synchronous Step-Down DC-DC Converter with Internal Compensation, DFN-12 | Maxim | 700-MAX17572ATC+ | 2,16 |  |  |  |  |  | 8,64
U100, U102, U101, U105, | 1 | STLD40D | STLD40D-DC_DC_Wandler | Package_DFN_QFN:DFN-8-1EP_3x3mm_P0.65mm_EP1.55x2.4mm |  | STM | 511-STLD40DPUR | 1,29 |  |  |  |  |  | 1,29
U103, | 1 | MAX17574 | MAX17574 | Package_DFN_QFN:QFN-24-1EP_4x5mm_P0.5mm_EP2.65x3.65mm | 4.5Vâ 60V, 3A, High-Efficiency, Synchronous Step-Down DC-DC Converter with Internal Compensation, QFN-24 | Maxim | 700-MAX17574ATG+ | 2,58 |  |  |  |  |  | 2,58
U104, | 3 | TJA1029T | TJA1029T | Package_SO:SOIC-8_3.9x4.9mm_P1.27mm | LIN 2.2A/SAE J2602 transceiver with TXD dominant timeout, SOIC-8 | TI | 771-TJA1029T118 | 0,795 |  |  |  |  |  | 2,385
U200, U201, U202, | 1 | TJA1049T-3 | TJA1049T-3 | Package_SO:SOIC-8_3.9x4.9mm_P1.27mm | High-Speed CAN Transceiver, separate VIO, standby mode, SOIC-8 |  | 771-TJA1049T/3J | 1,27 |  |  |  |  |  | 1,27
U203, | 1 | MAX3072E | MAX3072E | Package_SO:SOIC-8_3.9x4.9mm_P1.27mm | +3.3V, Â±15kV ESD-Protected, Fail-Safe, Hot-Swap, RS-485/RS-422 Transceivers | Maxim | 700-MAX3072EESA | 3,25 |  |  |  |  |  | 3,25
U204, | 1 | DS2482S-800+ | DS2482S-800+-2019-03-28_15-45-29 | Package_SO:SOIC-16_3.9x9.9mm_P1.27mm |  | Maxim | 700-DS2482S-800 | 6,5 |  |  |  |  |  | 6,5
U205, | 2 | PCF8574A | PCF8574A | Package_SO:SOIC-16W_7.5x10.3mm_P1.27mm | 8 Bit Port/Expander to I2C Bus, DIP/SOIC-16 | TI | 595-PCF8574ADWR | 1,11 |  |  |  |  |  | 2,22
U206, U207, | 1 | MAX11615 | MAX11615 | Package_SO:QSOP-16_3.9x4.9mm_P0.635mm | 8-channel single-ended or 4-channel, differential, 12-bit ADC, I2C, 2.048V internal reference, 16-QSOP package | Maxim | 700-MAX11615EEE | 3,36 |  |  |  |  |  | 3,36
U208, | 1 | ESP-12F | ESP-12F | RF_Module:ESP-12E | 802.11 b/g/n Wi-Fi Module |  |  |  |  |  |  |  |  | 0
U300, | 1 | 16 MHz | Crystal_GND24 | Crystal:Crystal_SMD_3225-4Pin_3.2x2.5mm | Four pin crystal, GND on pins 2 and 4 | IQD | 449-LFXTAL064296CUTT | 0,515 |  |  |  |  |  | 0,515
Y1, | 1 | 32768 | Crystal | Crystal:Crystal_SMD_MicroCrystal_CC7V-T1A-2Pin_3.2x1.5mm | Two pin crystal | IQD | 449-LFXTAL009678BULK | 0,376 |  |  |  |  |  | 0,376
Y2, |  |  |  |  |  |  |  |  |  |  |  |  |  | 0
 |  |  |  |  |  |  |  |  |  |  |  |  |  | 0
 |  |  |  |  |  |  |  |  |  |  |  |  |  | 0
 |  |  |  |  |  |  |  |  |  |  |  |  |  | 0
 |  |  |  |  |  |  |  |  |  |  |  |  |  | 0
 |  |  |  |  |  |  |  |  |  |  |  |  |  | 0
 |  |  |  |  |  |  |  |  |  |  |  |  |  | 0
 |  |  |  |  |  |  |  |  |  |  |  |  |  | 0
 |  |  |  |  |  |  |  |  |  |  |  |  |  | 114,271

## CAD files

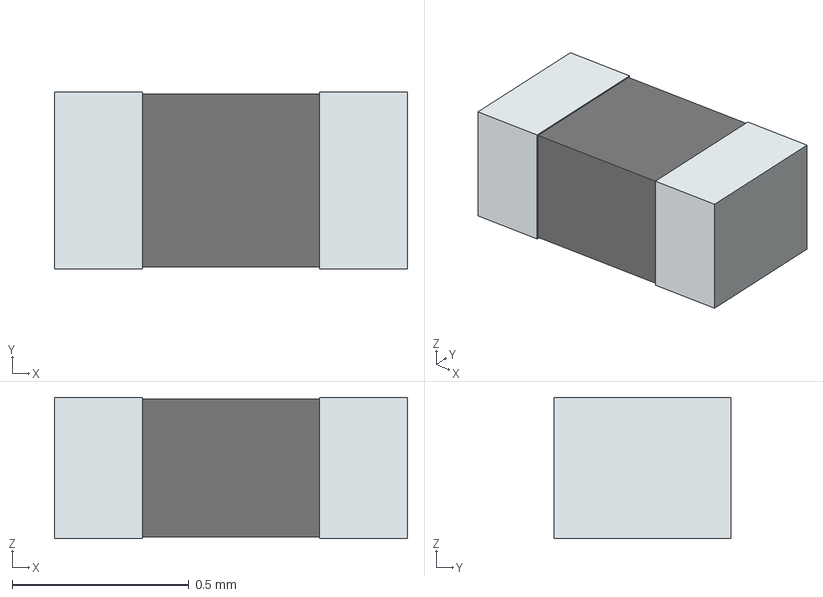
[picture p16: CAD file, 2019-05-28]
Hardware/Biblotheken/RS SMD/3D-Modelle/SMD RCL/0402.stp
1.00 x 0.5 x 0.4 mm
term1
term2

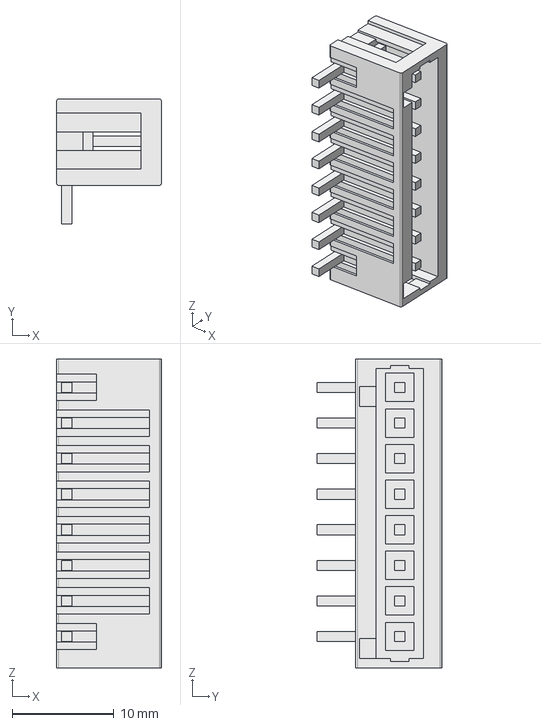
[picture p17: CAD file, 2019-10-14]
Hardware/Biblotheken/WAGO/3D-Modelle/734-168.stp
10.3 x 12.3 x 30.4 mm

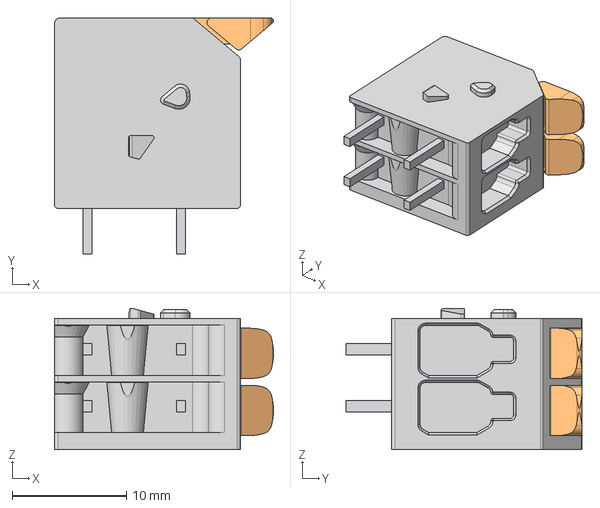
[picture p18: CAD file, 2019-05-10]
Hardware/Biblotheken/WAGO/3D-Modelle/WAGO Klemmleisten Hebel/WAGO_Klemmleiste_Hebel4Horizontal_RM5mm_2-10-pol/2604-1102/2604-1102.stp
19.2 x 20.7 x 12.4 mm

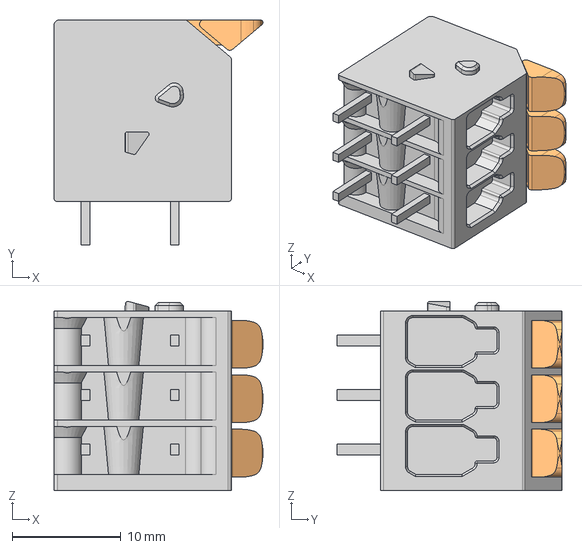
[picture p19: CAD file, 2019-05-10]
Hardware/Biblotheken/WAGO/3D-Modelle/WAGO Klemmleisten Hebel/WAGO_Klemmleiste_Hebel4Horizontal_RM5mm_2-10-pol/2604-1103/2604-1103.stp
19.2 x 20.7 x 17.4 mm

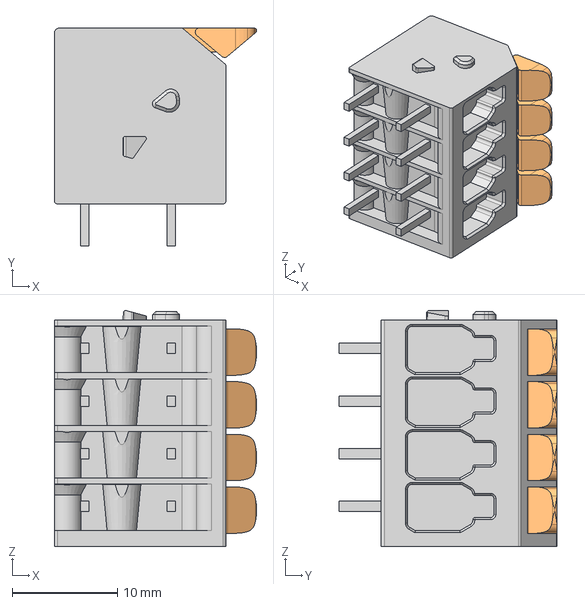
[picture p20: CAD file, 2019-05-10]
Hardware/Biblotheken/WAGO/3D-Modelle/WAGO Klemmleisten Hebel/WAGO_Klemmleiste_Hebel4Horizontal_RM5mm_2-10-pol/2604-1104/2604-1104.stp
19.2 x 20.7 x 22.4 mm

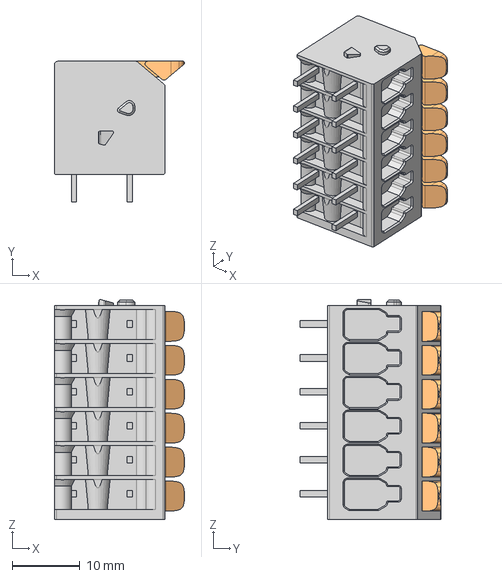
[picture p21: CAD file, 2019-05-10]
Hardware/Biblotheken/WAGO/3D-Modelle/WAGO Klemmleisten Hebel/WAGO_Klemmleiste_Hebel4Horizontal_RM5mm_2-10-pol/2604-1106/2604-1106.stp
19.2 x 20.7 x 32.4 mm

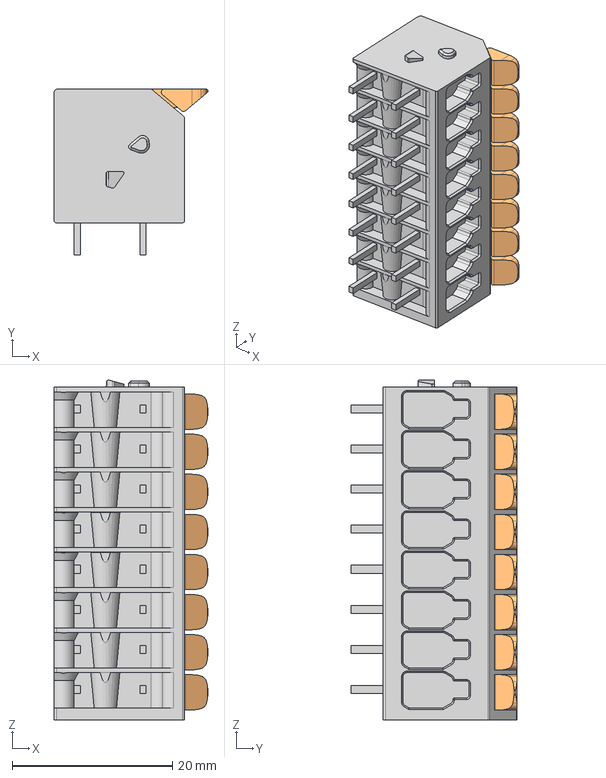
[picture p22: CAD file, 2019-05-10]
Hardware/Biblotheken/WAGO/3D-Modelle/WAGO Klemmleisten Hebel/WAGO_Klemmleiste_Hebel4Horizontal_RM5mm_2-10-pol/2604-1108/2604-1108.stp
19.2 x 20.7 x 42.4 mm

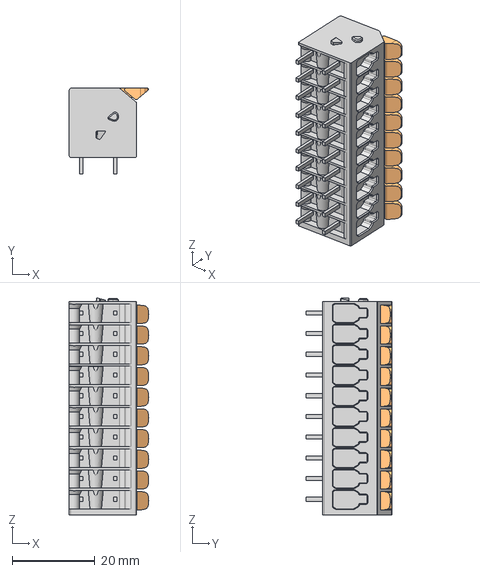
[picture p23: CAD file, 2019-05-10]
Hardware/Biblotheken/WAGO/3D-Modelle/WAGO Klemmleisten Hebel/WAGO_Klemmleiste_Hebel4Horizontal_RM5mm_2-10-pol/2604-1110/2604-1110.stp
19.2 x 20.7 x 52.4 mm

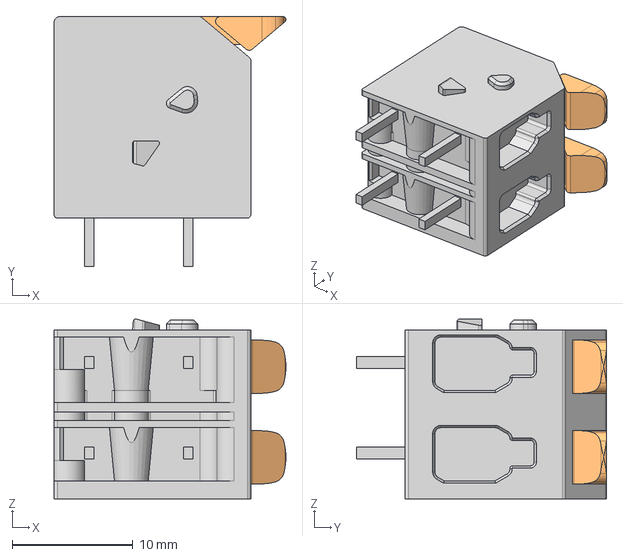
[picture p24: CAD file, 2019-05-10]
Hardware/Biblotheken/WAGO/3D-Modelle/WAGO Klemmleisten Hebel/WAGO_Klemmleiste_Hebel4Horizontal_RM7,5mm_2-10-pol/2604-1302/2604-1302.stp
19.2 x 20.7 x 14.9 mm

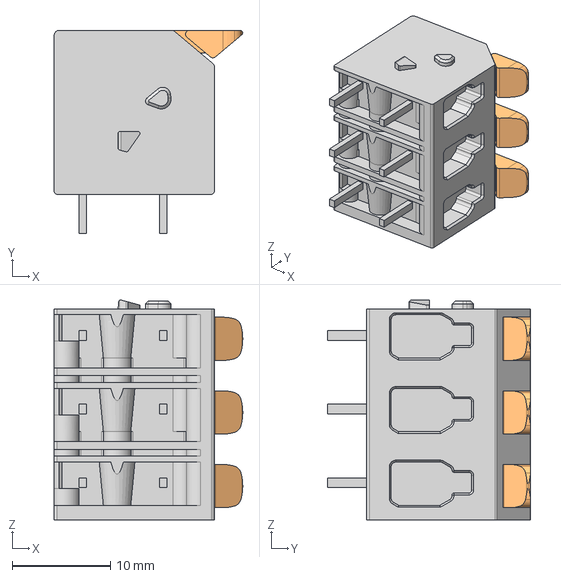
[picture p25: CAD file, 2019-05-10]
Hardware/Biblotheken/WAGO/3D-Modelle/WAGO Klemmleisten Hebel/WAGO_Klemmleiste_Hebel4Horizontal_RM7,5mm_2-10-pol/2604-1303/2604-1303.stp
19.2 x 20.7 x 22.4 mm

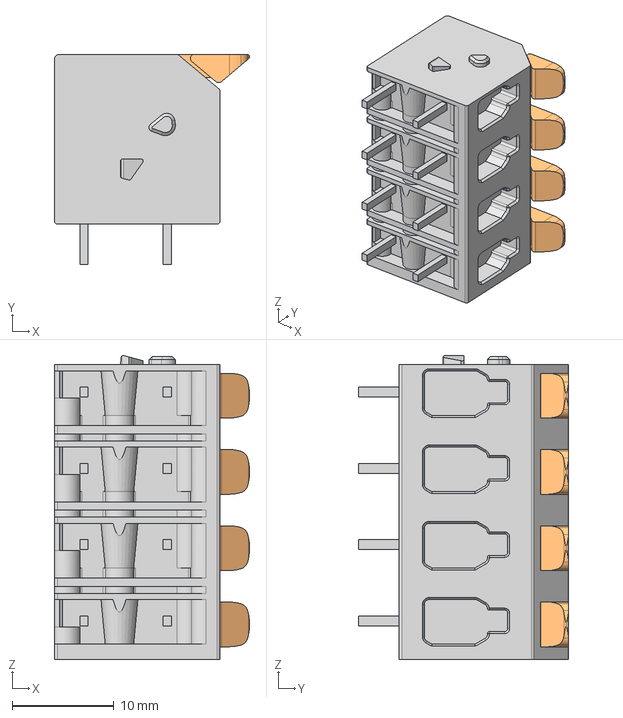
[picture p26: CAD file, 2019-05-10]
Hardware/Biblotheken/WAGO/3D-Modelle/WAGO Klemmleisten Hebel/WAGO_Klemmleiste_Hebel4Horizontal_RM7,5mm_2-10-pol/2604-1304/2604-1304.stp
19.2 x 20.7 x 29.9 mm

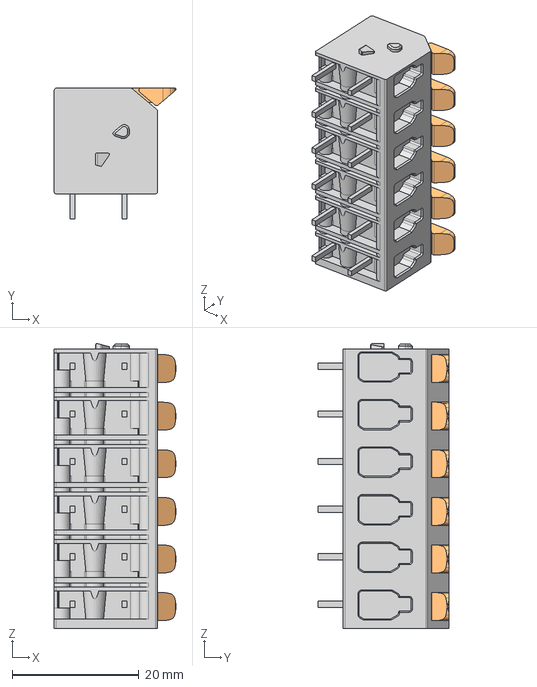
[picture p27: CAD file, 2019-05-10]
Hardware/Biblotheken/WAGO/3D-Modelle/WAGO Klemmleisten Hebel/WAGO_Klemmleiste_Hebel4Horizontal_RM7,5mm_2-10-pol/2604-1306/2604-1306.stp
19.2 x 20.7 x 44.9 mm

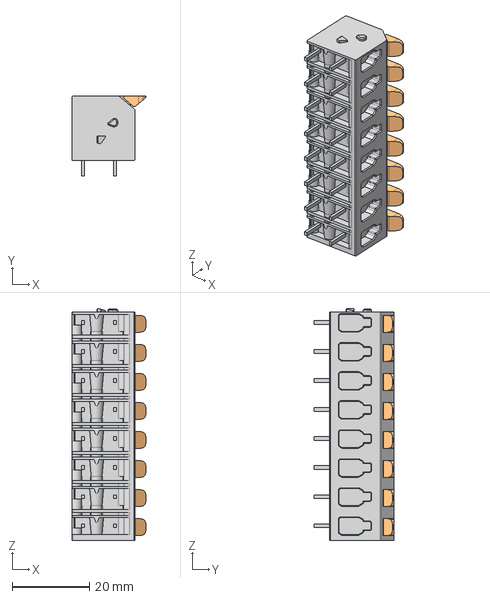
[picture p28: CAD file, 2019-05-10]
Hardware/Biblotheken/WAGO/3D-Modelle/WAGO Klemmleisten Hebel/WAGO_Klemmleiste_Hebel4Horizontal_RM7,5mm_2-10-pol/2604-1308/2604-1308.stp
19.2 x 20.7 x 59.9 mm

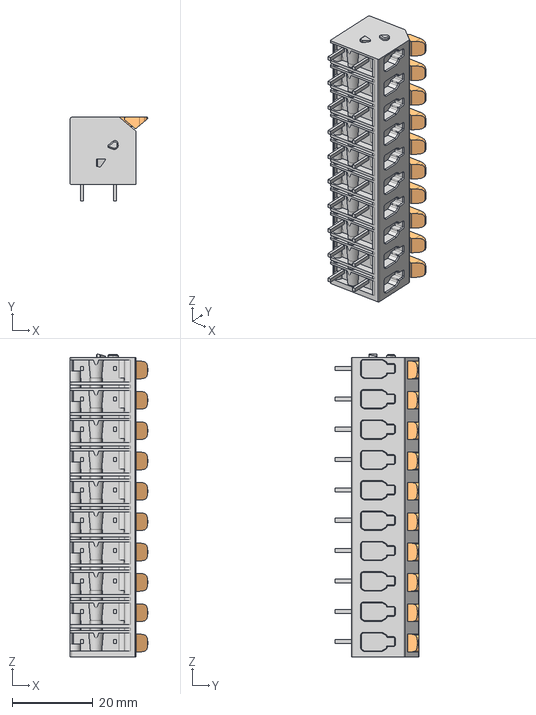
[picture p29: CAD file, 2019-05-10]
Hardware/Biblotheken/WAGO/3D-Modelle/WAGO Klemmleisten Hebel/WAGO_Klemmleiste_Hebel4Horizontal_RM7,5mm_2-10-pol/2604-1310/2604-1310.stp
19.2 x 20.7 x 74.9 mm

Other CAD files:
Hardware/Biblotheken/WAGO/3D-Modelle/WAGO Klemmleisten Hebel/WAGO_Klemmleiste_Hebel4Vertikal_RM5mm_2-10-pol/2604-3102/2604-3102.stp
Hardware/Biblotheken/WAGO/3D-Modelle/WAGO Klemmleisten Hebel/WAGO_Klemmleiste_Hebel4Vertikal_RM5mm_2-10-pol/2604-3103/2604-3103.stp
Hardware/Biblotheken/WAGO/3D-Modelle/WAGO Klemmleisten Hebel/WAGO_Klemmleiste_Hebel4Vertikal_RM5mm_2-10-pol/2604-3104/2604-3104.stp
Hardware/Biblotheken/WAGO/3D-Modelle/WAGO Klemmleisten Hebel/WAGO_Klemmleiste_Hebel4Vertikal_RM5mm_2-10-pol/2604-3106/2604-3106.stp
Hardware/Biblotheken/RS SMD/3D-Modelle/SMD RCL/0201.stp
Hardware/Biblotheken/RS SMD/3D-Modelle/SMD RCL/0603.stp
Hardware/Biblotheken/RS SMD/3D-Modelle/SMD RCL/0805.stp
Hardware/Biblotheken/RS SMD/3D-Modelle/SMD RCL/1206.stp
Hardware/Biblotheken/RS SMD/3D-Modelle/SMD RCL/C_0201.stp
Hardware/Biblotheken/RS SMD/3D-Modelle/SMD RCL/C_0402.stp
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

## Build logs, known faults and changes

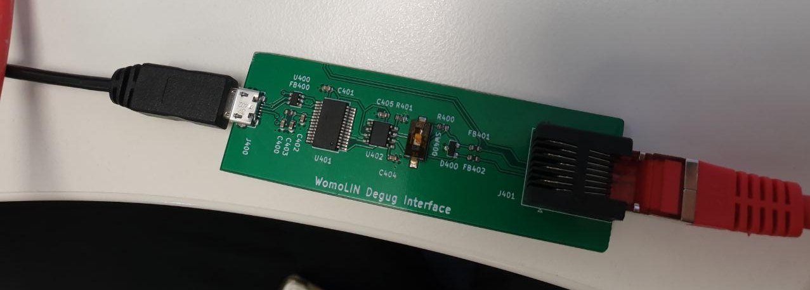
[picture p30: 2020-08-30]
Doc/pics/control_debug_interface_cutted.jpg

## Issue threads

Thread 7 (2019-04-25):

Sensor for automotive battery?

probonopd, 2019-04-25:
In the conference talk, a sensor for automotive batteries was mentioned. What is the exact name of this sensor? Thanks 👍

morawekj, 2019-04-26:
Yes, this is the same, there is a lot of sensors out, some habe a little bit different Type number, this are Car manufactors Version, that also works, some have ID 1 or 2. IBS200X is the global name for all.

betz, 2019-10-05:
very inerested, was the converence talk recorded? Any notes or article available?

probonopd, 2019-10-05:
I think this is it: https://media.ccc.de/v/eh19-167-open-souce-control-fr-camping-fahrzeuge#t=965

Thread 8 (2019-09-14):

Sensor on non Battery source

KnKay, 2019-09-14:
Hi,

quick one. I try to get some data out of the IBS sensor. Used your links to get some snippets.
Some how I get a bunch of ff:00:00:00 answers from the sensor.

Made the wiring like the other guys.

Could using a "normal" power supply or Lipo be the source of my problem? Wil lthe sensor do anything once not on a car battery?
I try to get the root of my issue. :(

Kinds

Kay!

morawekj, 2019-09-16:
normaly, this sensors are for PB Batterys, they will not work on lion battery or power supply, you may have a schematic of your setup ?

KnKay, 2019-09-17:
Okay. Maybe this is the issue. I just replaced the PB one with a lip, adding GND and VCC on the PINS of the sensor. No real schematic at the moment.

Will retry once I have the correct battery. It is just placed in where it is used. So I guiess I need to work on this outdoor the next days.

Will keep this open, as I may post my findings late on!

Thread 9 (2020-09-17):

Fixed Wiki formatting

dignifiedquire, 2020-09-17:
Fixes for formatting of https://github.com/muccc/WomoLIN/wiki/Zubeh%C3%B6r-Beta-Test-Board-V2

## Raw

```md
Steckverbindersatz Womo-LIN Conrolboard V2.0

Reichelt Bestellnummern:

|Name  |Anzahl | Artikel-Nr.        | Beschreibung                                  |
|------|-|--------------------------|-----------------------------------------------|
|DC In |1| WAGO 734-204| CAGE-CLAMP Federleiste, Mini, RM 3,81, 4-polig|
|High/Side SW - Extern Relais |2| Artikel-Nr.: WAGO 734-108| CAGE-CLAMP Federleiste, Mini, RM 3,5, 8-pol|
|Relais K1-4 |4| WAGO 734-103 |CAGE-CLAMP Federleiste, Mini, RM 3,5, 3-polig|
|Digital I/O - Analog In |2| WAGO 733-110 | CAGE-CLAMP Federleiste, Micro, RM 2,5, 10-pol.|
|1-Wire - TTY - LIN |5| WAGO 733-108 |CAGE-CLAMP Federleiste, Micro, RM 2,5, 8-polig|
|RS485 - Shitty AddOn |3|  WAGO 733-106 |CAGE-CLAMP Federleiste, Micro, RM 2,5, 6-polig|
|CAN |1| WAGO 733-103 |CAGE-CLAMP Federleiste, Micro, RM 2,5, 3-polig|

Sonstiges:

|Name  |Anzahl | Artikel-Nr.        | Beschreibung                                  |
|------|-|--------------------------|-----------------------------------------------|
|KFZ Sicherung 10A |2| LITT 0287010 |KFZ-Sicherung, ATO, 10 A, rot|

ST-Link V2, passt direkt auf 20 Pin ARM Stecker
ARCELI ST-LINK / V2 (CN-Version) ST MCU-Mikrocontroller STM8 STM32 JTAG SWD Swim In-Circuit-Debugger-Programmierer-Emulator von Guangzhouxinqinwangluokeji [Amazon.de](amazon.de/dp/B07RKVM7H8/ref=cm_sw_em_r_mt_dp_kJ-mFbMMMWH3N)

```

## Preview

Steckverbindersatz Womo-LIN Conrolboard V2.0

Reichelt Bestellnummern:

|Name  |Anzahl | Artikel-Nr.        | Beschreibung                                  |
|------|-|--------------------------|-----------------------------------------------|
|DC In |1| WAGO 734-204| CAGE-CLAMP Federleiste, Mini, RM 3,81, 4-polig|
|High/Side SW - Extern Relais |2| Artikel-Nr.: WAGO 734-108| CAGE-CLAMP Federleiste, Mini, RM 3,5, 8-pol|
|Relais K1-4 |4| WAGO 734-103 |CAGE-CLAMP Federleiste, Mini, RM 3,5, 3-polig|
|Digital I/O - Analog In |2| WAGO 733-110 | CAGE-CLAMP Federleiste, Micro, RM 2,5, 10-pol.|
|1-Wire - TTY - LIN |5| WAGO 733-108 |CAGE-CLAMP Federleiste, Micro, RM 2,5, 8-polig|
|RS485 - Shitty AddOn |3|  WAGO 733-106 |CAGE-CLAMP Federleiste, Micro, RM 2,5, 6-polig|
|CAN |1| WAGO 733-103 |CAGE-CLAMP Federleiste, Micro, RM 2,5, 3-polig|

Sonstiges:

|Name  |Anzahl | Artikel-Nr.        | Beschreibung                                  |
|------|-|--------------------------|-----------------------------------------------|
|KFZ Sicherung 10A |2| LITT 0287010 |KFZ-Sicherung, ATO, 10 A, rot|

ST-Link V2, passt direkt auf 20 Pin ARM Stecker
ARCELI ST-LINK / V2 (CN-Version) ST MCU-Mikrocontroller STM8 STM32 JTAG SWD Swim In-Circuit-Debugger-Programmierer-Emulator von Guangzhouxinqinwangluokeji [Amazon.de](amazon.de/dp/B07RKVM7H8/ref=cm_sw_em_r_mt_dp_kJ-mFbMMMWH3N)

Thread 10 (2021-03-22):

Simple LIN bus record/replay

laserir, 2021-03-22:
Hi there,
very advanced hard- and software indeed! Very impressed!

I have a Truma Contol 4 Heater and Truma A/C operating with the Truma iNet Box and  intend to switch the iNet Box for a custom solution, but much more basic.

First question: Have you already successfully reverse engineered the LIN protocol messages for control the Truma heater/A/Cs?
Second question: Which possibilities do you see/suggest to do the a simple record/playback solution? (Record the message e.g. sent when Heater is set on to xx °C etc. and simply playback to achieve exactly this operation.) With this I could save some hardcoded messages/presets. Is there some kind of shield or module (perhaps a RS485 or CAN bus module?) I could use to sniff the LIN bus and replay on this? Is the iNet box a Master and does is supply the power to the bus?

Thanks a lot in advance!

morawekj, 2021-03-22:
We had some logging, manly are 5 Frames, and you have repeat them for kepp alaive.

CP Plus is LIN Master

https://docs.google.com/spreadsheets/d/16nw7vJGL2m406Nb3y3_9kxW-dGib02PLaZ2sJC5xSz4/edit?usp=sharing

A simple Saleae Logic Analyzer (Clone also do) will do the Job for logging

laserir, 2021-03-23:
Thanks for the document! So I see the communication Heater<->Panel is on the bus. I was aiming for the iNet<->CPPlus connection. As I understand heater and a/c are connected to the CPPlus and there is a single connection to the iNet box, so I could feed commands into the system and keep the CPPlus panel. Any ideas?

laserir, 2021-03-26:
So... I got myself this —> https://www.microchip.com/developmenttools/ProductDetails/APGDT001

Do you know which line goes where on the TIN plug?
Vbat is from the 12V of the caravan I guess?

laserir, 2021-03-30:
If any useful... attached the conversion of the room temperature sensor (PID 61).
https://docs.google.com/spreadsheets/d/1c9_FCGcBeeDjsJtaojFys3Nlx2V27TBXtvGYYBC2gCw/edit?usp=sharing

The analyzer just arrived, let's see where the journey takes us.

betz, 2021-03-30:
very interesting.
Thanks for sharing

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

laserir, 2021-03-30:
Also if useful... here some analyses with all devices connected (CPPlus + Heater + A/C + iNet Box) and without iNet Box, A/C respectively...
https://docs.google.com/document/d/1cXJOo0R7dj7mbHKq1hL0edU1fNbdmElGy7ql1EkBc-k/edit?usp=sharing
Seems as iNet Box does its magic with PID "D8" and A/C with PID "97".
"7D" fails if either device is disconnected.

betz, 2021-03-30:
could you, for the record, tell how you connected everything?

The 'Microchip LIN Serial Analyzer Development Kit' to the cpplus? which
port?
Tempted to do the same.
I was first thinking to control over sms automated, but the lin protocol
would be nicer indeed.

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

laserir, 2021-03-31:
> could you, for the record, tell how you connected everything? The 'Microchip LIN Serial Analyzer Development Kit' to the cpplus? which port? Tempted to do the same. I was first thinking to control over sms automated, but the lin protocol would be nicer indeed.
> […](#)

The CPPlus is the TIN1 bus Master, iNet Box (TIN1 Ports) and devices acting as slaves.
On the TIN2 port, a separate Bus, the inet Box is Master. You should focus on the TIN1, as TIN2 is only used for in-app control.
Do not connect the CPPlus to TIN2, that would be 2 masters!

As it is a bus system, it doesn’t matter where on the bus you connect. Meaning you could connect to the TIN1 ports on the CPPlus or iNet box or even use a coupler like this: https://www.conrad.at/de/p/train-modules-75124-rj12-4fach-verteiler-loconet-fertigbaustein-497092.html

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

The connection is done via RJ12 cable:
1 -
2 -
3 LIN
4 -
5 GND
6 -

Last connection is VBatt, meaning the 12V+ of the car battery.

laserir, 2021-03-31:
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

morawekj, 2021-04-02:
We have also a Telegram Group for Truma Revere Engineering, if interestet, give me a note on Telegram @RFguy2

7xy, 2022-06-12:
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

Hi John, I realised it with Openhab 3. But I am sure that it will work also with Home Assistant which I use for reading my smart shunt. The only thing you need is a relay with a NO NC and a resistor with 10 kOhm. You just open one wire of your temperature measurement and now you can fake low temperature. So you can control your Truma heating via Home Assistant. To get an idea about this solution visit my blog under https://schleeh.de By the way I can not code either.

schwinn, 2022-08-19:
@morawekj I've update for the spreadsheet in "Frame Decoding 4.1". ID 22 D0 is the battery voltage in 1/10 Volt. Bit 0x20 of D1 is raised, when shore power is connected.

When sending data via id 7d (3d) to LIN master, the frames D6 and D7 seems to be a checksum in the data field. Have someone noticed this already?

Here are two switch off commands, which are almost the same. Only D6 and D7 of "03 22" is different, but the have both the same checksum FC again.

LIN READ  3C 3C       03 21 00 00 22 FF FF FF       B9
LIN READ  7D 3D       03 10 29 FA 00 1F 00 1E       8B
LIN READ  7D 3D       03 21 00 00 22 FF FF FF       B9
LIN READ  7D 3D       03 22 54 01 0C 32 0A 40       FC
LIN READ  7D 3D       03 23 00 00 00 00 08 07       CA
LIN READ  7D 3D       03 24 00 00 08 07 02 02       C5
LIN READ  7D 3D       03 25 00 00 00 00 00 00       D7
LIN READ  7D 3D       03 26 00 00 00 00 00 00       D6
LIN READ  20 20       AA AA AA 00 12 02 E0 0F       DB
LIN READ  61 21       D6 9B BB 28 12 02 F0 0F       34

LIN READ  3C 3C       03 21 00 00 22 FF FF FF       B9
LIN READ  7D 3D       03 10 29 FA 00 1F 00 1E       8B
LIN READ  7D 3D       03 21 00 00 22 FF FF FF       B9
LIN READ  7D 3D       03 22 54 01 0C 32 0D 3D       FC
LIN READ  7D 3D       03 23 00 00 00 00 08 07       CA
LIN READ  7D 3D       03 24 00 00 08 07 02 02       C5
LIN READ  7D 3D       03 25 00 00 00 00 00 00       D7
LIN READ  7D 3D       03 26 00 00 00 00 00 00       D6
LIN READ  20 20       AA AA AA 00 12 02 E0 0F       DB

Changing D6 or/and D7 to something random and the CP Plus will ignore the command, even if the frame checksum is valid.

danielfett, 2022-09-21:
The checksum is calculated just the same as the LIN bus checksum, but over all bytes in the LIN Transport Layer message (starting with 00 1E). The checksum byte itself must be set to 00 or be ignored for the checksum calculation.

danielfett, 2022-09-23:
The first checksum is a random number probably to identify the message. Each 0C 32 message will be confirmed by a 02 0D message later on repeating the same random number.

schwinn, 2022-09-29:
I had already found out about the checksum in D7. Controlling the heating via the lin bus now works very well. If you look at the logs in the folder trumalogs and pay attention to the timestamp, the byte D6 seems to be a counter that is incremented by one with each command. Thanks for the info with the "02 0D" command. I hadn't noticed the D6 byte there.

danielfett, 2022-09-29:
Thanks for the update, @schwinn!
I have published a working inetbox emulation here: https://github.com/danielfett/inetbox.py
If you like, feel free to contribute!

schwinn, 2022-10-06:
Thanks for the link @danielfett
Your implementation looks awesome. I do the LIN communication with a teensy 3.2 microcontroller, which acts as a gateway to the NMEA2000 CAN bus and my 3C/3D transport protocol code is a way more basic.

amaral989, 2022-10-06:
How can someone like me with very limited knowledge , can implement this
into home assistant and communicate with truma .
It's my missing link to complete this rv project

Thank you
John

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

Thi3rryzz, 2022-11-21:
Hi all,
I'm currently trying to figure out the right command set for a Dometic Freshwell 3000 unit.
I thought it would use the same subset of commands as the Dometic Freshjet series.
However, when I send a command with ID 17 using the APGDT001 tool, it seems that the packet gets corrupted during transfer.
Any other command does transmit fine over the bus. (confirmed with Saleae logic analyzer)

Does anyone have experience with communicating with a Freshwell 3000?
Thanks in advance!
Thierry

mc0110, 2022-11-21:
Hi,
I think you're in the wrong repo here - this is all about TRUMA logic, please.

Thi3rryzz, 2022-11-21:
Ah I'm sorry,
I saw some CI-bus packet captures in the Excel sheet linked above, so thought it was also relevant.

Excuse me.

stepir, 2023-03-24:
Thanks @laserir for your posts - give me hope in buying hw for doing something similar on Alde heating systems. Unfortunately in my case I cannot use the iNet box or emulation as my Alde won't support it. However it support an external panel communicating most probably over a LIN bus connection.

Based on your input I'll probably go ahead and purchase also the same analyser https://www.microchip.com/en-us/development-tool/APGDT001

RobinSkoge, 2023-04-26:
Hi everyone,

I am looking for help to find an error (apparently in the communication between a camper unit and the CP Plus I-NET - Combi Control - TWIN PORT).

Problem: Many of these campervans have reported that when setting the e.g. temerature via the camper unit (which communicates through the seondary TIN connector) the Truma periodically, however, randomly shuts off. This without giving an error code. The Truma lets itself re-start as if nothing has happend. While this is a problem, when e.g. you are relying on constant temperature / heating e.g. in winter, a work around is to unplugg the RJ connector to the Camper Unit and the Truma does run without problems.

Hence, the problem seems some sort of signal / output from the camperunit at any given point to the Truma.
I want to (kind of man-in-the-middle style) monitor all communication that is send to the Truma from the CU.

Anychance you could guide me into the right direction?

Thanks and regards
Robin

olivluca, 2023-11-01:
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

Is this the latest version or is there some new data available somewhere else?
I don't have a CP-Plus and I'd like to implement something like
https://github.com/Harry-58/Truma_CP-_Simulator
(actually I already adapted it to an ESP32 I had lying around and I'm waiting for the lin to uart converter to arrive).

Ci-Mac, 2023-11-04:
Hi guys, I have a problem - maybe you can help me to solve.
I left my caravan far away from me, and for some reason Truma application has reset and I can not establish GSM connection with iNet box without bluetooth connection. I can of course send messages from SMS dialog window. Problem is that I need to switch on heating to 5 degrees. In message history I only have message with 22.0 degrees. When I do "copy/paste" with changing 22.0 to 5.0 iNet responds with my original message (like forward). Does not change heating parameters. I think problem is with checksums or somewhere in HEX numbers I do not finally understand.

Message which works fine:

Dear iNet Box, switch on the Alde system, set temp. 22.0C, hot water OFF, ACC OFF with electr. 3kW and gas OFF. Thanks & Regards, XXX 0x3c9a092391

How to modify to 5.0C?

Thanks in advance ;)

HGordonH, 2024-02-26:
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

Did you find a solution?

Paulb-prog, 2024-08-03:
@Thi3rryzz

> Hi all, I'm currently trying to figure out the right command set for a Dometic Freshwell 3000 unit. I thought it would use the same subset of commands as the Dometic Freshjet series. However, when I send a command with ID 17 using the APGDT001 tool, it seems that the packet gets corrupted during transfer. Any other command does transmit fine over the bus. (confirmed with Saleae logic analyzer)
>
> Does anyone have experience with communicating with a Freshwell 3000? Thanks in advance! Thierry

I have the same ac, did you solve the problem?

Thi3rryzz, 2024-08-05:
@Paulb-prog
Yes I did. It does use the same command set as the freshjet series. (as described in morawekj's google sheet)
What resolved my issue was sending a sync bit (bit 2 of byte 7 of the control frame 0x08)

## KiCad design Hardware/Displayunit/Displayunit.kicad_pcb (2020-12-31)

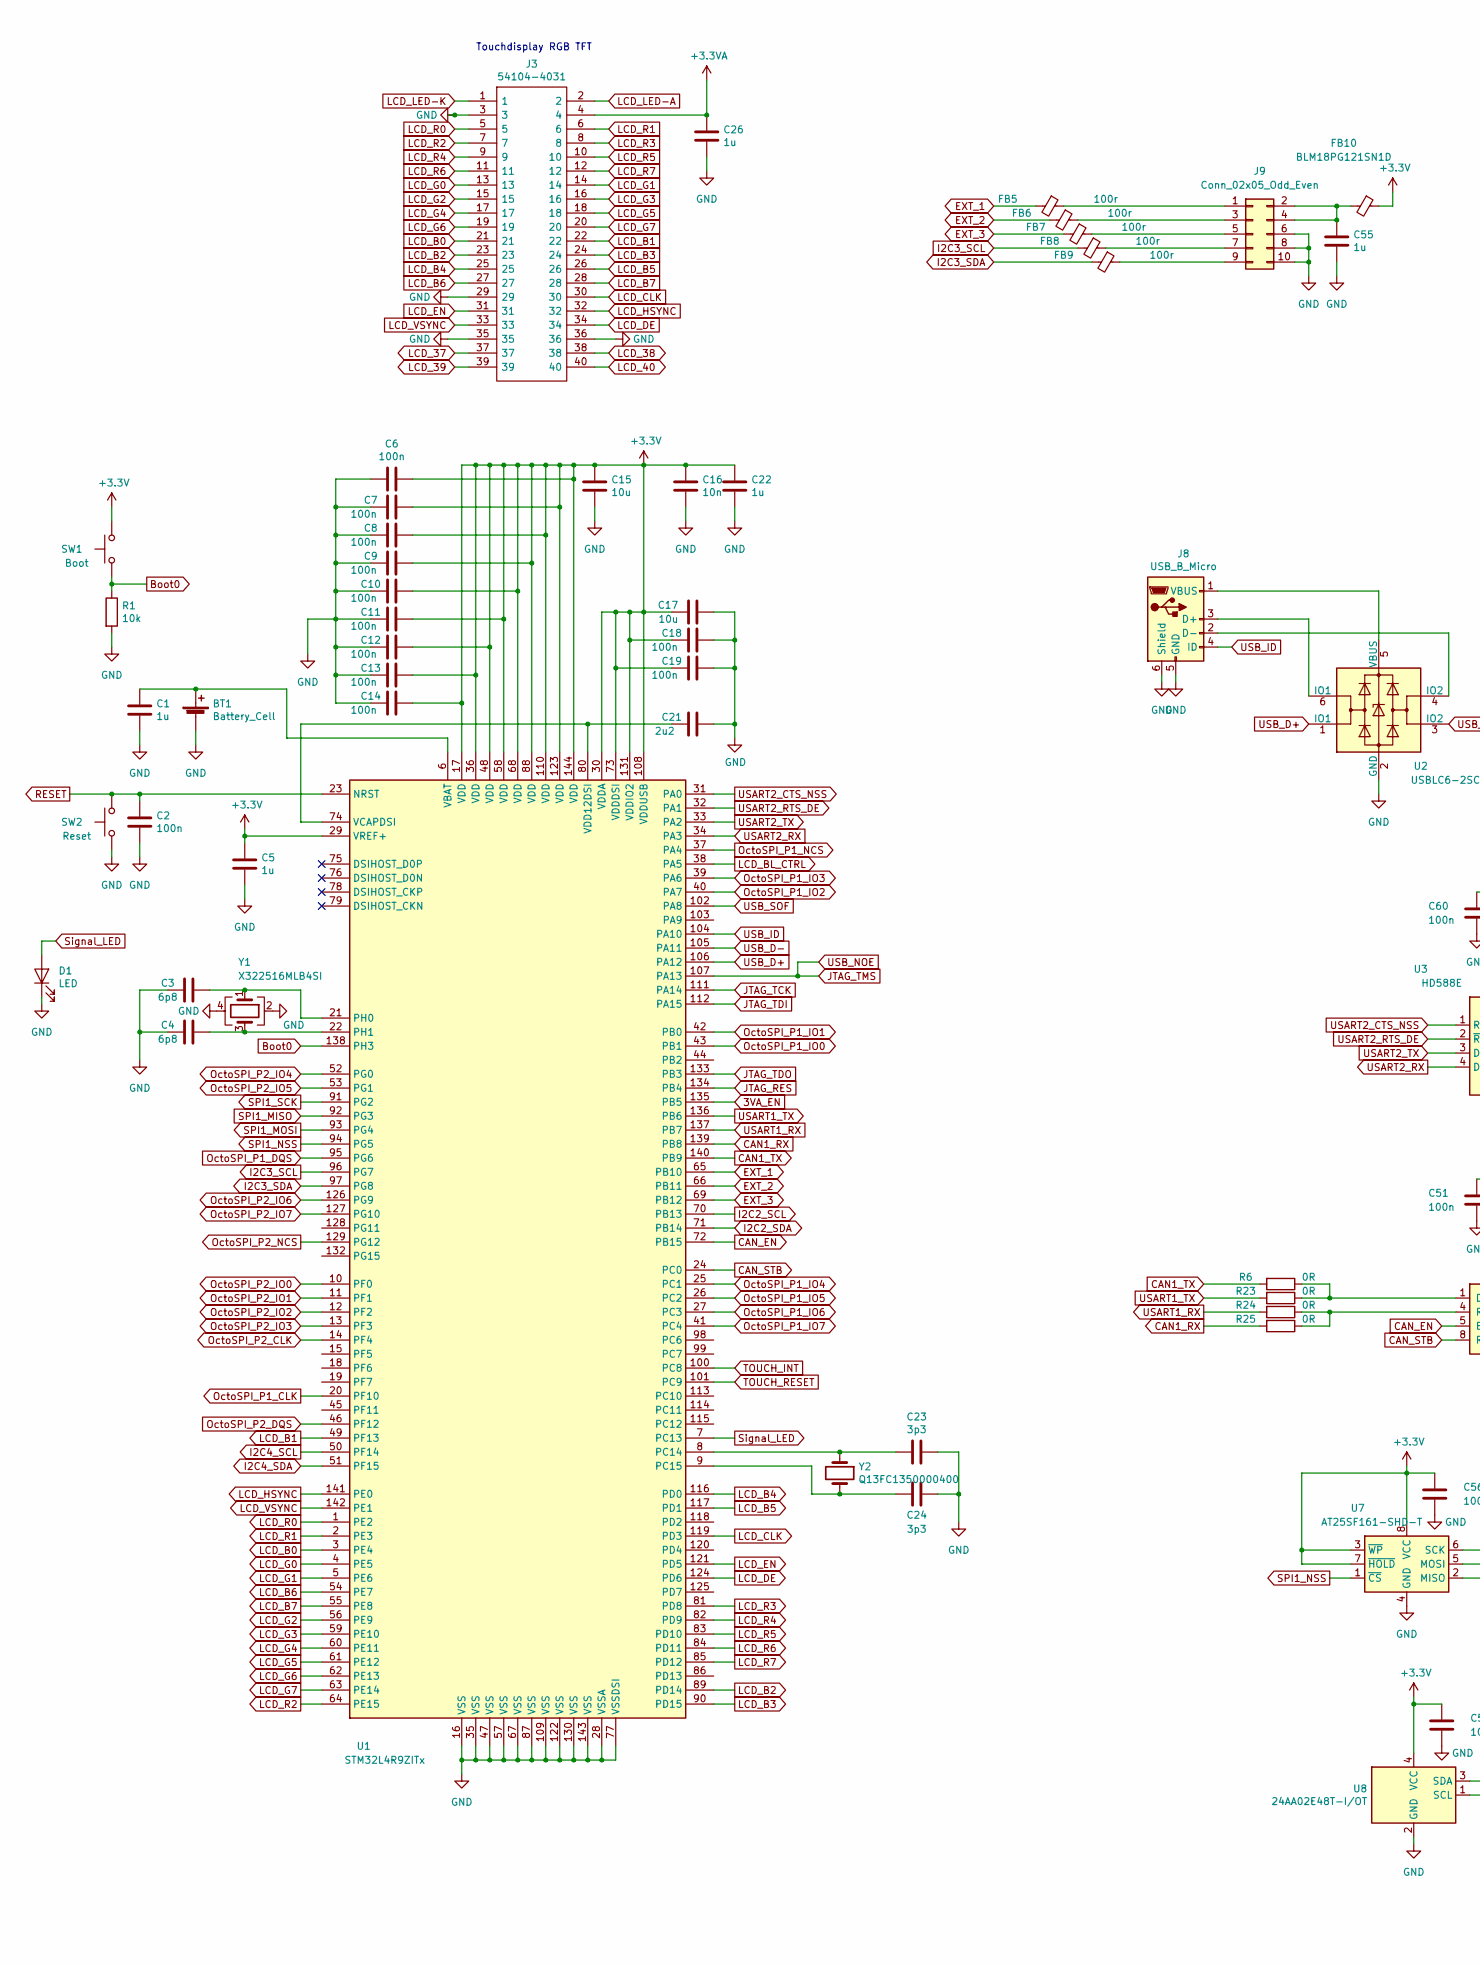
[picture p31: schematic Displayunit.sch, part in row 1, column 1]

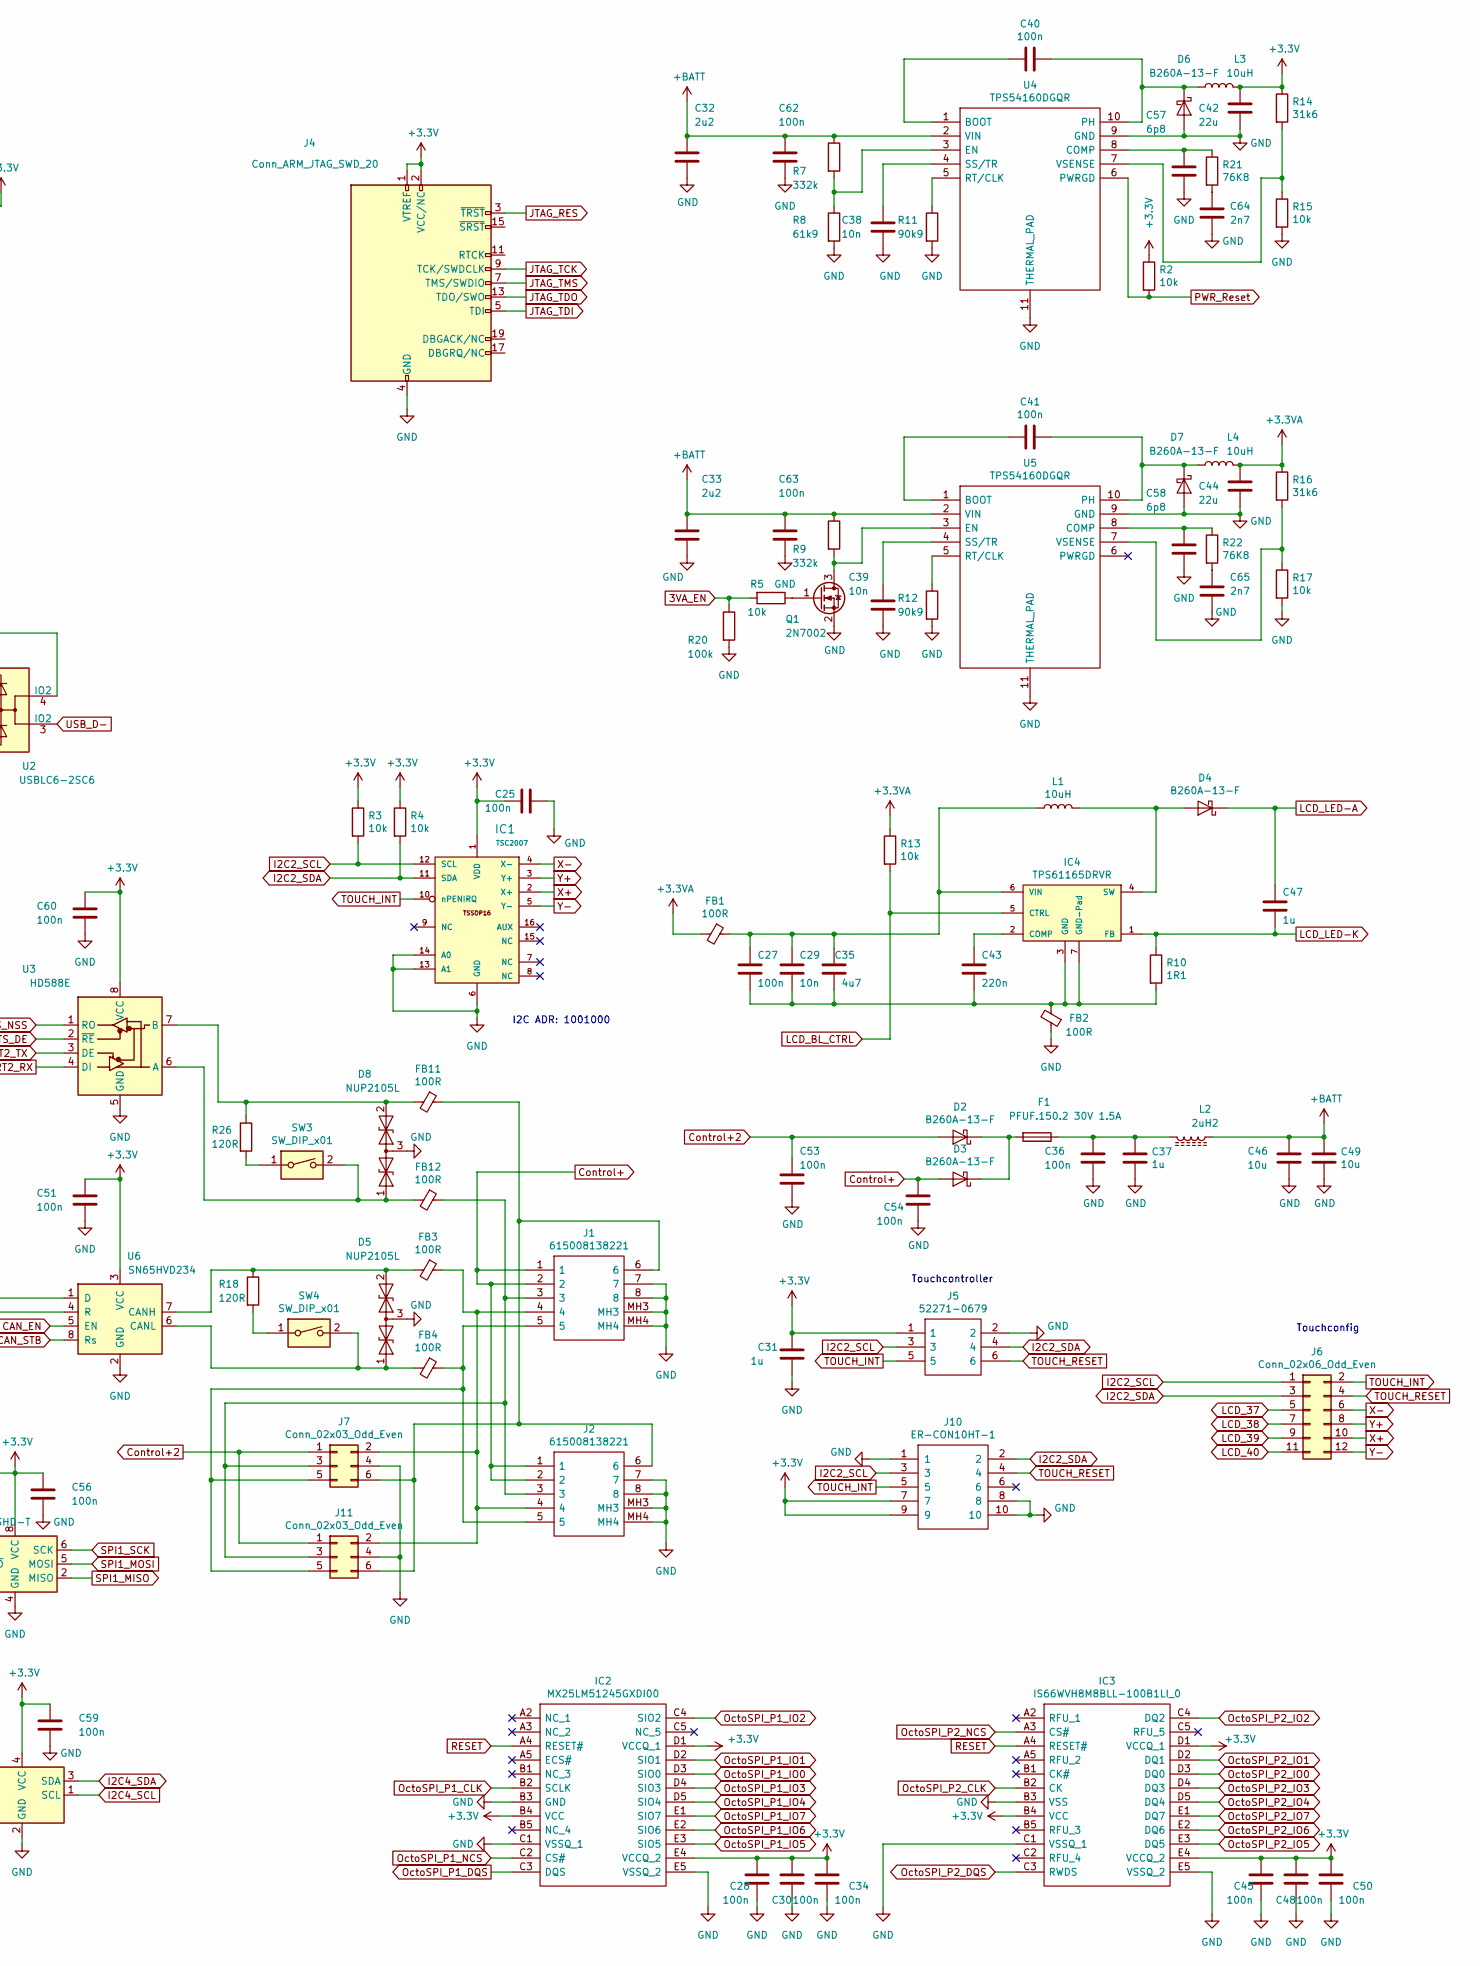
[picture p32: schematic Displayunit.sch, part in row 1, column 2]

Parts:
BT1: Battery_Cell; QJ.BS-6
C1, C22, C26, C31, C37, C55: 1u; C_1206_3216Metric
C2, C6, C7, C8, C9, C10, C11, C12, C13, C14, C18, C19, C25, C27, C28, C30, C34, C36, C40, C41, C45, C48, C50, C51, C53, C54, C56, C59, C60, C62, C63: 100n; C_0603_1608Metric
C3, C4, C57, C58: 6p8; C_0603_1608Metric
C5: 1u; C_0603_1608Metric
C15, C17: 10u; C_1206_3216Metric
C16, C29, C38, C39: 10n; C_0603_1608Metric
C21, C32, C33: 2u2; C_1210_3225Metric
C23, C24: 3p3; C_0603_1608Metric
C35: 4u7; C_1210_3225Metric
C42, C44: 22u; C_1210_3225Metric
C43: 220n; C_0603_1608Metric
C46, C49: 10u; C_1210_3225Metric
C47: 1u; C_1210_3225Metric
C64, C65: 2n7; C_0603_1608Metric
D1: LED; LED_1206_3216Metric
D2, D3, D4, D6, D7: B260A-13-F; D_SMB
D5, D8: NUP2105L; SOT-23
F1: PFUF.150.2 30V 1.5A; Fuse_1210_3225Metric
FB1, FB2, FB3, FB4, FB11, FB12: 100R; L_0603_1608Metric
FB5, FB6, FB7, FB8, FB9: 100r; L_0603_1608Metric
FB10: BLM18PG121SN1D; L_0603_1608Metric
IC1: TSC2007; TSSOP-16_4.4x5mm_P0.65mm
IC2: MX25LM51245GXDI00; BGA24C100P5X5_600X800X35; Manufacturer_Part_Number MX25LM51245GXDI00
IC3: IS66WVH8M8BLL-100B1LI_0; BGA24C100P5X5_600X800X35; Manufacturer_Part_Number IS66WVH8M8BLL-100B1LI
IC4: TPS61165DRVR; WSON-6-1EP_2x2mm_P0.65mm_EP1x1.6mm_ThermalVias
J1, J2: 615008138221; Mouser Part Number 710-615008138221
J3: 54104-4031; Mouser Part Number 538-54104-4031
J4: Conn_ARM_JTAG_SWD_20; IDC-Header_2x10_P2.54mm_Vertical
J5: 52271-0679; Mouser Part Number 538-52271-0679
J6: Conn_02x06_Odd_Even; PinHeader_2x06_P2.54mm_Vertical
J7, J11: Conn_02x03_Odd_Even; Molex_Micro-Fit_3.0_43045-0612_2x03_P3.00mm_Vertical
J8: USB_B_Micro; USB_Micro-B_Molex-105017-0001
J9: Conn_02x05_Odd_Even; IDC-Header_2x05_P2.54mm_Vertical
J10: ER-CON10HT-1
L1, L3, L4: 10uH; MWSA0503
L2: 2uH2; MWSA0603
Q1: 2N7002; SOT-23
R1, R2, R3, R4, R5, R13, R15, R17: 10k; R_0603_1608Metric
R6, R23, R24, R25: 0R; R_0603_1608Metric
R7, R9: 332k; R_0603_1608Metric
R8: 61k9; R_0603_1608Metric
R10: 1R1; R_1206_3216Metric
R11, R12: 90k9; R_0603_1608Metric
R14, R16: 31k6; R_0603_1608Metric
R18, R26: 120R; R_0603_1608Metric
R20: 100k; R_0603_1608Metric
R21, R22: 76K8; R_0603_1608Metric
SW1: Boot; TS-1187A
SW2: Reset; TS-1187A
SW3, SW4: SW_DIP_x01; SW_SPST_CK_RS282G05A3
U1: STM32L4R9ZITx; LQFP-144_20x20mm_P0.5mm
U2: USBLC6-2SC6; SOT-23-6
U3: HD588E; SOIC-8_3.9x4.9mm_P1.27mm
U4, U5: TPS54160DGQR; SOP50P490X110-11N; Mouser Part Number 595-TPS54160DGQR
U6: SN65HVD234; SOIC-8_3.9x4.9mm_P1.27mm
U7: AT25SF161-SHD-T; SO-8_5.3x6.2mm_P1.27mm
U8: 24AA02E48T-I/OT; SOT-23-5
Y1: X322516MLB4SI; Crystal_SMD_3225-4Pin_3.2x2.5mm
Y2: Q13FC1350000400; Crystal_SMD_MicroCrystal_CC7V-T1A-2Pin_3.2x1.5mm

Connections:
3VA_EN: R5.2, R20.1, U1.135 (PB5)
+3.3VA: C26.1, C44.1, FB1.2, J3.4, L4.2, R13.1, R16.1
+3V3: C5.1, C6.1, C7.1, C8.1, C9.1, C10.1, C11.1, C12.1, C13.1, C14.1, C15.1, C16.1, C17.1, C18.2, C19.2, C22.1, C25.2, C28.1, C30.1, C31.1, C34.1, C42.1, C45.1, C48.1, C50.1, C51.1, C56.1, C59.1, C60.1, FB10.1, IC1.1 (VDD), IC2.B4 (VCC), IC2.D1 (VCCQ_1), IC2.E4 (VCCQ_2), IC3.B4 (VCC), IC3.D1 (VCCQ_1), IC3.E4 (VCCQ_2), J4.1 (VTREF), J4.2 (VCC/NC), J5.1, J10.7, J10.9, L3.2, R2.1, R3.1, R4.1, R14.1, SW1.2, U1.17 (VDD), U1.29 (VREF+), U1.30 (VDDA), U1.36 (VDD), U1.48 (VDD), U1.58 (VDD), U1.68 (VDD), U1.73 (VDDDSI), U1.88 (VDD), U1.108 (VDDUSB), U1.110 (VDD), U1.123 (VDD), U1.131 (VDDIO2), U1.144 (VDD), U3.8 (VCC), U6.3 (VCC), U7.3 (~WP), U7.7 (~HOLD), U7.8 (VCC), U8.4 (VCC)
+BATT: C32.1, C33.1, C46.1, C49.1, C62.1, C63.1, L2.1, R7.1, R9.1, U4.2 (VIN), U5.2 (VIN)
Boot0: R1.1, SW1.1, U1.138 (PH3)
CAN1_RX: R25.2, U1.139 (PB8)
CAN1_TX: R6.2, U1.140 (PB9)
CAN_EN: U1.72 (PB15), U6.5 (EN)
CAN_STB: U1.24 (PC0), U6.8 (Rs)
Control+: C54.1, D3.2 (A), J1.1, J1.2, J2.1, J2.2
Control+2: C53.1, D2.2 (A), J7.1, J11.1
EXT_1: FB5.2, U1.65 (PB10)
EXT_2: FB6.2, U1.66 (PB11)
EXT_3: FB7.2, U1.69 (PB12)
GND: BT1.2 (-), C1.2, C2.2, C3.2, C4.2, C5.2, C6.2, C7.2, C8.2, C9.2, C10.2, C11.2, C12.2, C13.2, C14.2, C15.2, C16.2, C17.2, C18.1, C19.1, C21.1, C22.2, C23.1, C24.1, C25.1, C26.2, C28.2, C30.2, C31.2, C32.2, C33.2, C34.2, C36.2, C37.2, C38.2, C39.2, C42.2, C44.2, C45.2, C46.2, C48.2, C49.2, C50.2, C51.2, C53.2, C54.2, C55.2, C56.2, C57.1, C58.1, C59.2, C60.2, C62.2, C63.2, C64.1, C65.1, D1.1 (K), D5.3 (common), D6.2 (A), D7.2 (A), D8.3 (common), FB2.1, IC1.6 (GND), IC1.13 (A1), IC1.14 (A0), IC2.B3 (GND), IC2.C1 (VSSQ_1), IC2.E5 (VSSQ_2), IC3.B3 (VSS), IC3.C1 (VSSQ_1), IC3.E5 (VSSQ_2), J1.7, J1.8, J1.MH3, J1.MH4, J2.7, J2.8, J2.MH3, J2.MH4, J3.3, J3.29, J3.35, J3.36, J4.4 (GND), J4.6 (GND), J4.8 (GND), J4.10 (GND), J4.12 (GND), J4.14 (GND), J4.16 (GND), J4.18 (GND), J4.20 (GND), J5.2, J7.4, J8.5 (GND), J8.6 (Shield), J9.6, J9.8, J9.10, J10.1, J10.8, J10.10, J11.4, Q1.2 (S), R1.2, R8.2, R11.2, R12.2, R15.2, R17.2, R20.2, SW2.1, U1.16 (VSS), U1.28 (VSSA), U1.35 (VSS), U1.47 (VSS), U1.57 (VSS), U1.67 (VSS), U1.77 (VSSDSI), U1.87 (VSS), U1.109 (VSS), U1.122 (VSS), U1.130 (VSS), U1.143 (VSS), U2.2 (GND), U3.5 (GND), U4.9 (GND), U4.11 (THERMAL_PAD), U5.9 (GND), U5.11 (THERMAL_PAD), U6.2 (GND), U7.4 (GND), U8.2 (GND), Y1.2, Y1.4
I2C2_SCL: IC1.12 (SCL), J5.3, J6.1, J10.3, R3.2, U1.70 (PB13)
I2C2_SDA: IC1.11 (SDA), J5.4, J6.3, J10.2, R4.2, U1.71 (PB14)
I2C3_SCL: FB8.2, U1.96 (PG7)
I2C3_SDA: FB9.2, U1.97 (PG8)
I2C4_SCL: U1.50 (PF14), U8.1 (SCL)
I2C4_SDA: U1.51 (PF15), U8.3 (SDA)
JTAG_RES: J4.3 (~TRST~), U1.134 (PB4)
JTAG_TCK: J4.9 (TCK/SWDCLK), U1.111 (PA14)
JTAG_TDI: J4.5 (TDI), U1.112 (PA15)
JTAG_TDO: J4.13 (TDO/SWO), U1.133 (PB3)
JTAG_TMS: J4.7 (TMS/SWDIO), U1.107 (PA13)
LCD_37: J3.37, J6.5
LCD_38: J3.38, J6.7
LCD_39: J3.39, J6.9
LCD_40: J3.40, J6.11
LCD_B0: J3.21, U1.3 (PE4)
LCD_B1: J3.22, U1.49 (PF13)
LCD_B2: J3.23, U1.89 (PD14)
LCD_B3: J3.24, U1.90 (PD15)
LCD_B4: J3.25, U1.116 (PD0)
LCD_B5: J3.26, U1.117 (PD1)
LCD_B6: J3.27, U1.54 (PE7)
LCD_B7: J3.28, U1.55 (PE8)
LCD_BL_CTRL: IC4.5 (CTRL), R13.2, U1.38 (PA5)
LCD_CLK: J3.30, U1.119 (PD3)
LCD_DE: J3.34, U1.124 (PD6)
LCD_EN: J3.31, U1.121 (PD5)
LCD_G0: J3.13, U1.4 (PE5)
LCD_G1: J3.14, U1.5 (PE6)
LCD_G2: J3.15, U1.56 (PE9)
LCD_G3: J3.16, U1.59 (PE10)
LCD_G4: J3.17, U1.60 (PE11)
LCD_G5: J3.18, U1.61 (PE12)
LCD_G6: J3.19, U1.62 (PE13)
LCD_G7: J3.20, U1.63 (PE14)
LCD_HSYNC: J3.32, U1.141 (PE0)
LCD_LED-A: C47.1, D4.1 (K), J3.2
LCD_LED-K: C47.2, IC4.1 (FB), J3.1, R10.1
LCD_R0: J3.5, U1.1 (PE2)
LCD_R1: J3.6, U1.2 (PE3)
LCD_R2: J3.7, U1.64 (PE15)
LCD_R3: J3.8, U1.81 (PD8)
LCD_R4: J3.9, U1.82 (PD9)
LCD_R5: J3.10, U1.83 (PD10)
LCD_R6: J3.11, U1.84 (PD11)
LCD_R7: J3.12, U1.85 (PD12)
LCD_VSYNC: J3.33, U1.142 (PE1)
unnamed: BT1.1 (+), C1.1, U1.6 (VBAT)
unnamed: C3.1, U1.21 (PH0), Y1.1
unnamed: C4.1, U1.22 (PH1), Y1.3
unnamed: C21.2, U1.74 (VCAPDSI), U1.80 (VDD12DSI)
unnamed: C23.2, U1.8 (PC14), Y2.1
unnamed: C24.2, U1.9 (PC15), Y2.2
unnamed: C27.1, C29.1, C35.1, FB1.1, IC4.6 (VIN), L1.1
unnamed: C27.2, C29.2, C35.2, C43.2, FB2.2, IC4.3 (GND), IC4.7 (GND-Pad), R10.2
unnamed: C36.1, C37.1, F1.1, L2.2
unnamed: C38.1, U4.4 (SS/TR)
unnamed: C39.1, U5.4 (SS/TR)
unnamed: C40.1, D6.1 (K), L3.1, U4.10 (PH)
unnamed: C40.2, U4.1 (BOOT)
unnamed: C41.1, D7.1 (K), L4.1, U5.10 (PH)
unnamed: C41.2, U5.1 (BOOT)
unnamed: C43.1, IC4.2 (COMP)
unnamed: C55.1, FB10.2, J9.2, J9.4
unnamed: C57.2, R21.1, U4.8 (COMP)
unnamed: C58.2, R22.1, U5.8 (COMP)
unnamed: C64.2, R21.2
unnamed: C65.2, R22.2
unnamed: D2.1 (K), D3.1 (K), F1.2
unnamed: D4.2 (A), IC4.4 (SW), L1.2
unnamed: D5.1 (A1), FB4.2, SW4.2, U6.6 (CANL)
unnamed: D5.2 (A2), FB3.2, R18.1, U6.7 (CANH)
unnamed: D8.1 (A1), FB12.2, SW3.2, U3.6 (A)
unnamed: D8.2 (A2), FB11.2, R26.1, U3.7 (B)
unnamed: FB3.1, J1.4, J2.4, J7.2, J11.2
unnamed: FB4.1, J1.5, J2.5, J7.5, J11.5
unnamed: FB5.1, J9.1
unnamed: FB6.1, J9.3
unnamed: FB7.1, J9.5
unnamed: FB8.1, J9.7
unnamed: FB9.1, J9.9
unnamed: FB11.1, J1.6, J2.6, J7.6, J11.6
unnamed: FB12.1, J1.3, J2.3, J7.3, J11.3
unnamed: J8.1 (VBUS), U2.5 (VBUS)
unnamed: J8.2 (D-), U2.4 (IO2)
unnamed: J8.3 (D+), U2.6 (IO1)
unnamed: Q1.1 (G), R5.1
unnamed: Q1.3 (D), R9.2, U5.3 (EN)
unnamed: R7.2, R8.1, U4.3 (EN)
unnamed: R11.1, U4.5 (RT/CLK)
unnamed: R12.1, U5.5 (RT/CLK)
unnamed: R14.2, R15.1, U4.7 (VSENSE)
unnamed: R16.2, R17.1, U5.7 (VSENSE)
unnamed: R18.2, SW4.1
unnamed: R6.1, R23.1, U6.1 (D)
unnamed: R24.1, R25.1, U6.4 (R)
unnamed: R26.2, SW3.1
OctoSPI_P1_CLK: IC2.B2 (SCLK), U1.20 (PF10)
OctoSPI_P1_DQS: IC2.C3 (DQS), U1.95 (PG6)
OctoSPI_P1_IO0: IC2.D3 (SIO0), U1.43 (PB1)
OctoSPI_P1_IO1: IC2.D2 (SIO1), U1.42 (PB0)
OctoSPI_P1_IO2: IC2.C4 (SIO2), U1.40 (PA7)
OctoSPI_P1_IO3: IC2.D4 (SIO3), U1.39 (PA6)
OctoSPI_P1_IO4: IC2.D5 (SIO4), U1.25 (PC1)
OctoSPI_P1_IO5: IC2.E3 (SIO5), U1.26 (PC2)
OctoSPI_P1_IO6: IC2.E2 (SIO6), U1.27 (PC3)
OctoSPI_P1_IO7: IC2.E1 (SIO7), U1.41 (PC4)
OctoSPI_P1_NCS: IC2.C2 (CS#), U1.37 (PA4)
OctoSPI_P2_CLK: IC3.B2 (CK), U1.14 (PF4)
OctoSPI_P2_DQS: IC3.C3 (RWDS), U1.46 (PF12)
OctoSPI_P2_IO0: IC3.D3 (DQ0), U1.10 (PF0)
OctoSPI_P2_IO1: IC3.D2 (DQ1), U1.11 (PF1)
OctoSPI_P2_IO2: IC3.C4 (DQ2), U1.12 (PF2)
OctoSPI_P2_IO3: IC3.D4 (DQ3), U1.13 (PF3)
OctoSPI_P2_IO4: IC3.D5 (DQ4), U1.52 (PG0)
OctoSPI_P2_IO5: IC3.E3 (DQ5), U1.53 (PG1)
OctoSPI_P2_IO6: IC3.E2 (DQ6), U1.126 (PG9)
OctoSPI_P2_IO7: IC3.E1 (DQ7), U1.127 (PG10)
OctoSPI_P2_NCS: IC3.A3 (CS#), U1.129 (PG12)
PWR_Reset: R2.2, U4.6 (PWRGD)
RESET: C2.1, IC2.A4 (RESET#), IC3.A4 (RESET#), SW2.2, U1.23 (NRST)
SPI1_MISO: U1.92 (PG3), U7.2 (MISO)
SPI1_MOSI: U1.93 (PG4), U7.5 (MOSI)
SPI1_NSS: U1.94 (PG5), U7.1 (~CS)
SPI1_SCK: U1.91 (PG2), U7.6 (SCK)
Signal_LED: D1.2 (A), U1.7 (PC13)
TOUCH_INT: IC1.10 (nPENIRQ), J5.5, J6.2, J10.5, U1.100 (PC8)
TOUCH_RESET: J5.6, J6.4, J10.4, U1.101 (PC9)
USART1_RX: R24.2, U1.137 (PB7)
USART1_TX: R23.2, U1.136 (PB6)
USART2_CTS_NSS: U1.31 (PA0), U3.1 (RO)
USART2_RTS_DE: U1.32 (PA1), U3.2 (~RE)
USART2_RX: U1.34 (PA3), U3.4 (DI)
USART2_TX: U1.33 (PA2), U3.3 (DE)
USB_D+: U1.106 (PA12), U2.1 (IO1)
USB_D-: U1.105 (PA11), U2.3 (IO2)
USB_ID: J8.4 (ID), U1.104 (PA10)
USB_SOF: U1.102 (PA8)
X+: IC1.2 (X+), J6.10
X-: IC1.4 (X-), J6.6
Y+: IC1.3 (Y+), J6.8
Y-: IC1.5 (Y-), J6.12

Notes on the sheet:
Touchdisplay RGB TFT
Touchcontroller
Touchconfig
I2C ADR: 1001000

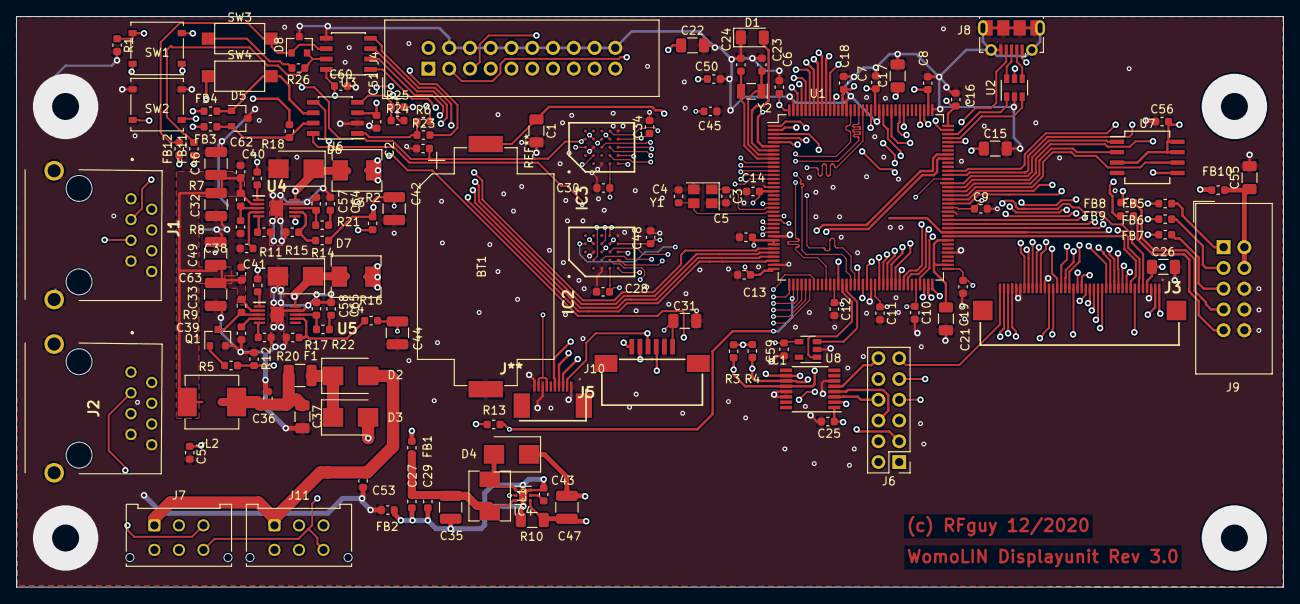
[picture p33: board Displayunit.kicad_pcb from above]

Board: 4 copper layers, 155.0 x 69.8 mm, 143 parts (0 on the bottom side), 156 nets.

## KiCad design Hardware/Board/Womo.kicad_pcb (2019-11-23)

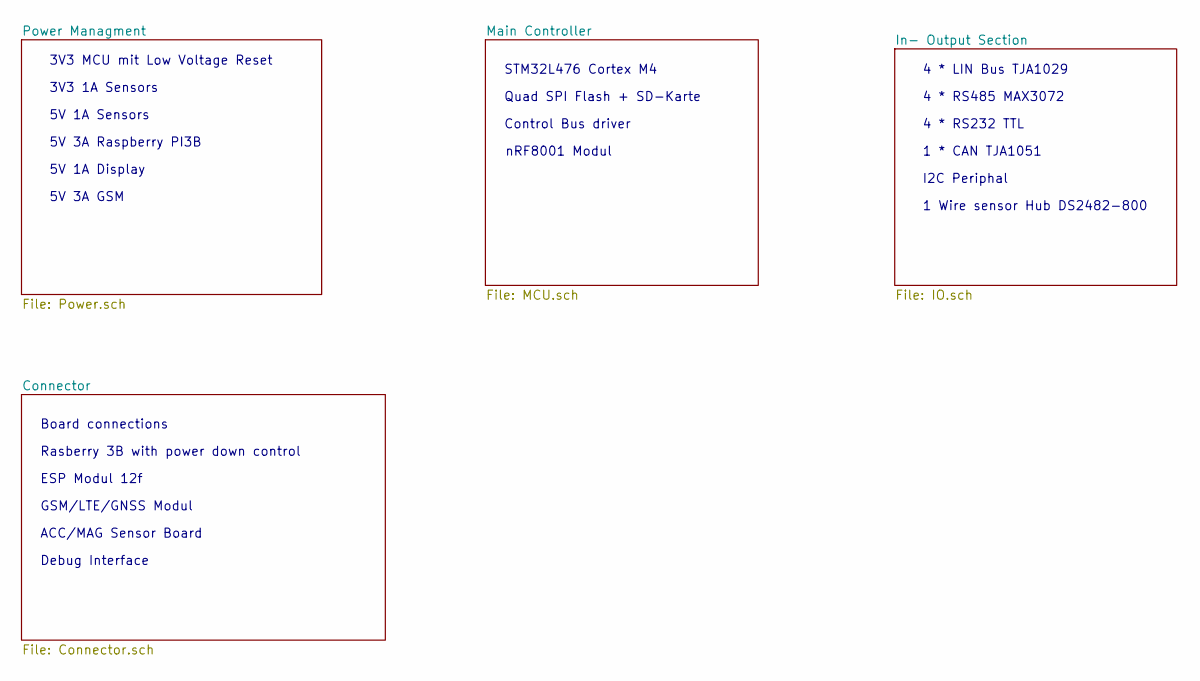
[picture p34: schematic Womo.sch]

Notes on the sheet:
3V3 MCU mit Low Voltage Reset
3V3 1A Sensors
5V 1A Sensors
5V 3A Raspberry PI3B
5V 1A Display
STM32L476 Cortex M4
Quad SPI Flash + SD-Karte
Control Bus driver
4 * LIN Bus TJA1029
4 * RS232 TTL
1 * CAN TJA1051
Rasberry 3B with power down control
Debug Interface
1 Wire sensor Hub DS2482-800
Board connections
nRF8001 Modul
5V 3A GSM
I2C Periphal
ESP Modul 12f
GSM/LTE/GNSS Modul
ACC/MAG Sensor Board
4 * RS485 MAX3072

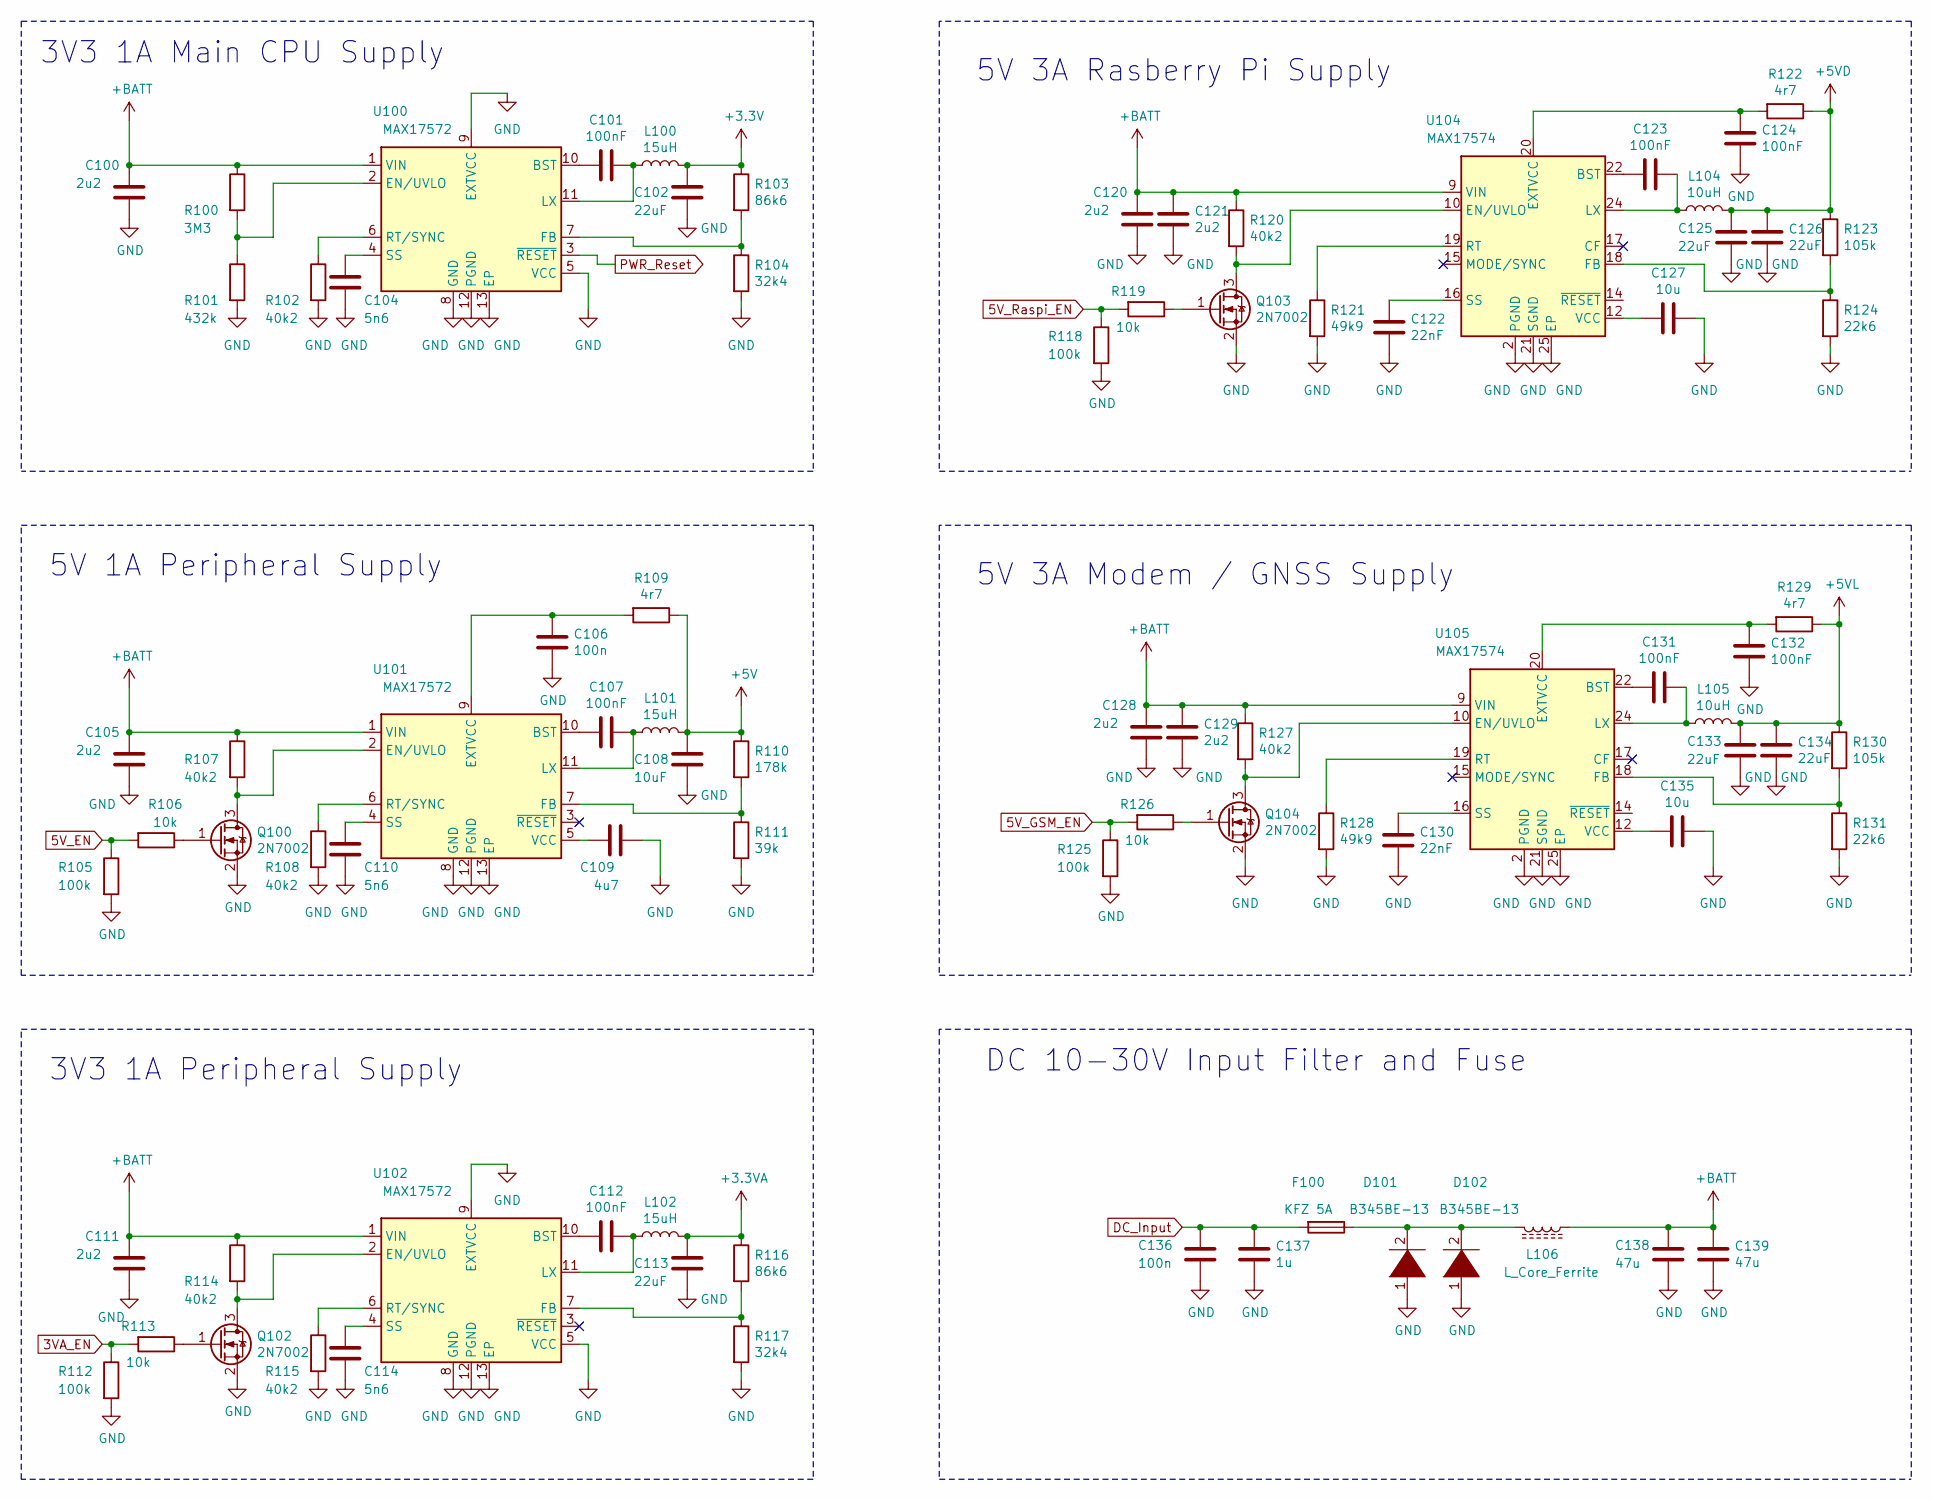
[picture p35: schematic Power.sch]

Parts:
C100, C105, C111, C120, C121, C128, C129: 2u2; C_1210_3225Metric
C101, C107, C112, C123, C124, C131, C132: 100nF; C_0603_1608Metric
C102, C113, C125, C126, C133, C134: 22uF; C_1210_3225Metric
C104, C110, C114: 5n6; C_0603_1608Metric
C106, C136: 100n; C_0603_1608Metric
C108: 10uF; C_1210_3225Metric
C109: 4u7; C_0603_1608Metric
C122, C130: 22nF; C_0603_1608Metric
C127, C135: 10u; C_1210_3225Metric
C137: 1u; C_0603_1608Metric
C138, C139: 47u; C_1210_3225Metric
D101, D102: B345BE-13; D_SMB
F100: KFZ 5A; Fuseholder_Blade_ATO_Littelfuse_Pudenz_2_Pin
L100, L101, L102: 15uH; L_Coilcraft_XxL4040
L104, L105: 10uH; XAL8080
L106: L_Core_Ferrite; L_Coilcraft_XxL4020
Q100, Q102, Q103, Q104: 2N7002; SOT-23
R100: 3M3; R_0603_1608Metric
R101: 432k; R_0603_1608Metric
R102, R107, R108, R114, R115, R120, R127: 40k2; R_0603_1608Metric
R103, R116: 86k6; R_0603_1608Metric
R104, R117: 32k4; R_0603_1608Metric
R105, R112, R118, R125: 100k; R_0603_1608Metric
R106, R113, R119, R126: 10k; R_0603_1608Metric
R109, R122, R129: 4r7; R_0603_1608Metric
R110: 178k; R_0603_1608Metric
R111: 39k; R_0603_1608Metric
R121, R128: 49k9; R_0603_1608Metric
R123, R130: 105k; R_0603_1608Metric
R124, R131: 22k6; R_0603_1608Metric
U100, U101, U102: MAX17572; DFN-12-1EP_3x3mm_P0.5mm_EP2.05x2.86mm
U104, U105: MAX17574; QFN-24-1EP_4x5mm_P0.5mm_EP2.65x3.65mm

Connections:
3VA_EN: R112.1, R113.2; also elsewhere on the board
5V_EN: R105.1, R106.2; also elsewhere on the board
5V_GSM_EN: R125.1, R126.2; also elsewhere on the board
5V_Raspi_EN: R118.1, R119.2; also elsewhere on the board
+3.3VA: C113.1, L102.2, R116.1; also elsewhere on the board
+3V3: C102.1, L100.2, R103.1; also elsewhere on the board
+5V: C108.1, L101.2, R109.1, R110.1; also elsewhere on the board
+5VD: C125.1, C126.1, L104.2, R122.1, R123.1; also elsewhere on the board
+5VL: C133.1, C134.1, L105.2, R129.1, R130.1; also elsewhere on the board
+BATT: C100.1, C105.1, C111.1, C120.1, C121.1, C128.1, C129.1, C138.1, C139.1, L106.1, R100.1, R107.1, R114.1, R120.1, R127.1, U100.1 (VIN), U101.1 (VIN), U102.1 (VIN), U104.5 (VIN), U104.6 (VIN), U104.7 (VIN), U104.9 (VIN), U105.5 (VIN), U105.6 (VIN), U105.7 (VIN), U105.9 (VIN); also elsewhere on the board
DC_Input: C136.1, C137.1, F100.2; also elsewhere on the board
GND: C100.2, C102.2, C104.2, C105.2, C106.2, C108.2, C109.1, C110.2, C111.2, C113.2, C114.2, C120.2, C121.2, C122.2, C124.2, C125.2, C126.2, C127.1, C128.2, C129.2, C130.2, C132.2, C133.2, C134.2, C135.1, C136.2, C137.2, C138.2, C139.2, D101.1 (K), D102.1 (K), Q100.2 (S), Q102.2 (S), Q103.2 (S), Q104.2 (S), R101.2, R102.2, R104.2, R105.2, R108.2, R111.2, R112.2, R115.2, R117.2, R118.2, R121.2, R124.2, R125.2, R128.2, R131.2, U100.5 (VCC), U100.8 (GND), U100.9 (EXTVCC), U100.12 (PGND), U100.13 (EP), U101.8 (GND), U101.12 (PGND), U101.13 (EP), U102.5 (VCC), U102.8 (GND), U102.9 (EXTVCC), U102.12 (PGND), U102.13 (EP), U104.2 (PGND), U104.3 (PGND), U104.11 (PGND), U104.21 (SGND), U104.25 (EP), U105.2 (PGND), U105.3 (PGND), U105.11 (PGND), U105.21 (SGND), U105.25 (EP); also elsewhere on the board
unnamed: C101.1, L100.1, U100.11 (LX)
unnamed: C101.2, U100.10 (BST)
unnamed: C104.1, U100.4 (SS)
unnamed: C106.1, R109.2, U101.9 (EXTVCC)
unnamed: C107.1, L101.1, U101.11 (LX)
unnamed: C107.2, U101.10 (BST)
unnamed: C109.2, U101.5 (VCC)
unnamed: C110.1, U101.4 (SS)
unnamed: C112.1, L102.1, U102.11 (LX)
unnamed: C112.2, U102.10 (BST)
unnamed: C114.1, U102.4 (SS)
unnamed: C122.1, U104.16 (SS)
unnamed: C123.1, L104.1, U104.1 (LX), U104.23 (LX), U104.24 (LX)
unnamed: C123.2, U104.22 (BST)
unnamed: C124.1, R122.2, U104.20 (EXTVCC)
unnamed: C127.2, U104.12 (VCC)
unnamed: C130.1, U105.16 (SS)
unnamed: C131.1, L105.1, U105.1 (LX), U105.23 (LX), U105.24 (LX)
unnamed: C131.2, U105.22 (BST)
unnamed: C132.1, R129.2, U105.20 (EXTVCC)
unnamed: C135.2, U105.12 (VCC)
unnamed: D101.2 (A), D102.2 (A), F100.1, L106.2
unnamed: Q100.1 (G), R106.1
unnamed: Q100.3 (D), R107.2, U101.2 (EN/UVLO)
unnamed: Q102.1 (G), R113.1
unnamed: Q102.3 (D), R114.2, U102.2 (EN/UVLO)
unnamed: Q103.1 (G), R119.1
unnamed: Q103.3 (D), R120.2, U104.10 (EN/UVLO)
unnamed: Q104.1 (G), R126.1
unnamed: Q104.3 (D), R127.2, U105.10 (EN/UVLO)
unnamed: R100.2, R101.1, U100.2 (EN/UVLO)
unnamed: R102.1, U100.6 (RT/SYNC)
unnamed: R103.2, R104.1, U100.7 (FB)
unnamed: R108.1, U101.6 (RT/SYNC)
unnamed: R110.2, R111.1, U101.7 (FB)
unnamed: R115.1, U102.6 (RT/SYNC)
unnamed: R116.2, R117.1, U102.7 (FB)
unnamed: R121.1, U104.19 (RT)
unnamed: R123.2, R124.1, U104.18 (FB)
unnamed: R128.1, U105.19 (RT)
unnamed: R130.2, R131.1, U105.18 (FB)
PWR_Reset: U100.3 (~RESET); also elsewhere on the board

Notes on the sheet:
3V3 1A Main CPU Supply
5V 1A Peripheral Supply
3V3 1A Peripheral Supply
5V 3A Rasberry Pi Supply
5V 3A Modem / GNSS Supply
DC 10-30V Input Filter and Fuse

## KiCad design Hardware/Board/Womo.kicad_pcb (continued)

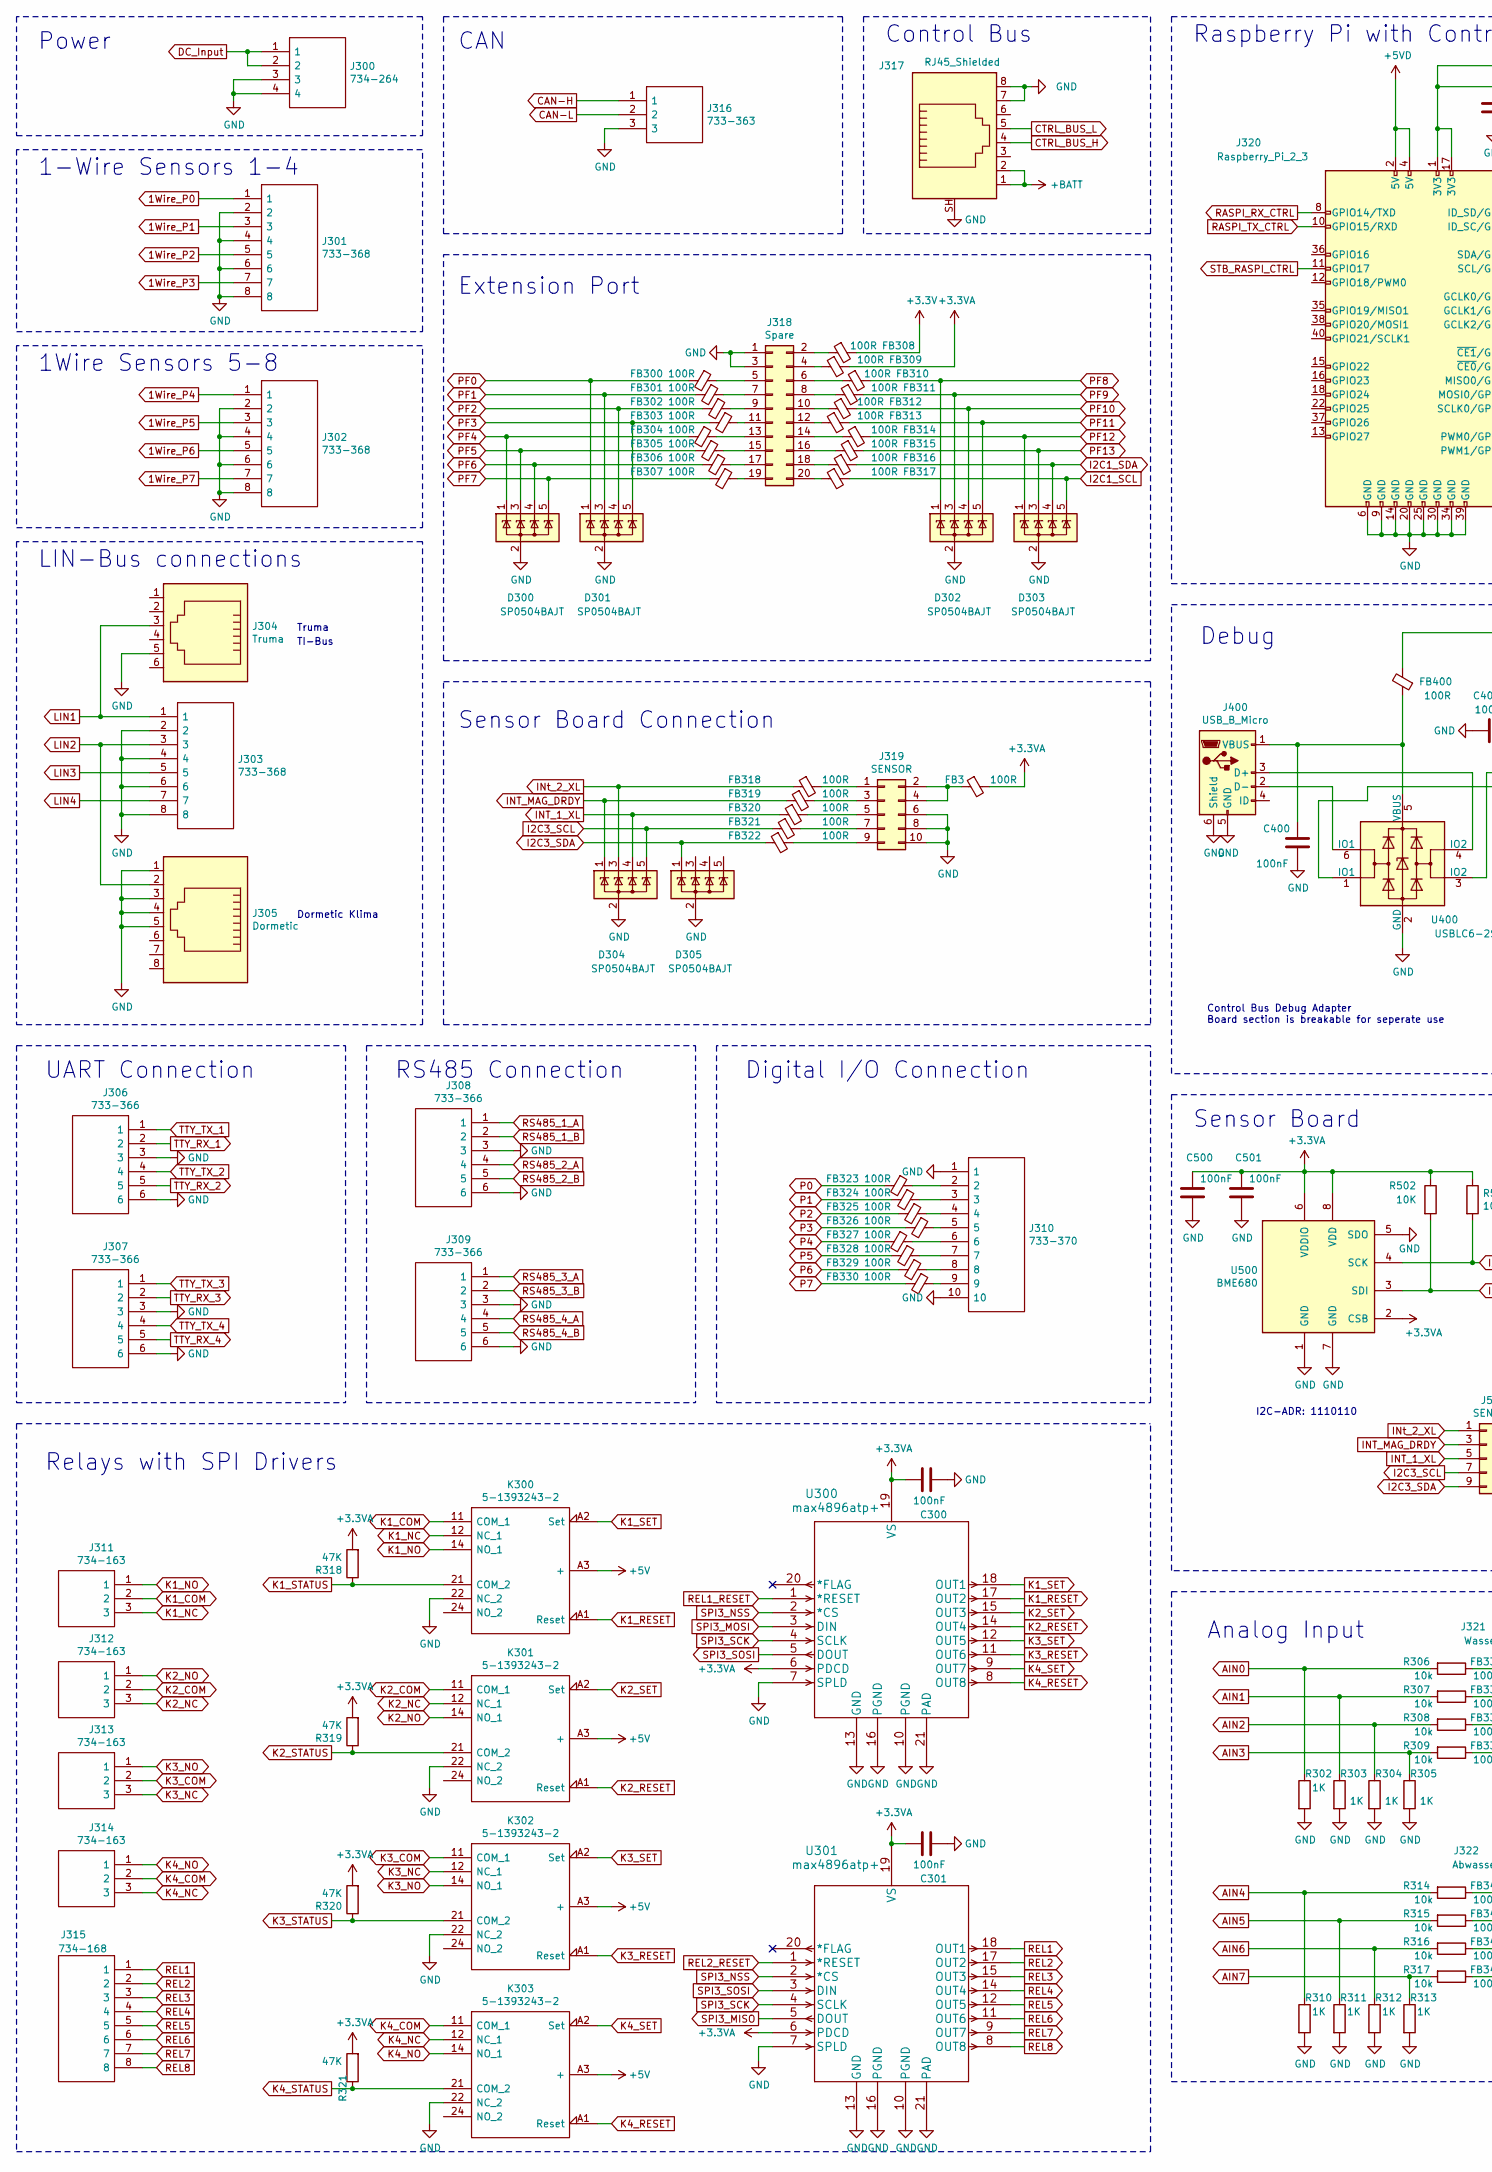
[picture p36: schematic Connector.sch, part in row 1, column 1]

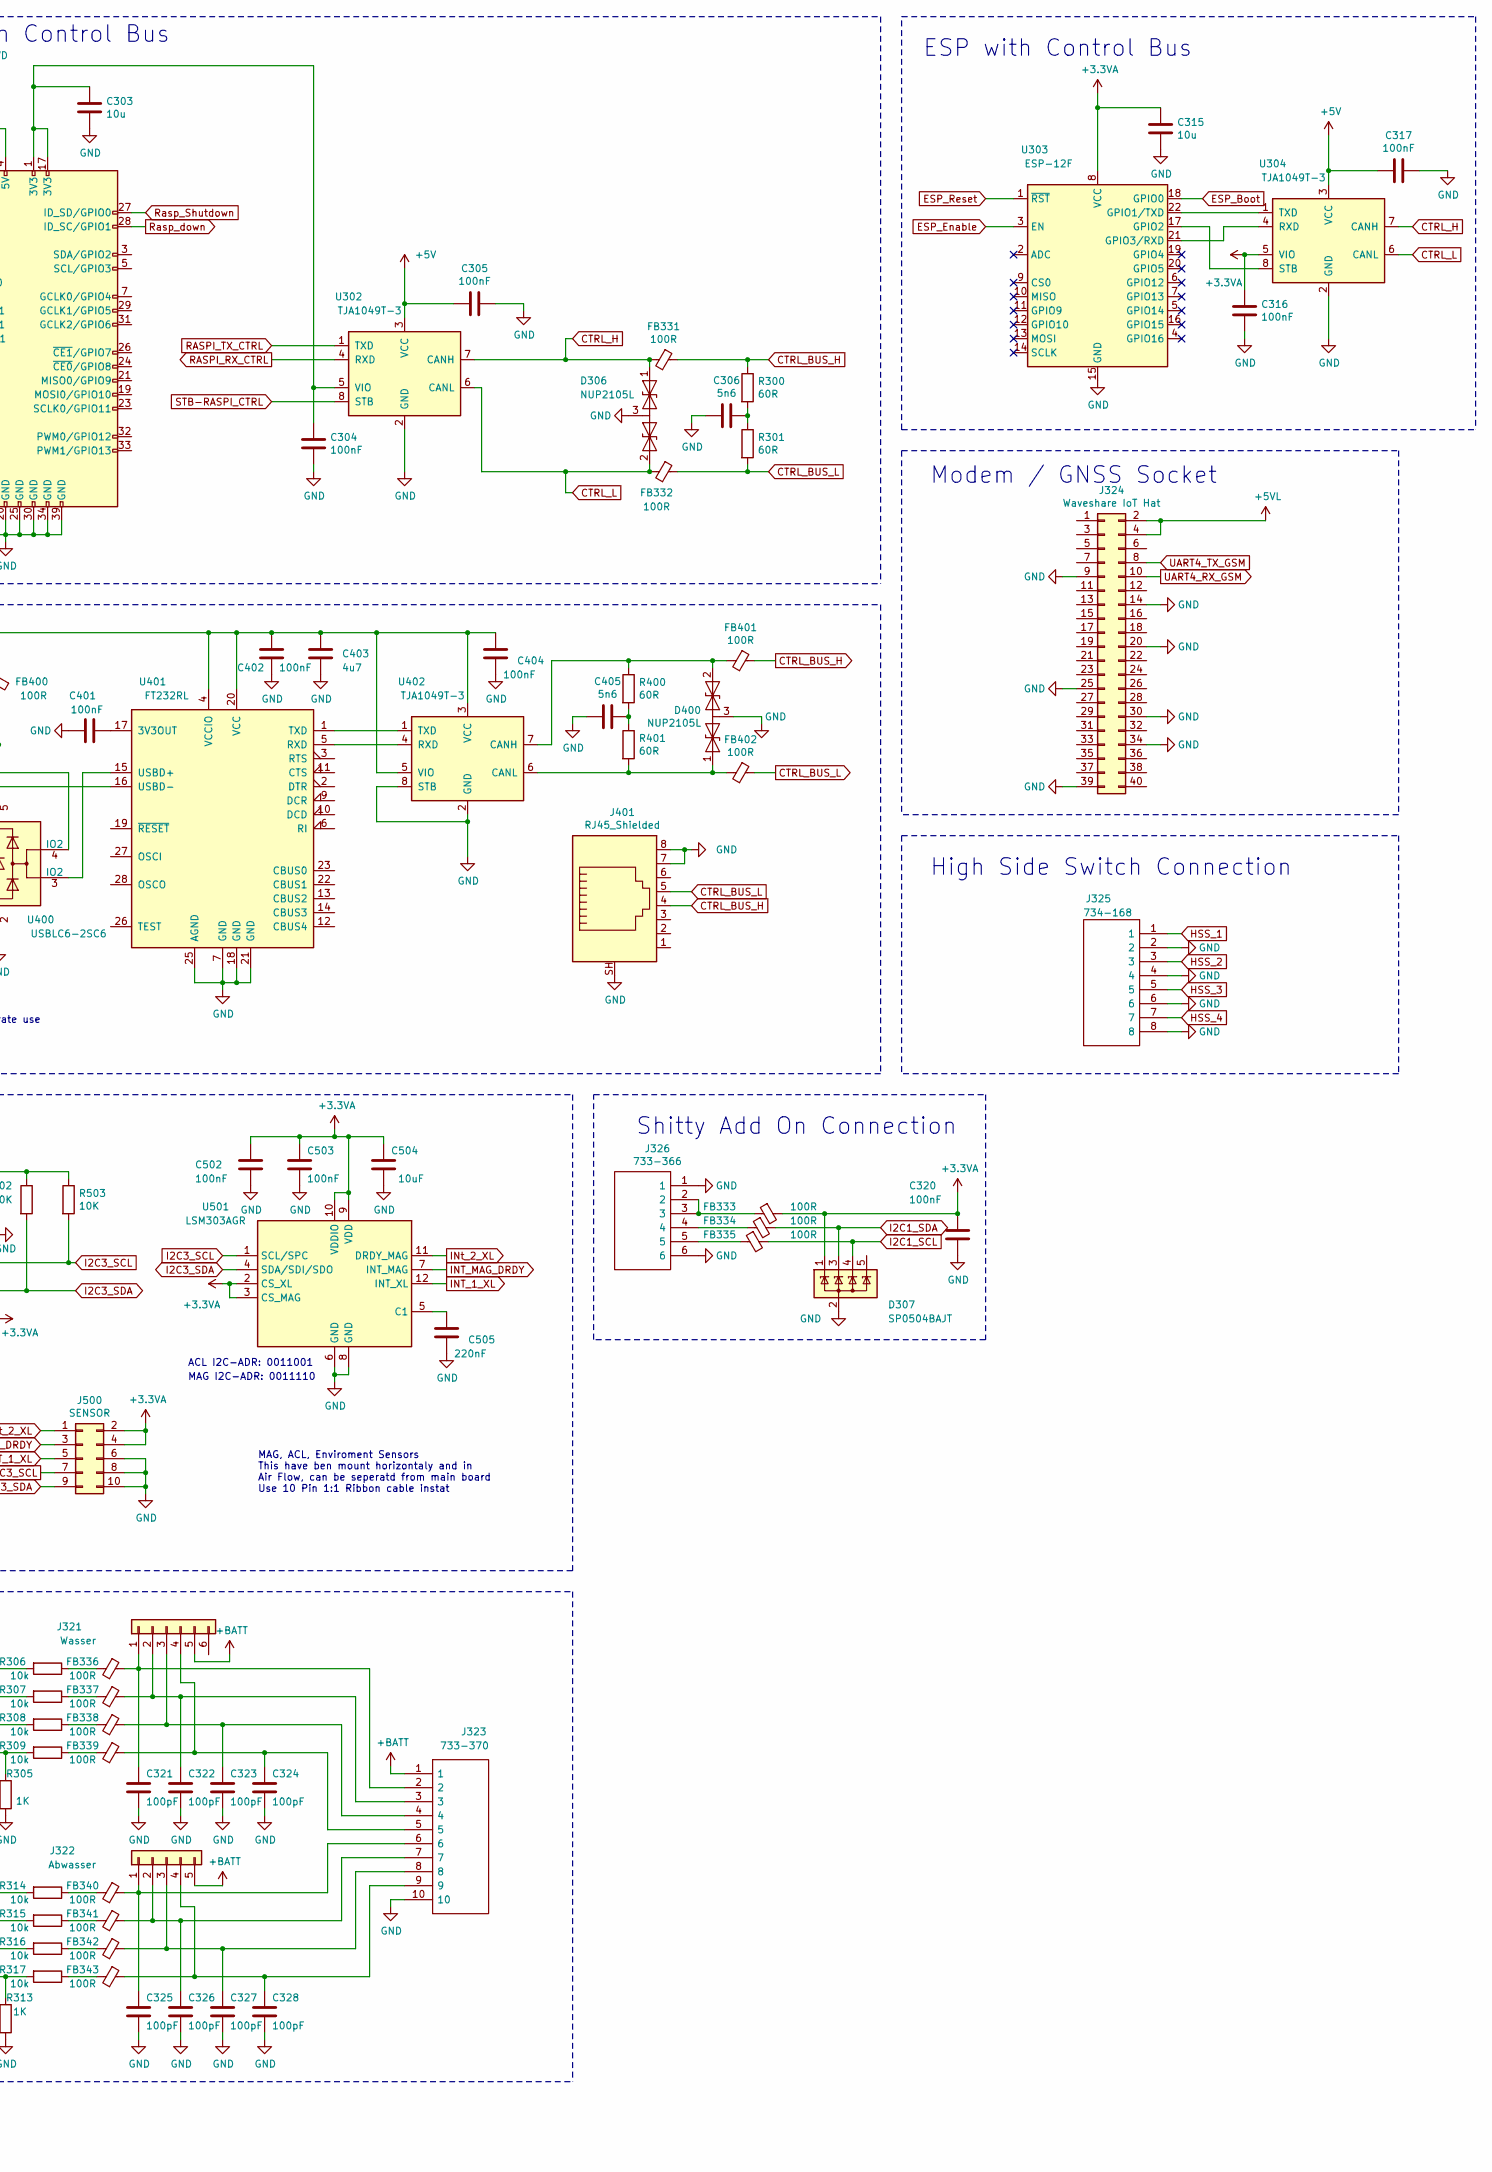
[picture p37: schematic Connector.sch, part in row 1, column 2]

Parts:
C300, C301, C304, C305, C316, C317, C320, C400, C401, C402, C404, C500, C501, C502, C503: 100nF; C_0603_1608Metric
C303, C315: 10u; C_1210_3225Metric
C306, C405: 5n6; C_0603_1608Metric
C321, C322, C323, C324, C325, C326, C327, C328: 100pF; C_0603_1608Metric
C403: 4u7; C_0603_1608Metric
C504: 10uF; C_0603_1608Metric
C505: 220nF; C_0603_1608Metric
D300, D301, D302, D303, D304, D305, D307: SP0504BAJT; SOT-353_SC-70-5
D306, D400: NUP2105L; SOT-23
FB3, FB300, FB301, FB302, FB303, FB304, FB305, FB306, FB307, FB308, FB309, FB310, FB311, FB312, FB313, FB314, FB315, FB316, FB317, FB318, FB319, FB320, FB321, FB322, FB323, FB324, FB325, FB326, FB327, FB328, FB329, FB330, FB331, FB332, FB333, FB334, FB335, FB336, FB337, FB338, FB339, FB340, FB341, FB342, FB343, FB400, FB401, FB402: 100R; L_0603_1608Metric
J300: 734-264; SHDR4W120P0X381_1X4_1640X1030X850P; Manufacturer_Part_Number 734-264
J301, J302, J303: 733-368; SHDR8W80P0X250_1X8_2250X890X780P; Manufacturer_Part_Number 733-368
J304: Truma; RJ12_Amphenol_54601
J305: Dormetic; RJ45_Amphenol_54602-x08_Horizontal
J306, J307, J308, J309, J326: 733-366; SHDR6W80P0X250_1X6_1750X890X780P; Manufacturer_Part_Number 733-366
J310, J323: 733-370; SHDR10W80P0X250_1X10_2750X890X780P; Manufacturer_Part_Number 733-370
J311, J312, J313, J314: 734-163; SHDR3W100P0X350_1X3_1290X1030X850P; Manufacturer_Part_Number 734-163
J315, J325: 734-168; SHDR8W150P350X350_1X8_3040X1030X860P; Manufacturer_Part_Number 734-168
J316: 733-363; SHDR3W80P0X250_1X3_1000X890X780P; Manufacturer_Part_Number 733-363
J317, J401: RJ45_Shielded; RJ45_Amphenol_RJHSE5380
J318: Spare; PinHeader_2x10_P2.54mm_Vertical
J319, J500: SENSOR; IDC-Header_2x05_P2.54mm_Vertical
J320: Raspberry_Pi_2_3; PinSocket_2x20_P2.54mm_Vertical
J321: Wasser; 436500628
J322: Abwasser; 436500527
J324: Waveshare IoT Hat; IDC-Header_2x20_P2.54mm_Vertical
J400: USB_B_Micro; USB_Micro-B_Molex-105017-0001
K300, K301, K302, K303: 5-1393243-2; 513932432; Manufacturer_Part_Number 5-1393243-2; Mouser Part Number 655-5-1393243-2
R300, R301, R400, R401: 60R; R_0603_1608Metric
R302, R303, R304, R305, R310, R311, R312, R313: 1K; R_0603_1608Metric
R306, R307, R308, R309, R314, R315, R316, R317: 10k; R_0603_1608Metric
R318, R319, R320, R321: 47K; R_0603_1608Metric
R502, R503: 10K; R_0603_1608Metric
U300, U301: max4896atp+; max4896atp&plus_
U302, U304, U402: TJA1049T-3; SOIC-8_3.9x4.9mm_P1.27mm
U303: ESP-12F; ESP-12E
U400: USBLC6-2SC6; SOT-23-6
U401: FT232RL; SSOP-28_5.3x10.2mm_P0.65mm
U500: BME680; Bosch_LGA-8_3x3mm_P0.8mm_ClockwisePinNumbering
U501: LSM303AGR; LGA-12_2x2mm_P0.5mm

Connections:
1Wire_P0: J301.1; also elsewhere on the board
1Wire_P1: J301.3; also elsewhere on the board
1Wire_P2: J301.5; also elsewhere on the board
1Wire_P3: J301.7; also elsewhere on the board
1Wire_P4: J302.1; also elsewhere on the board
1Wire_P5: J302.3; also elsewhere on the board
1Wire_P6: J302.5; also elsewhere on the board
1Wire_P7: J302.7; also elsewhere on the board
+3.3VA: C300.2, C301.2, C315.1, C316.1, C320.1, C500.1, C501.1, C502.1, C503.1, C504.1, D307.1 (K), FB3.2, FB309.2, FB333.2, J500.2, J500.4, R318.2, R319.2, R320.2, R321.2, R502.1, R503.1, U300.6 (PDCD), U300.19 (VS), U301.6 (PDCD), U301.19 (VS), U303.8 (VCC), U304.5 (VIO), U500.2 (CSB), U500.6 (VDDIO), U500.8 (VDD), U501.2 (CS_XL), U501.3 (CS_MAG), U501.9 (VDD), U501.10 (VDDIO); also elsewhere on the board
+3V3: FB308.2; also elsewhere on the board
+5V: C305.2, C317.2, K300.A3 (+), K301.A3 (+), K302.A3 (+), K303.A3 (+), U302.3 (VCC), U304.3 (VCC); also elsewhere on the board
+5VD: J320.2 (5V), J320.4 (5V); also elsewhere on the board
+5VL: J324.2, J324.4; also elsewhere on the board
+BATT: J317.1, J317.2, J321.5, J322.5, J323.1; also elsewhere on the board
AIN0: R302.1, R306.2; also elsewhere on the board
AIN1: R303.1, R307.2; also elsewhere on the board
AIN2: R304.1, R308.2; also elsewhere on the board
AIN3: R305.1, R309.2; also elsewhere on the board
AIN4: R310.1, R314.2; also elsewhere on the board
AIN5: R311.1, R315.2; also elsewhere on the board
AIN6: R312.1, R316.2; also elsewhere on the board
AIN7: R313.1, R317.2; also elsewhere on the board
CAN-H: J316.1; also elsewhere on the board
CAN-L: J316.2; also elsewhere on the board
CTRL_BUS_H: FB331.1, FB401.1, J317.4, J401.4, R300.1
CTRL_BUS_L: FB332.1, FB402.1, J317.5, J401.5, R301.2
CTRL_H: D306.1 (A1), FB331.2, U302.7 (CANH), U304.7 (CANH); also elsewhere on the board
CTRL_L: D306.2 (A2), FB332.2, U302.6 (CANL), U304.6 (CANL); also elsewhere on the board
DC_Input: J300.1, J300.2; also elsewhere on the board
ESP_Boot: U303.18 (GPIO0); also elsewhere on the board
ESP_Enable: U303.3 (EN); also elsewhere on the board
ESP_Reset: U303.1 (~RST); also elsewhere on the board
GND: C300.1, C301.1, C303.2, C304.2, C305.1, C306.2, C315.2, C316.2, C317.1, C320.2, C321.2, C322.2, C323.2, C324.2, C325.2, C326.2, C327.2, C328.2, C400.2, C401.1, C402.2, C403.2, C404.2, C405.2, C500.2, C501.2, C502.2, C503.2, C504.2, C505.2, D300.2 (A), D301.2 (A), D302.2 (A), D303.2 (A), D304.2 (A), D305.2 (A), D306.3 (common), D307.2 (A), D400.3 (common), J300.3, J300.4, J301.2, J301.4, J301.6, J301.8, J302.2, J302.4, J302.6, J302.8, J303.2, J303.4, J303.6, J303.8, J304.5, J305.1, J305.3, J305.4, J305.5, J306.3, J306.6, J307.3, J307.6, J308.3, J308.6, J309.3, J309.6, J310.1, J310.10, J316.3, J317.7, J317.8, J317.SH, J318.1, J318.3, J319.6, J319.8, J319.10, J320.6 (GND), J320.9 (GND), J320.14 (GND), J320.20 (GND), J320.25 (GND), J320.30 (GND), J320.34 (GND), J320.39 (GND), J323.10, J324.9, J324.14, J324.20, J324.25, J324.30, J324.34, J324.39, J325.2, J325.4, J325.6, J325.8, J326.1, J326.6, J400.5 (GND), J400.6 (Shield), J401.7, J401.8, J401.SH, J500.6, J500.8, J500.10, K300.22 (NC_2), K301.22 (NC_2), K302.22 (NC_2), K303.22 (NC_2), R302.2, R303.2, R304.2, R305.2, R310.2, R311.2, R312.2, R313.2, U300.7 (SPLD), U300.10 (PGND), U300.13 (GND), U300.16 (PGND), U300.21 (PAD), U301.7 (SPLD), U301.10 (PGND), U301.13 (GND), U301.16 (PGND), U301.21 (PAD), U302.2 (GND), U303.15 (GND), U304.2 (GND), U400.2 (GND), U401.7 (GND), U401.18 (GND), U401.21 (GND), U401.25 (AGND), U402.2 (GND), U402.8 (STB), U500.1 (GND), U500.5 (SDO), U500.7 (GND), U501.6 (GND), U501.8 (GND); also elsewhere on the board
HSS_1: J325.1; also elsewhere on the board
HSS_2: J325.3; also elsewhere on the board
HSS_3: J325.5; also elsewhere on the board
HSS_4: J325.7; also elsewhere on the board
I2C1_SCL: D303.5 (K), D307.4 (K), FB317.2, FB335.2; also elsewhere on the board
I2C1_SDA: D303.4 (K), D307.3 (K), FB316.2, FB334.2; also elsewhere on the board
I2C3_SCL: D304.5 (K), FB321.1, J500.7, R503.2, U500.4 (SCK), U501.1 (SCL/SPC); also elsewhere on the board
I2C3_SDA: D305.1 (K), FB322.1, J500.9, R502.2, U500.3 (SDI), U501.4 (SDA/SDI/SDO); also elsewhere on the board
INT_1_XL: D304.4 (K), FB320.1, J500.5, U501.12 (INT_XL); also elsewhere on the board
INT_MAG_DRDY: D304.1 (K), FB319.1, J500.3, U501.7 (INT_MAG); also elsewhere on the board
INt_2_XL: D304.3 (K), FB318.1, J500.1, U501.11 (DRDY_MAG); also elsewhere on the board
K1_COM: J311.2, K300.11 (COM_1)
K1_NC: J311.3, K300.12 (NC_1)
K1_NO: J311.1, K300.14 (NO_1)
K1_RESET: K300.A1 (Reset), U300.17 (OUT2)
K1_SET: K300.A2 (Set), U300.18 (OUT1)
K1_STATUS: K300.21 (COM_2), R318.1; also elsewhere on the board
K2_COM: J312.2, K301.11 (COM_1)
K2_NC: J312.3, K301.12 (NC_1)
K2_NO: J312.1, K301.14 (NO_1)
K2_RESET: K301.A1 (Reset), U300.14 (OUT4)
K2_SET: K301.A2 (Set), U300.15 (OUT3)
K2_STATUS: K301.21 (COM_2), R319.1; also elsewhere on the board
K3_COM: J313.2, K302.11 (COM_1)
K3_NC: J313.3, K302.12 (NC_1)
K3_NO: J313.1, K302.14 (NO_1)
K3_RESET: K302.A1 (Reset), U300.11 (OUT6)
K3_SET: K302.A2 (Set), U300.12 (OUT5)
K3_STATUS: K302.21 (COM_2), R320.1; also elsewhere on the board
K4_COM: J314.2, K303.11 (COM_1)
K4_NC: J314.3, K303.12 (NC_1)
K4_NO: J314.1, K303.14 (NO_1)
K4_RESET: K303.A1 (Reset), U300.8 (OUT8)
K4_SET: K303.A2 (Set), U300.9 (OUT7)
K4_STATUS: K303.21 (COM_2), R321.1; also elsewhere on the board
LIN1: J303.1, J304.3; also elsewhere on the board
LIN2: J303.3, J305.2; also elsewhere on the board
LIN3: J303.5; also elsewhere on the board
LIN4: J303.7; also elsewhere on the board
unnamed: C303.1, C304.1, J320.1 (3V3), J320.17 (3V3), U302.5 (VIO)
unnamed: C306.1, R300.2, R301.1
unnamed: C321.1, FB336.1, J321.1, J323.2
unnamed: C322.1, FB337.1, J321.2, J323.3
unnamed: C323.1, FB338.1, J321.3, J323.4
unnamed: C324.1, FB339.1, J321.4, J323.5
unnamed: C325.1, FB340.1, J322.1, J323.6
unnamed: C326.1, FB341.1, J322.2, J323.7
unnamed: C327.1, FB342.1, J322.3, J323.8
unnamed: C328.1, FB343.1, J322.4, J323.9
unnamed: C400.1, FB400.1, J400.1 (VBUS), U400.5 (VBUS)
unnamed: C401.2, U401.17 (3V3OUT)
unnamed: C402.1, C403.1, C404.1, FB400.2, U401.4 (VCCIO), U401.20 (VCC), U402.3 (VCC), U402.5 (VIO)
unnamed: C405.1, R400.2, R401.1
unnamed: C505.1, U501.5 (C1)
unnamed: D400.1 (A1), FB402.2, R401.2, U402.6 (CANL)
unnamed: D400.2 (A2), FB401.2, R400.1, U402.7 (CANH)
unnamed: FB3.1, J319.2, J319.4
unnamed: FB300.1, J318.5
unnamed: FB301.1, J318.7
unnamed: FB302.1, J318.9
unnamed: FB303.1, J318.11
unnamed: FB304.1, J318.13
unnamed: FB305.1, J318.15
unnamed: FB306.1, J318.17
unnamed: FB307.1, J318.19
unnamed: FB308.1, J318.2
unnamed: FB309.1, J318.4
unnamed: FB310.1, J318.6
unnamed: FB311.1, J318.8
unnamed: FB312.1, J318.10
unnamed: FB313.1, J318.12
unnamed: FB314.1, J318.14
unnamed: FB315.1, J318.16
unnamed: FB316.1, J318.18
unnamed: FB317.1, J318.20
unnamed: FB318.2, J319.1
unnamed: FB319.2, J319.3
unnamed: FB320.2, J319.5
unnamed: FB321.2, J319.7
unnamed: FB322.2, J319.9
unnamed: FB323.1, J310.2
unnamed: FB324.1, J310.3
unnamed: FB325.1, J310.4
unnamed: FB326.1, J310.5
unnamed: FB327.1, J310.6
unnamed: FB328.1, J310.7
unnamed: FB329.1, J310.8
unnamed: FB330.1, J310.9
unnamed: FB333.1, J326.2, J326.3
unnamed: FB334.1, J326.4
unnamed: FB335.1, J326.5
unnamed: FB336.2, R306.1
unnamed: FB337.2, R307.1
unnamed: FB338.2, R308.1
unnamed: FB339.2, R309.1
unnamed: FB340.2, R314.1
unnamed: FB341.2, R315.1
unnamed: FB342.2, R316.1
unnamed: FB343.2, R317.1
unnamed: J400.2 (D-), U400.6 (IO1)
unnamed: J400.3 (D+), U400.4 (IO2)
unnamed: U303.17 (GPIO2), U304.8 (STB)
unnamed: U303.21 (GPIO3/RXD), U304.4 (RXD)
unnamed: U303.22 (GPIO1/TXD), U304.1 (TXD)
unnamed: U400.1 (IO1), U401.16 (USBD-)
unnamed: U400.3 (IO2), U401.15 (USBD+)
unnamed: U401.1 (TXD), U402.1 (TXD)
unnamed: U401.5 (RXD), U402.4 (RXD)
P0: FB323.2; also elsewhere on the board
P1: FB324.2; also elsewhere on the board
P2: FB325.2; also elsewhere on the board
P3: FB326.2; also elsewhere on the board
P4: FB327.2; also elsewhere on the board
P5: FB328.2; also elsewhere on the board
P6: FB329.2; also elsewhere on the board
P7: FB330.2; also elsewhere on the board
PF0: D301.1 (K), FB300.2; also elsewhere on the board
PF1: D301.3 (K), FB301.2; also elsewhere on the board
PF2: D301.4 (K), FB302.2; also elsewhere on the board
PF3: D301.5 (K), FB303.2; also elsewhere on the board
PF4: D300.1 (K), FB304.2; also elsewhere on the board
PF5: D300.3 (K), FB305.2; also elsewhere on the board
PF6: D300.4 (K), FB306.2; also elsewhere on the board
PF7: D300.5 (K), FB307.2; also elsewhere on the board
PF8: D302.1 (K), FB310.2; also elsewhere on the board
PF9: D302.3 (K), FB311.2; also elsewhere on the board
PF10: D302.4 (K), FB312.2; also elsewhere on the board
PF11: D302.5 (K), FB313.2; also elsewhere on the board
PF12: D303.1 (K), FB314.2; also elsewhere on the board
PF13: D303.3 (K), FB315.2; also elsewhere on the board
RASPI_RX_CTRL: J320.8 (GPIO14/TXD), U302.4 (RXD)
RASPI_TX_CTRL: J320.10 (GPIO15/RXD), U302.1 (TXD)
REL1: J315.1, U301.18 (OUT1)
REL1_RESET: U300.1 (*RESET); also elsewhere on the board
REL2: J315.2, U301.17 (OUT2)
REL2_RESET: U301.1 (*RESET); also elsewhere on the board
REL3: J315.3, U301.15 (OUT3)
REL4: J315.4, U301.14 (OUT4)
REL5: J315.5, U301.12 (OUT5)
REL6: J315.6, U301.11 (OUT6)
REL7: J315.7, U301.9 (OUT7)
REL8: J315.8, U301.8 (OUT8)
RS485_1_A: J308.1; also elsewhere on the board
RS485_1_B: J308.2; also elsewhere on the board
RS485_2_A: J308.4; also elsewhere on the board
RS485_2_B: J308.5; also elsewhere on the board
RS485_3_A: J309.1; also elsewhere on the board
RS485_3_B: J309.2; also elsewhere on the board
RS485_4_A: J309.4; also elsewhere on the board
RS485_4_B: J309.5; also elsewhere on the board
Rasp_Shutdown: J320.27 (ID_SD/GPIO0); also elsewhere on the board
Rasp_down: J320.28 (ID_SC/GPIO1); also elsewhere on the board
SPI3_MISO: U301.5 (DOUT); also elsewhere on the board
SPI3_MOSI: U300.3 (DIN); also elsewhere on the board
SPI3_NSS: U300.2 (*CS), U301.2 (*CS); also elsewhere on the board
SPI3_SCK: U300.4 (SCLK), U301.4 (SCLK); also elsewhere on the board
SPI3_SOSI: U300.5 (DOUT), U301.3 (DIN)
STB-RASPI_CTRL: U302.8 (STB)
STB_RASPI_CTRL: J320.11 (GPIO17)
TTY_RX_1: J306.2; also elsewhere on the board
TTY_RX_2: J306.5; also elsewhere on the board
TTY_RX_3: J307.2; also elsewhere on the board
TTY_RX_4: J307.5; also elsewhere on the board
TTY_TX_1: J306.1; also elsewhere on the board
TTY_TX_2: J306.4; also elsewhere on the board
TTY_TX_3: J307.1; also elsewhere on the board
TTY_TX_4: J307.4; also elsewhere on the board
UART4_RX_GSM: J324.10; also elsewhere on the board
UART4_TX_GSM: J324.8; also elsewhere on the board

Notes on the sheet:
Truma
TI-Bus
Dormetic Klima
Power
1-Wire Sensors 1-4
1Wire Sensors 5-8
LIN-Bus connections
CAN
Control Bus Debug Adapter Board section is breakable for seperate use
I2C-ADR: 1110110
ACL I2C-ADR: 0011001
MAG I2C-ADR: 0011110
MAG, ACL, Enviroment Sensors This have ben mount horizontaly and in Air Flow, can be seperatd from main board Use 10 Pin 1:1 Ribbon cable instat
Relays with SPI Drivers
Analog Input
Debug
Sensor Board
Raspberry Pi with Control Bus
Modem / GNSS Socket
Sensor Board Connection
ESP with Control Bus
Control Bus
UART Connection
RS485 Connection
Digital I/O Connection
Extension Port
High Side Switch Connection
Shitty Add On Connection

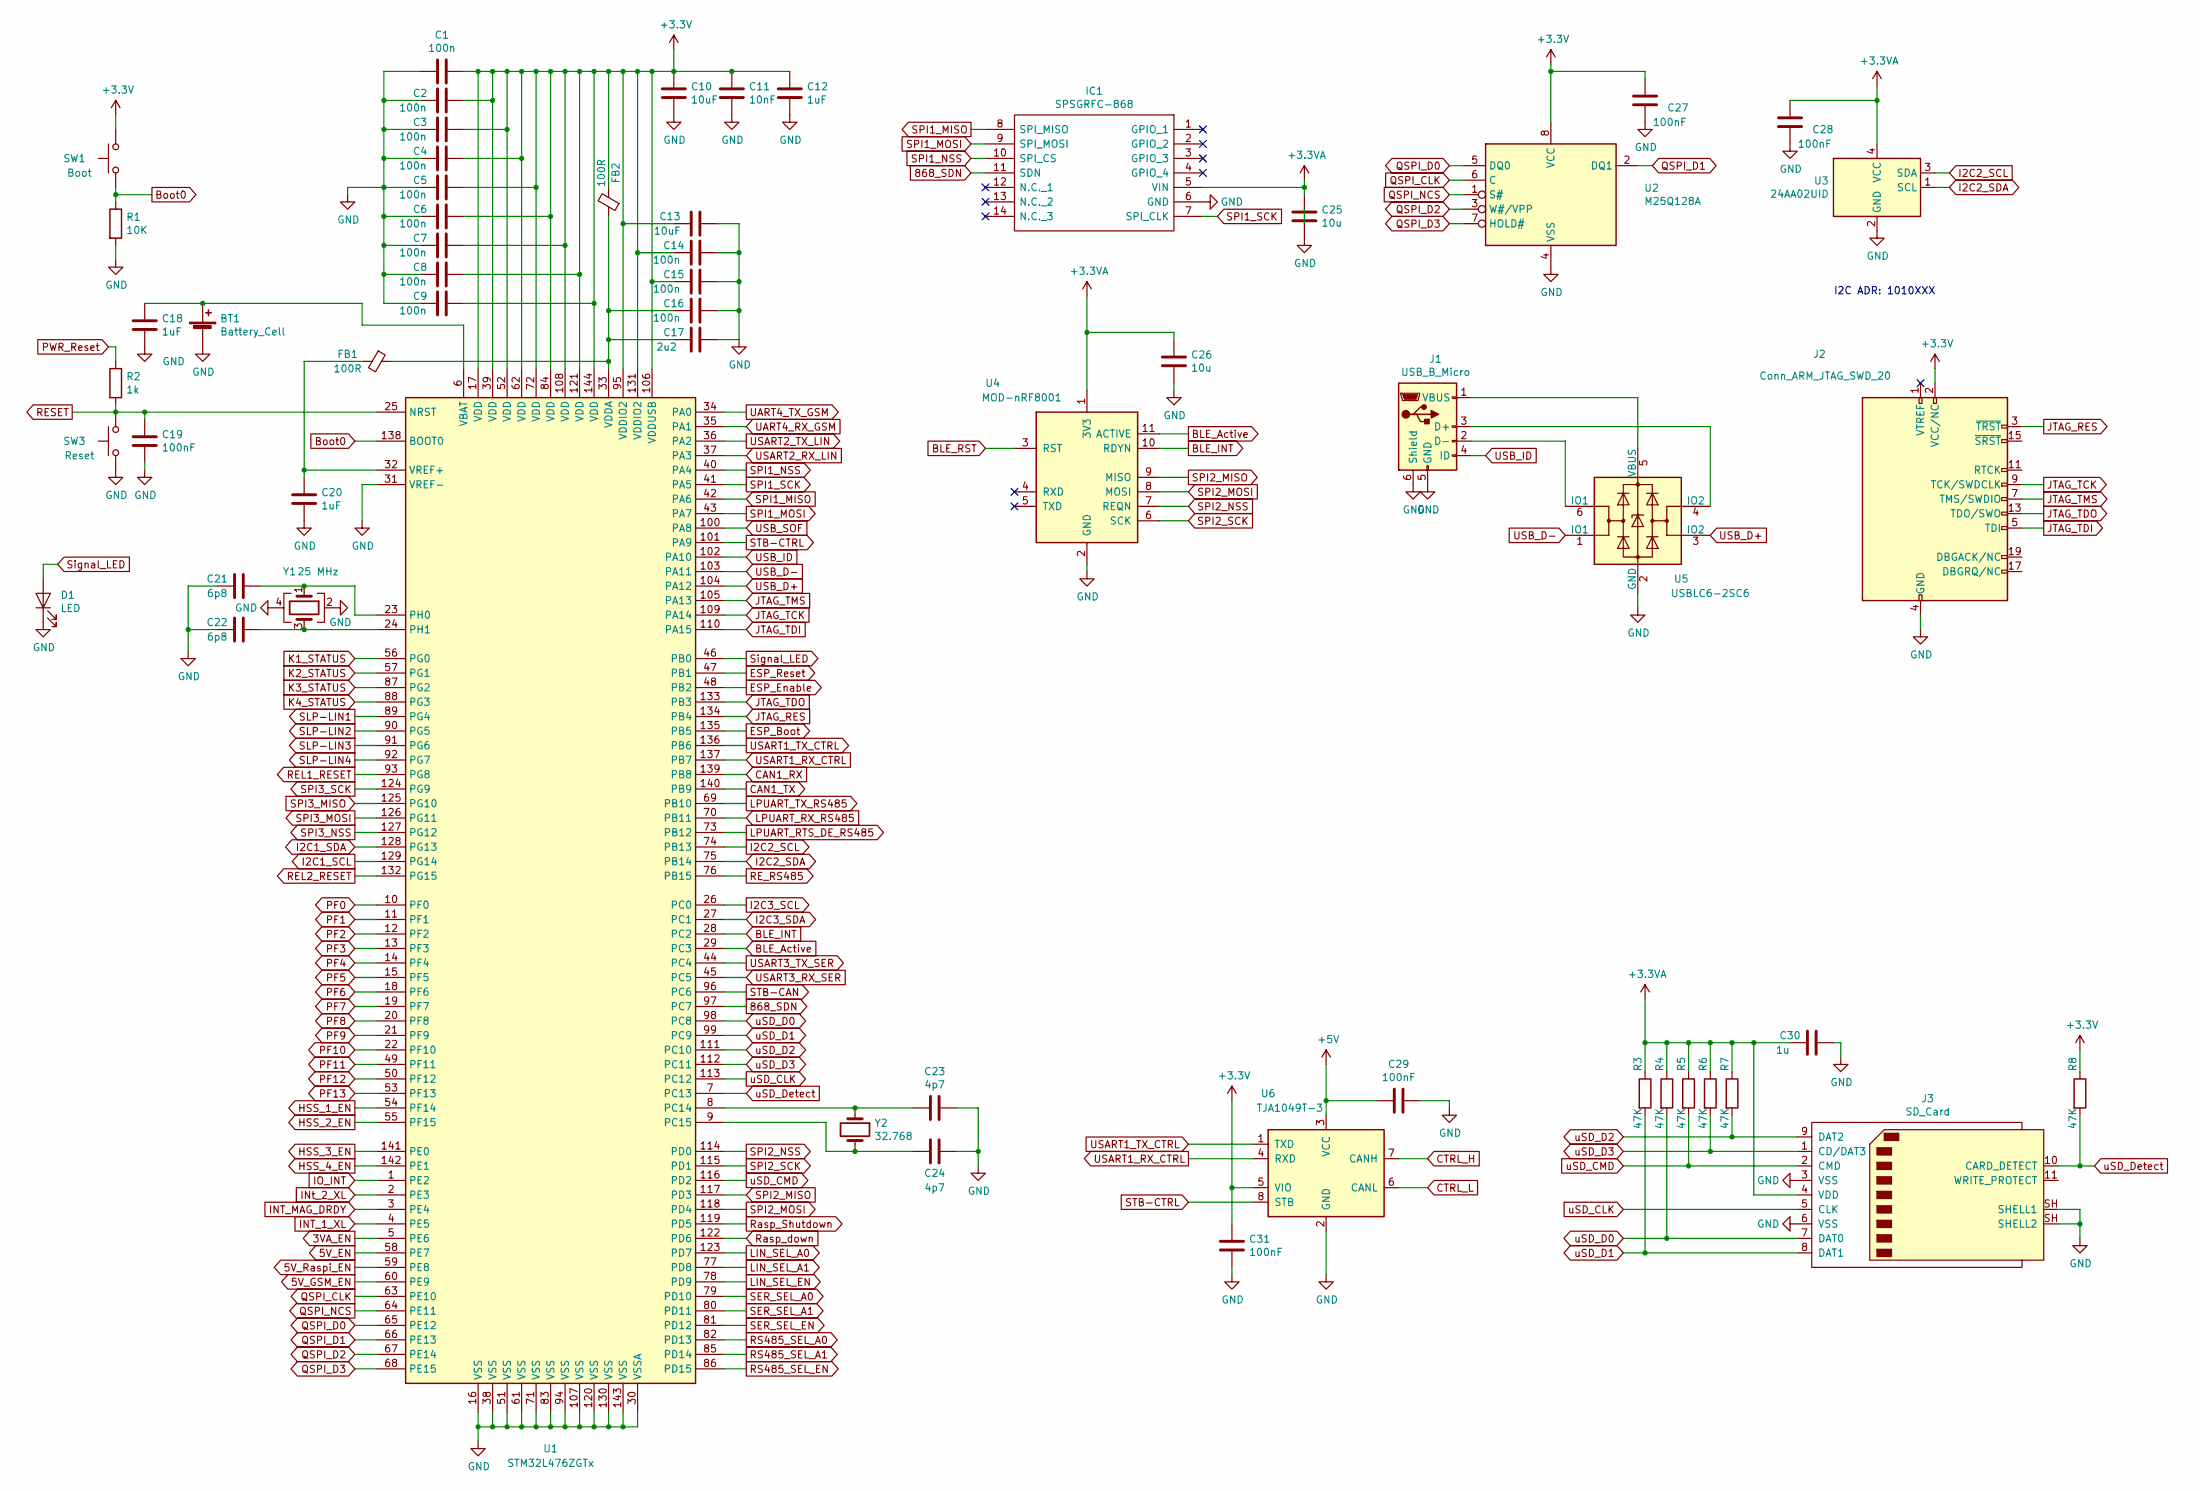
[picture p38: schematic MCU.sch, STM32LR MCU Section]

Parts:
BT1: Battery_Cell; BatteryHolder_Keystone_1058_1x2032
C1, C2, C3, C4, C5, C6, C7, C8, C9, C14, C15, C16: 100n; C_0603_1608Metric
C10, C13: 10uF; C_1210_3225Metric
C11: 10nF; C_0603_1608Metric
C12, C18, C20: 1uF; C_0603_1608Metric
C17: 2u2; C_1210_3225Metric
C19, C27, C28, C29, C31: 100nF; C_0603_1608Metric
C21, C22: 6p8; C_0603_1608Metric
C23, C24: 4p7; C_0603_1608Metric
C25, C26: 10u; C_1210_3225Metric
C30: 1u; C_0603_1608Metric
D1: LED; LED_1206_3216Metric
FB1, FB2: 100R; L_0603_1608Metric
IC1: SPSGRFC-868; SPSGRFC868; Manufacturer_Part_Number SPSGRFC-868; Mouser Part Number 511-SPSGRFC-868
J1: USB_B_Micro; USB_Micro-B_Molex-105017-0001
J2: Conn_ARM_JTAG_SWD_20; IDC-Header_2x10_P2.54mm_Vertical
J3: SD_Card; 10067847-001RLF
R1: 10K; R_0603_1608Metric
R2: 1k; R_0603_1608Metric
R3, R4, R5, R6, R7, R8: 47K; R_0603_1608Metric
SW1: Boot; SW_PUSH_6mm
SW3: Reset; SW_PUSH_6mm
U1: STM32L476ZGTx; LQFP-144_20x20mm_P0.5mm
U2: M25Q128A; SOIJ-8_5.3x5.3mm_P1.27mm
U3: 24AA02UID; SOT-23-5
U4: MOD-nRF8001
U5: USBLC6-2SC6; SOT-23-6
U6: TJA1049T-3; SOIC-8_3.9x4.9mm_P1.27mm
Y1: 25 MHz; Crystal_SMD_3225-4Pin_3.2x2.5mm
Y2: 32.768; Crystal_SMD_MicroCrystal_CC7V-T1A-2Pin_3.2x1.5mm

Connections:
3VA_EN: U1.5 (PE6); also elsewhere on the board
5V_EN: U1.58 (PE7); also elsewhere on the board
5V_GSM_EN: U1.60 (PE9); also elsewhere on the board
5V_Raspi_EN: U1.59 (PE8); also elsewhere on the board
868_SDN: IC1.11 (SDN), U1.97 (PC7)
+3.3VA: C25.1, C26.1, C28.1, C30.2, IC1.5 (VIN), J3.4 (VDD), R3.1, R4.1, R5.1, R6.1, R7.1, U3.4 (VCC), U4.1 (3V3); also elsewhere on the board
+3V3: C1.1, C2.1, C3.1, C4.1, C5.1, C6.1, C7.1, C8.1, C9.1, C10.1, C11.1, C12.1, C13.1, C14.2, C15.2, C27.1, C31.1, FB2.2, J2.2 (VCC/NC), R8.1, SW1.2, U1.17 (VDD), U1.39 (VDD), U1.52 (VDD), U1.62 (VDD), U1.72 (VDD), U1.84 (VDD), U1.95 (VDDIO2), U1.106 (VDDUSB), U1.108 (VDD), U1.121 (VDD), U1.131 (VDDIO2), U1.144 (VDD), U2.8 (VCC), U6.5 (VIO); also elsewhere on the board
+5V: C29.2, U6.3 (VCC); also elsewhere on the board
BLE_Active: U1.29 (PC3), U4.11 (ACTIVE)
BLE_INT: U1.28 (PC2), U4.10 (RDYN)
BLE_RST: U4.3 (RST)
Boot0: R1.1, SW1.1, U1.138 (BOOT0)
CAN1_RX: U1.139 (PB8); also elsewhere on the board
CAN1_TX: U1.140 (PB9); also elsewhere on the board
CTRL_H: U6.7 (CANH); also elsewhere on the board
CTRL_L: U6.6 (CANL); also elsewhere on the board
ESP_Boot: U1.135 (PB5); also elsewhere on the board
ESP_Enable: U1.48 (PB2); also elsewhere on the board
ESP_Reset: U1.47 (PB1); also elsewhere on the board
GND: BT1.2 (-), C1.2, C2.2, C3.2, C4.2, C5.2, C6.2, C7.2, C8.2, C9.2, C10.2, C11.2, C12.2, C13.2, C14.1, C15.1, C16.1, C17.1, C18.2, C19.2, C20.2, C21.2, C22.2, C23.1, C24.1, C25.2, C26.2, C27.2, C28.2, C29.1, C30.1, C31.2, D1.1 (K), IC1.6 (GND), J1.5 (GND), J1.6 (Shield), J2.4 (GND), J2.6 (GND), J2.8 (GND), J2.10 (GND), J2.12 (GND), J2.14 (GND), J2.16 (GND), J2.18 (GND), J2.20 (GND), J3.3 (VSS), J3.6 (VSS), J3.SH (SHELL1), R1.2, SW3.1, U1.16 (VSS), U1.30 (VSSA), U1.31 (VREF-), U1.38 (VSS), U1.51 (VSS), U1.61 (VSS), U1.71 (VSS), U1.83 (VSS), U1.94 (VSS), U1.107 (VSS), U1.120 (VSS), U1.130 (VSS), U1.143 (VSS), U2.4 (VSS), U3.2 (GND), U4.2 (GND), U5.2 (GND), U6.2 (GND), Y1.2, Y1.4; also elsewhere on the board
HSS_1_EN: U1.54 (PF14); also elsewhere on the board
HSS_2_EN: U1.55 (PF15); also elsewhere on the board
HSS_3_EN: U1.141 (PE0); also elsewhere on the board
HSS_4_EN: U1.142 (PE1); also elsewhere on the board
I2C1_SCL: U1.129 (PG14); also elsewhere on the board
I2C1_SDA: U1.128 (PG13); also elsewhere on the board
I2C2_SCL: U1.74 (PB13), U3.3 (SDA); also elsewhere on the board
I2C2_SDA: U1.75 (PB14), U3.1 (SCL); also elsewhere on the board
I2C3_SCL: U1.26 (PC0); also elsewhere on the board
I2C3_SDA: U1.27 (PC1); also elsewhere on the board
INT_1_XL: U1.4 (PE5); also elsewhere on the board
INT_MAG_DRDY: U1.3 (PE4); also elsewhere on the board
INt_2_XL: U1.2 (PE3); also elsewhere on the board
IO_INT: U1.1 (PE2); also elsewhere on the board
JTAG_RES: J2.3 (~TRST~), U1.134 (PB4)
JTAG_TCK: J2.9 (TCK/SWDCLK), U1.109 (PA14)
JTAG_TDI: J2.5 (TDI), U1.110 (PA15)
JTAG_TDO: J2.13 (TDO/SWO), U1.133 (PB3)
JTAG_TMS: J2.7 (TMS/SWDIO), U1.105 (PA13)
K1_STATUS: U1.56 (PG0); also elsewhere on the board
K2_STATUS: U1.57 (PG1); also elsewhere on the board
K3_STATUS: U1.87 (PG2); also elsewhere on the board
K4_STATUS: U1.88 (PG3); also elsewhere on the board
LIN_SEL_A0: U1.123 (PD7); also elsewhere on the board
LIN_SEL_A1: U1.77 (PD8); also elsewhere on the board
LIN_SEL_EN: U1.78 (PD9); also elsewhere on the board
LPUART_RTS_DE_RS485: U1.73 (PB12); also elsewhere on the board
LPUART_RX_RS485: U1.70 (PB11); also elsewhere on the board
LPUART_TX_RS485: U1.69 (PB10); also elsewhere on the board
unnamed: BT1.1 (+), C18.1, U1.6 (VBAT)
unnamed: C16.2, C17.2, FB1.1, FB2.1, U1.33 (VDDA)
unnamed: C20.1, FB1.2, U1.32 (VREF+)
unnamed: C21.1, U1.23 (PH0), Y1.1
unnamed: C22.1, U1.24 (PH1), Y1.3
unnamed: C23.2, U1.8 (PC14), Y2.1
unnamed: C24.2, U1.9 (PC15), Y2.2
unnamed: J1.1 (VBUS), U5.5 (VBUS)
unnamed: J1.2 (D-), U5.6 (IO1)
unnamed: J1.3 (D+), U5.4 (IO2)
PF0: U1.10 (PF0); also elsewhere on the board
PF1: U1.11 (PF1); also elsewhere on the board
PF2: U1.12 (PF2); also elsewhere on the board
PF3: U1.13 (PF3); also elsewhere on the board
PF4: U1.14 (PF4); also elsewhere on the board
PF5: U1.15 (PF5); also elsewhere on the board
PF6: U1.18 (PF6); also elsewhere on the board
PF7: U1.19 (PF7); also elsewhere on the board
PF8: U1.20 (PF8); also elsewhere on the board
PF9: U1.21 (PF9); also elsewhere on the board
PF10: U1.22 (PF10); also elsewhere on the board
PF11: U1.49 (PF11); also elsewhere on the board
PF12: U1.50 (PF12); also elsewhere on the board
PF13: U1.53 (PF13); also elsewhere on the board
PWR_Reset: R2.1; also elsewhere on the board
QSPI_CLK: U1.63 (PE10), U2.6 (C)
QSPI_D0: U1.65 (PE12), U2.5 (DQ0)
QSPI_D1: U1.66 (PE13), U2.2 (DQ1)
QSPI_D2: U1.67 (PE14), U2.3 (W#/VPP)
QSPI_D3: U1.68 (PE15), U2.7 (HOLD#)
QSPI_NCS: U1.64 (PE11), U2.1 (S#)
REL1_RESET: U1.93 (PG8); also elsewhere on the board
REL2_RESET: U1.132 (PG15); also elsewhere on the board
RESET: C19.1, R2.2, SW3.2, U1.25 (NRST)
RE_RS485: U1.76 (PB15); also elsewhere on the board
RS485_SEL_A0: U1.82 (PD13); also elsewhere on the board
RS485_SEL_A1: U1.85 (PD14); also elsewhere on the board
RS485_SEL_EN: U1.86 (PD15); also elsewhere on the board
Rasp_Shutdown: U1.119 (PD5); also elsewhere on the board
Rasp_down: U1.122 (PD6); also elsewhere on the board
SER_SEL_A0: U1.79 (PD10); also elsewhere on the board
SER_SEL_A1: U1.80 (PD11); also elsewhere on the board
SER_SEL_EN: U1.81 (PD12); also elsewhere on the board
SLP-LIN1: U1.89 (PG4); also elsewhere on the board
SLP-LIN2: U1.90 (PG5); also elsewhere on the board
SLP-LIN3: U1.91 (PG6); also elsewhere on the board
SLP-LIN4: U1.92 (PG7); also elsewhere on the board
SPI1_MISO: IC1.8 (SPI_MISO), U1.42 (PA6)
SPI1_MOSI: IC1.9 (SPI_MOSI), U1.43 (PA7)
SPI1_NSS: IC1.10 (SPI_CS), U1.40 (PA4)
SPI1_SCK: IC1.7 (SPI_CLK), U1.41 (PA5)
SPI2_MISO: U1.117 (PD3), U4.9 (MISO)
SPI2_MOSI: U1.118 (PD4), U4.8 (MOSI)
SPI2_NSS: U1.114 (PD0), U4.7 (REQN)
SPI2_SCK: U1.115 (PD1), U4.6 (SCK)
SPI3_MISO: U1.125 (PG10); also elsewhere on the board
SPI3_MOSI: U1.126 (PG11); also elsewhere on the board
SPI3_NSS: U1.127 (PG12); also elsewhere on the board
SPI3_SCK: U1.124 (PG9); also elsewhere on the board
STB-CAN: U1.96 (PC6); also elsewhere on the board
STB-CTRL: U1.101 (PA9), U6.8 (STB)
Signal_LED: D1.2 (A), U1.46 (PB0)
UART4_RX_GSM: U1.35 (PA1); also elsewhere on the board
UART4_TX_GSM: U1.34 (PA0); also elsewhere on the board
USART1_RX_CTRL: U1.137 (PB7), U6.4 (RXD)
USART1_TX_CTRL: U1.136 (PB6), U6.1 (TXD)
USART2_RX_LIN: U1.37 (PA3); also elsewhere on the board
USART2_TX_LIN: U1.36 (PA2); also elsewhere on the board
USART3_RX_SER: U1.45 (PC5); also elsewhere on the board
USART3_TX_SER: U1.44 (PC4); also elsewhere on the board
USB_D+: U1.104 (PA12), U5.3 (IO2)
USB_D-: U1.103 (PA11), U5.1 (IO1)
USB_ID: J1.4 (ID), U1.102 (PA10)
USB_SOF: U1.100 (PA8)
uSD_CLK: J3.5 (CLK), U1.113 (PC12)
uSD_CMD: J3.2 (CMD), R5.2, U1.116 (PD2)
uSD_D0: J3.7 (DAT0), R4.2, U1.98 (PC8)
uSD_D1: J3.8 (DAT1), R3.2, U1.99 (PC9)
uSD_D2: J3.9 (DAT2), R7.2, U1.111 (PC10)
uSD_D3: J3.1 (CD/DAT3), R6.2, U1.112 (PC11)
uSD_Detect: J3.10 (CARD_DETECT), R8.2, U1.7 (PC13)

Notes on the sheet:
I2C ADR: 1010XXX

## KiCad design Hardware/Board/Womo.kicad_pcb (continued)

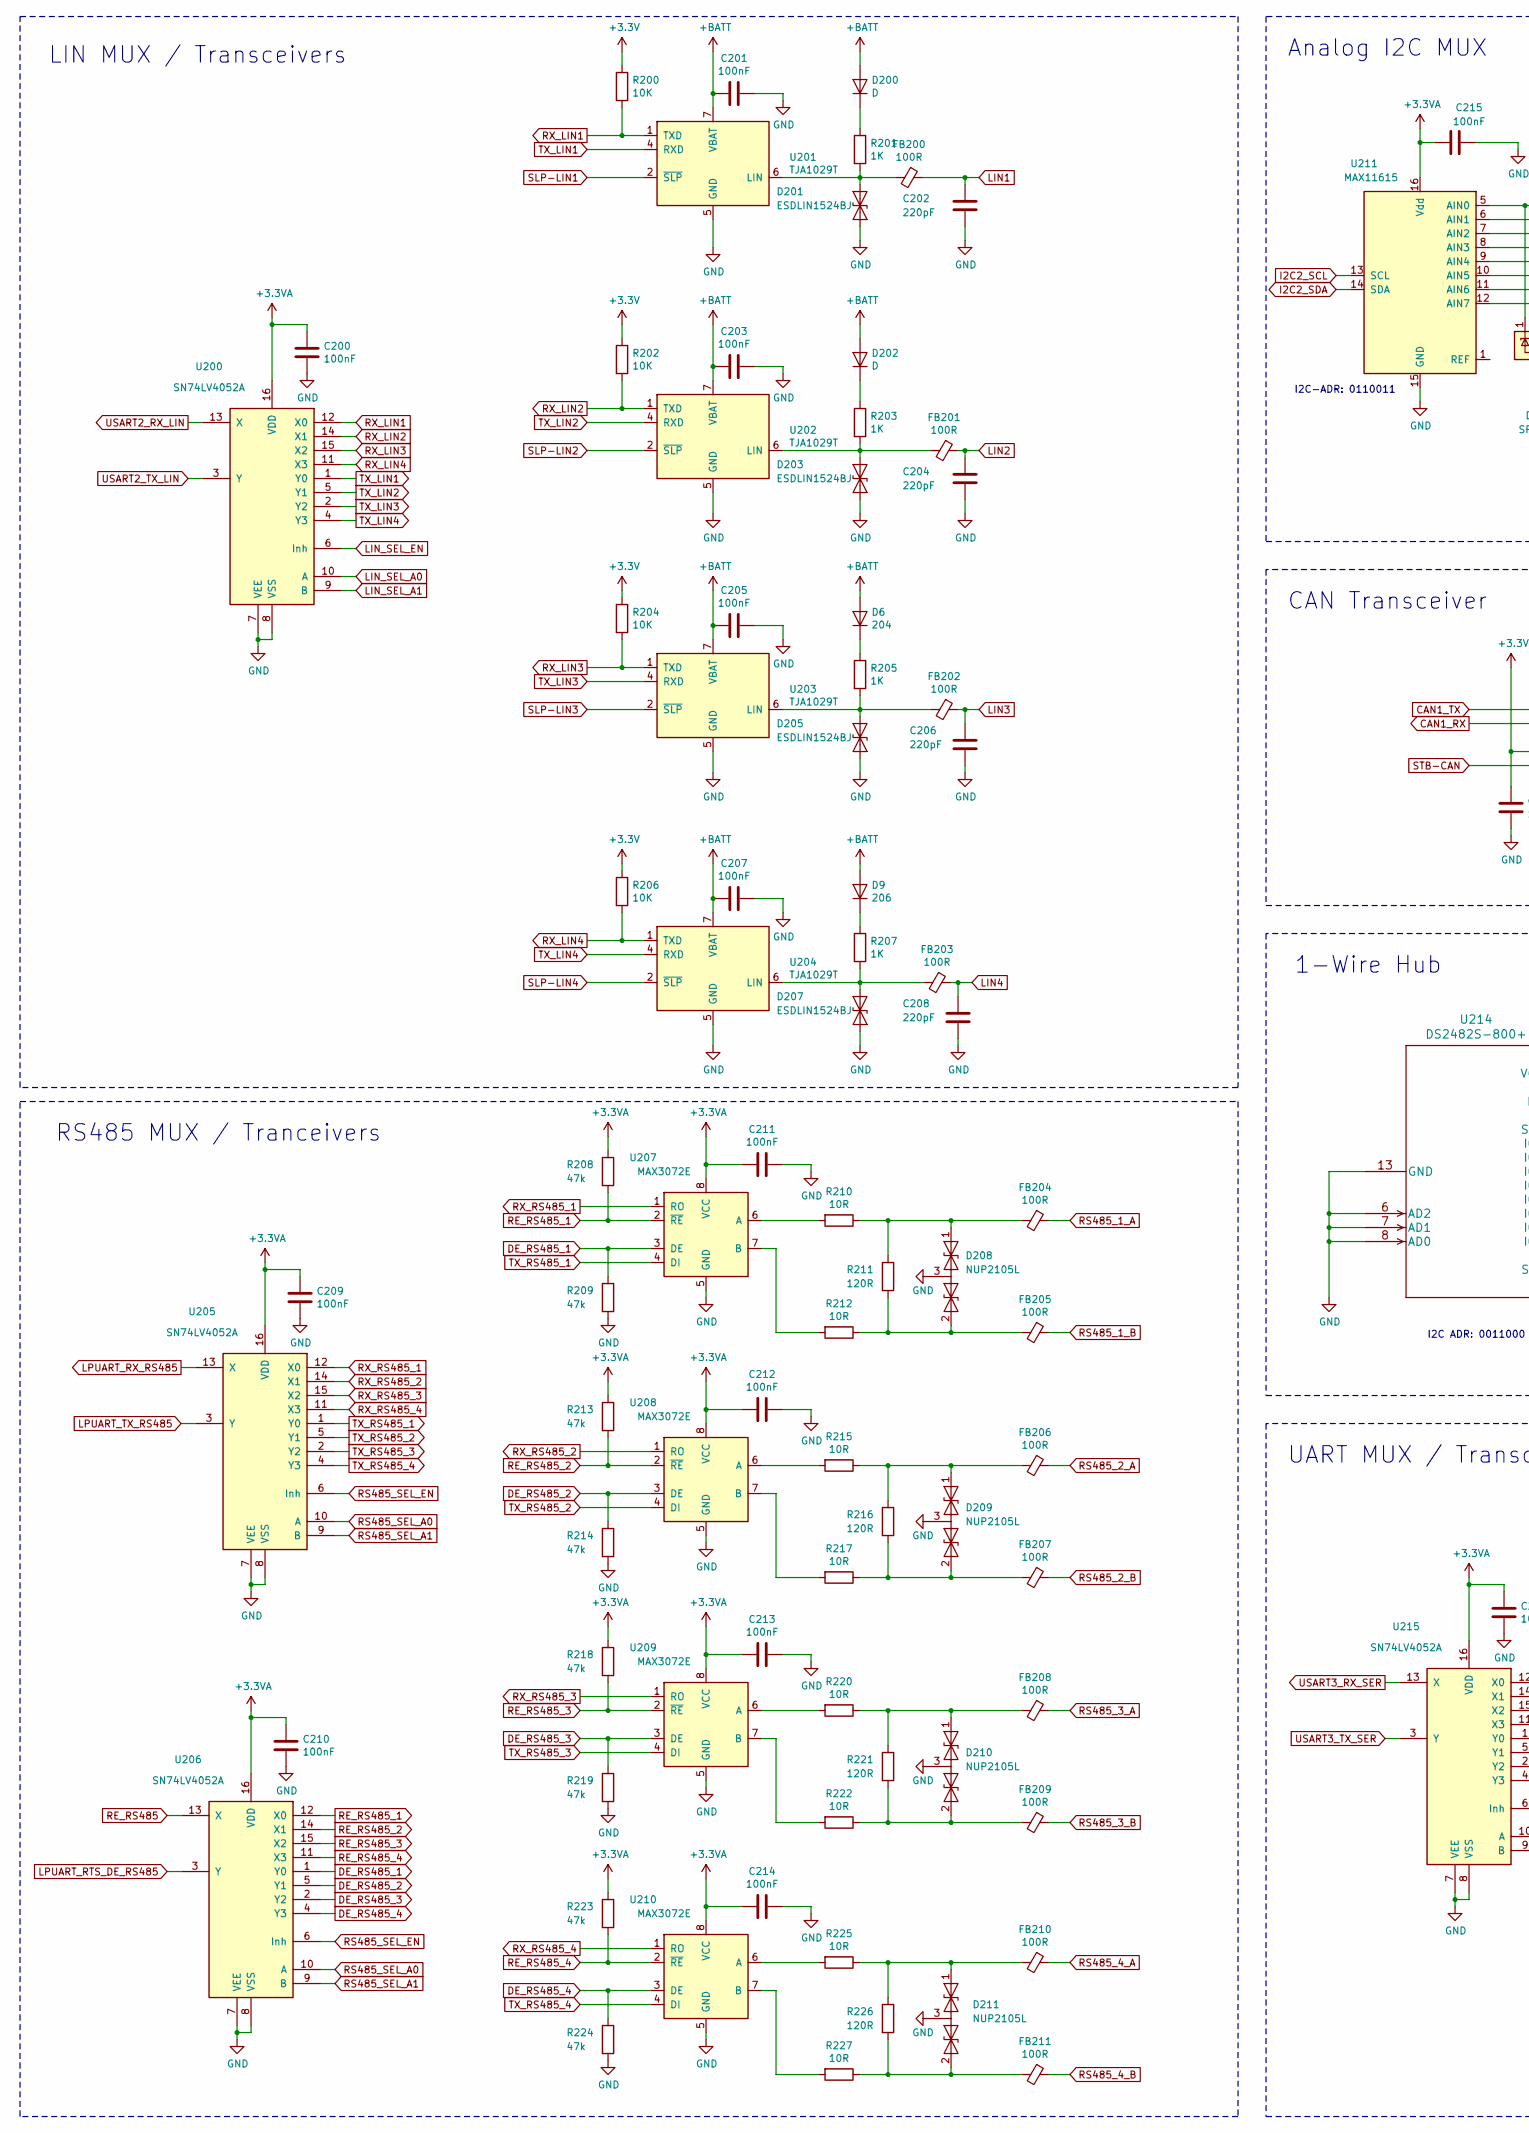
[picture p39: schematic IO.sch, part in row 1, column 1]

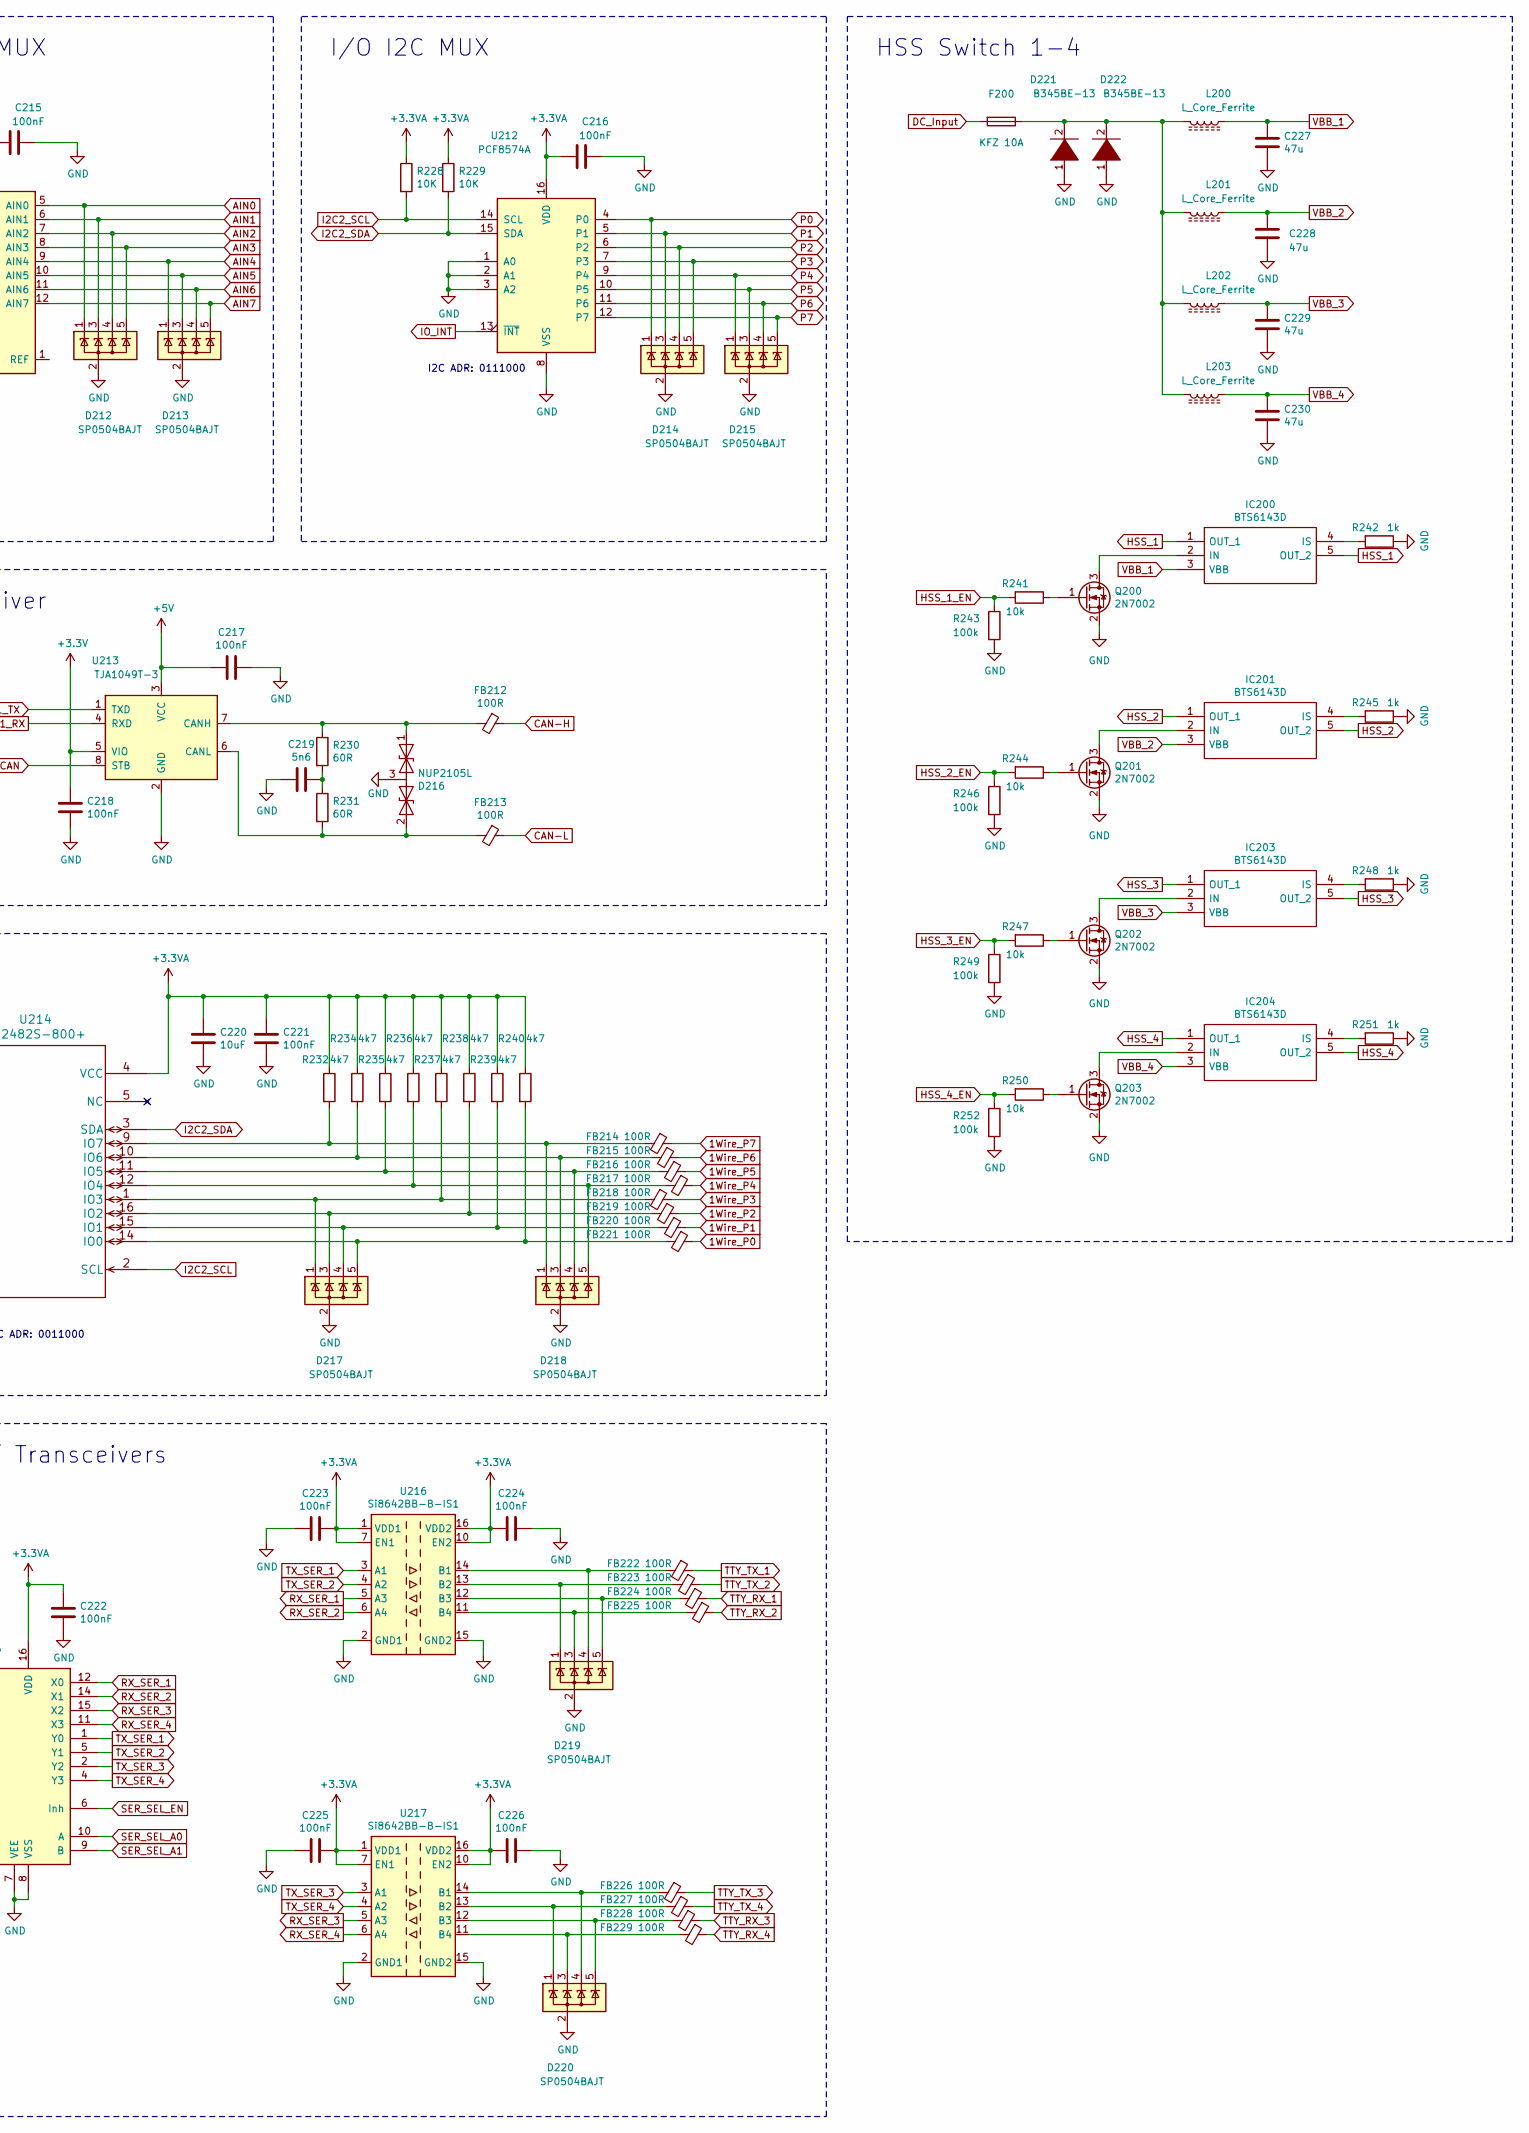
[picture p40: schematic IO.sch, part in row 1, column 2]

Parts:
C200, C201, C203, C205, C207, C209, C210, C211, C212, C213, C214, C215, C216, C217, C218, C221, C222, C223, C224, C225, C226: 100nF; C_0603_1608Metric
C202, C204, C206, C208: 220pF; C_0603_1608Metric
C219: 5n6; C_0603_1608Metric
C220: 10uF; C_1210_3225Metric
C227, C228, C229, C230: 47u; C_1210_3225Metric
D6: 204; D_SOD-323
D9: 206; D_SOD-323
D200, D202: D; D_SOD-323
D201, D203, D205, D207: ESDLIN1524BJ; D_SOD-323
D208, D209, D210, D211, D216: NUP2105L; SOT-23
D212, D213, D214, D215, D217, D218, D219, D220: SP0504BAJT; SOT-353_SC-70-5
D221, D222: B345BE-13; D_SMB
F200: KFZ 10A; Fuseholder_Blade_ATO_Littelfuse_Pudenz_2_Pin
FB200, FB201, FB202, FB203, FB204, FB205, FB206, FB207, FB208, FB209, FB210, FB211, FB212, FB213, FB214, FB215, FB216, FB217, FB218, FB219, FB220, FB221, FB222, FB223, FB224, FB225, FB226, FB227, FB228, FB229: 100R; L_0603_1608Metric
IC200, IC201, IC203, IC204: BTS6143D; Mouser Part Number 726-BTS6143D
L200, L201, L202, L203: L_Core_Ferrite; L_Coilcraft_XxL4020
Q200, Q201, Q202, Q203: 2N7002; SOT-23
R200, R202, R204, R206, R228, R229: 10K; R_0603_1608Metric
R201, R203, R205, R207: 1K; R_0603_1608Metric
R208, R209, R213, R214, R218, R219, R223, R224: 47k; R_0603_1608Metric
R210, R212, R215, R217, R220, R222, R225, R227: 10R; R_0603_1608Metric
R211, R216, R221, R226: 120R; R_0603_1608Metric
R230, R231: 60R; R_0603_1608Metric
R232, R234, R235, R236, R237, R238, R239, R240: 4k7; R_0603_1608Metric
R241, R244, R247, R250: 10k; R_0603_1608Metric
R242, R245, R248, R251: 1k; R_0603_1608Metric
R243, R246, R249, R252: 100k; R_0603_1608Metric
U200, U205, U206, U215: SN74LV4052A; TSSOP-16_4.4x5mm_P0.65mm
U201, U202, U203, U204: TJA1029T; SOIC-8_3.9x4.9mm_P1.27mm
U207, U208, U209, U210: MAX3072E; SOIC-8_3.9x4.9mm_P1.27mm
U211: MAX11615; QSOP-16_3.9x4.9mm_P0.635mm
U212: PCF8574A; SOIC-16W_7.5x10.3mm_P1.27mm
U213: TJA1049T-3; SOIC-8_3.9x4.9mm_P1.27mm
U214: DS2482S-800+; SOIC-16_3.9x9.9mm_P1.27mm
U216, U217: Si8642BB-B-IS1; SOIC-16_3.9x9.9mm_P1.27mm

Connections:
1Wire_P0: FB221.1; also elsewhere on the board
1Wire_P1: FB220.1; also elsewhere on the board
1Wire_P2: FB219.1; also elsewhere on the board
1Wire_P3: FB218.1; also elsewhere on the board
1Wire_P4: FB217.1; also elsewhere on the board
1Wire_P5: FB216.1; also elsewhere on the board
1Wire_P6: FB215.1; also elsewhere on the board
1Wire_P7: FB214.1; also elsewhere on the board
+3.3VA: C200.1, C209.1, C210.1, C211.2, C212.2, C213.2, C214.2, C215.2, C216.2, C220.1, C221.1, C222.1, C223.1, C224.2, C225.1, C226.2, R208.1, R213.1, R218.1, R223.1, R228.1, R229.1, R232.1, R234.1, R235.1, R236.1, R237.1, R238.1, R239.1, R240.1, U200.16 (VDD), U205.16 (VDD), U206.16 (VDD), U207.8 (VCC), U208.8 (VCC), U209.8 (VCC), U210.8 (VCC), U211.16 (Vdd), U212.16 (VDD), U214.4 (VCC), U215.16 (VDD), U216.1 (VDD1), U216.7 (EN1), U216.10 (EN2), U216.16 (VDD2), U217.1 (VDD1), U217.7 (EN1), U217.10 (EN2), U217.16 (VDD2); also elsewhere on the board
+3V3: C218.1, R200.1, R202.1, R204.1, R206.1, U213.5 (VIO); also elsewhere on the board
+5V: C217.2, U213.3 (VCC); also elsewhere on the board
+BATT: C201.2, C203.2, C205.2, C207.2, D6.2 (A), D9.2 (A), D200.2 (A), D202.2 (A), U201.7 (VBAT), U202.7 (VBAT), U203.7 (VBAT), U204.7 (VBAT); also elsewhere on the board
AIN0: D212.1 (K), U211.5 (AIN0); also elsewhere on the board
AIN1: D212.3 (K), U211.6 (AIN1); also elsewhere on the board
AIN2: D212.4 (K), U211.7 (AIN2); also elsewhere on the board
AIN3: D212.5 (K), U211.8 (AIN3); also elsewhere on the board
AIN4: D213.1 (K), U211.9 (AIN4); also elsewhere on the board
AIN5: D213.3 (K), U211.10 (AIN5); also elsewhere on the board
AIN6: D213.4 (K), U211.11 (AIN6); also elsewhere on the board
AIN7: D213.5 (K), U211.12 (AIN7); also elsewhere on the board
CAN1_RX: U213.4 (RXD); also elsewhere on the board
CAN1_TX: U213.1 (TXD); also elsewhere on the board
CAN-H: FB212.1; also elsewhere on the board
CAN-L: FB213.1; also elsewhere on the board
DC_Input: F200.2; also elsewhere on the board
DE_RS485_1: R209.1, U206.1 (Y0), U207.3 (DE)
DE_RS485_2: R214.1, U206.5 (Y1), U208.3 (DE)
DE_RS485_3: R219.1, U206.2 (Y2), U209.3 (DE)
DE_RS485_4: R224.1, U206.4 (Y3), U210.3 (DE)
GND: C200.2, C201.1, C202.2, C203.1, C204.2, C205.1, C206.2, C207.1, C208.2, C209.2, C210.2, C211.1, C212.1, C213.1, C214.1, C215.1, C216.1, C217.1, C218.2, C219.2, C220.2, C221.2, C222.2, C223.2, C224.1, C225.2, C226.1, C227.2, C228.2, C229.2, C230.2, D201.2 (A2), D203.2 (A2), D205.2 (A2), D207.2 (A2), D208.3 (common), D209.3 (common), D210.3 (common), D211.3 (common), D212.2 (A), D213.2 (A), D214.2 (A), D215.2 (A), D216.3 (common), D217.2 (A), D218.2 (A), D219.2 (A), D220.2 (A), D221.1 (K), D222.1 (K), Q200.2 (S), Q201.2 (S), Q202.2 (S), Q203.2 (S), R209.2, R214.2, R219.2, R224.2, R242.1, R243.2, R245.1, R246.2, R248.1, R249.2, R251.1, R252.2, U200.7 (VEE), U200.8 (VSS), U201.5 (GND), U202.5 (GND), U203.5 (GND), U204.5 (GND), U205.7 (VEE), U205.8 (VSS), U206.7 (VEE), U206.8 (VSS), U207.5 (GND), U208.5 (GND), U209.5 (GND), U210.5 (GND), U211.15 (GND), U212.1 (A0), U212.2 (A1), U212.3 (A2), U212.8 (VSS), U213.2 (GND), U214.6 (AD2), U214.7 (AD1), U214.8 (AD0), U214.13 (GND), U215.7 (VEE), U215.8 (VSS), U216.2 (GND1), U216.8 (GND1), U216.9 (GND2), U216.15 (GND2), U217.2 (GND1), U217.8 (GND1), U217.9 (GND2), U217.15 (GND2); also elsewhere on the board
HSS_1: IC200.1 (OUT_1), IC200.5 (OUT_2); also elsewhere on the board
HSS_1_EN: R241.2, R243.1; also elsewhere on the board
HSS_2: IC201.1 (OUT_1), IC201.5 (OUT_2); also elsewhere on the board
HSS_2_EN: R244.2, R246.1; also elsewhere on the board
HSS_3: IC203.1 (OUT_1), IC203.5 (OUT_2); also elsewhere on the board
HSS_3_EN: R247.2, R249.1; also elsewhere on the board
HSS_4: IC204.1 (OUT_1), IC204.5 (OUT_2); also elsewhere on the board
HSS_4_EN: R250.2, R252.1; also elsewhere on the board
I2C2_SCL: R228.2, U211.13 (SCL), U212.14 (SCL), U214.2 (SCL); also elsewhere on the board
I2C2_SDA: R229.2, U211.14 (SDA), U212.15 (SDA), U214.3 (SDA); also elsewhere on the board
IO_INT: U212.13 (~INT~); also elsewhere on the board
LIN1: C202.1, FB200.1; also elsewhere on the board
LIN2: C204.1, FB201.1; also elsewhere on the board
LIN3: C206.1, FB202.1; also elsewhere on the board
LIN4: C208.1, FB203.1; also elsewhere on the board
LIN_SEL_A0: U200.10 (A); also elsewhere on the board
LIN_SEL_A1: U200.9 (B); also elsewhere on the board
LIN_SEL_EN: U200.6 (Inh); also elsewhere on the board
LPUART_RTS_DE_RS485: U206.3 (Y); also elsewhere on the board
LPUART_RX_RS485: U205.13 (X); also elsewhere on the board
LPUART_TX_RS485: U205.3 (Y); also elsewhere on the board
unnamed: C219.1, R230.2, R231.1
unnamed: D6.1 (K), R205.1
unnamed: D9.1 (K), R207.1
unnamed: D200.1 (K), R201.1
unnamed: D201.1 (A1), FB200.2, R201.2, U201.6 (LIN)
unnamed: D202.1 (K), R203.1
unnamed: D203.1 (A1), FB201.2, R203.2, U202.6 (LIN)
unnamed: D205.1 (A1), FB202.2, R205.2, U203.6 (LIN)
unnamed: D207.1 (A1), FB203.2, R207.2, U204.6 (LIN)
unnamed: D208.1 (A1), FB204.2, R210.1, R211.1
unnamed: D208.2 (A2), FB205.2, R211.2, R212.1
unnamed: D209.1 (A1), FB206.2, R215.1, R216.1
unnamed: D209.2 (A2), FB207.2, R216.2, R217.1
unnamed: D210.1 (A1), FB208.2, R220.1, R221.1
unnamed: D210.2 (A2), FB209.2, R221.2, R222.1
unnamed: D211.1 (A1), FB210.2, R225.1, R226.1
unnamed: D211.2 (A2), FB211.2, R226.2, R227.1
unnamed: D216.1 (A1), FB212.2, R230.1, U213.7 (CANH)
unnamed: D216.2 (A2), FB213.2, R231.2, U213.6 (CANL)
unnamed: D217.1 (K), FB218.2, R237.2, U214.1 (IO3)
unnamed: D217.3 (K), FB219.2, R238.2, U214.16 (IO2)
unnamed: D217.4 (K), FB220.2, R239.2, U214.15 (IO1)
unnamed: D217.5 (K), FB221.2, R240.2, U214.14 (IO0)
unnamed: D218.1 (K), FB214.2, R232.2, U214.9 (IO7)
unnamed: D218.3 (K), FB215.2, R234.2, U214.10 (IO6)
unnamed: D218.4 (K), FB216.2, R235.2, U214.11 (IO5)
unnamed: D218.5 (K), FB217.2, R236.2, U214.12 (IO4)
unnamed: D219.1 (K), FB223.2, U216.13 (B2)
unnamed: D219.3 (K), FB225.2, U216.11 (B4)
unnamed: D219.4 (K), FB222.2, U216.14 (B1)
unnamed: D219.5 (K), FB224.2, U216.12 (B3)
unnamed: D220.1 (K), FB227.2, U217.13 (B2)
unnamed: D220.3 (K), FB229.2, U217.11 (B4)
unnamed: D220.4 (K), FB226.2, U217.14 (B1)
unnamed: D220.5 (K), FB228.2, U217.12 (B3)
unnamed: D221.2 (A), D222.2 (A), F200.1, L200.2, L201.2, L202.2, L203.2
unnamed: IC200.2 (IN), Q200.3 (D)
unnamed: IC200.4 (IS), R242.2
unnamed: IC201.2 (IN), Q201.3 (D)
unnamed: IC201.4 (IS), R245.2
unnamed: IC203.2 (IN), Q202.3 (D)
unnamed: IC203.4 (IS), R248.2
unnamed: IC204.2 (IN), Q203.3 (D)
unnamed: IC204.4 (IS), R251.2
unnamed: Q200.1 (G), R241.1
unnamed: Q201.1 (G), R244.1
unnamed: Q202.1 (G), R247.1
unnamed: Q203.1 (G), R250.1
unnamed: R210.2, U207.6 (A)
unnamed: R212.2, U207.7 (B)
unnamed: R215.2, U208.6 (A)
unnamed: R217.2, U208.7 (B)
unnamed: R220.2, U209.6 (A)
unnamed: R222.2, U209.7 (B)
unnamed: R225.2, U210.6 (A)
unnamed: R227.2, U210.7 (B)
P0: D214.1 (K), U212.4 (P0); also elsewhere on the board
P1: D214.3 (K), U212.5 (P1); also elsewhere on the board
P2: D214.4 (K), U212.6 (P2); also elsewhere on the board
P3: D214.5 (K), U212.7 (P3); also elsewhere on the board
P4: D215.1 (K), U212.9 (P4); also elsewhere on the board
P5: D215.3 (K), U212.10 (P5); also elsewhere on the board
P6: D215.4 (K), U212.11 (P6); also elsewhere on the board
P7: D215.5 (K), U212.12 (P7); also elsewhere on the board
RE_RS485: U206.13 (X); also elsewhere on the board
RE_RS485_1: R208.2, U206.12 (X0), U207.2 (~RE~)
RE_RS485_2: R213.2, U206.14 (X1), U208.2 (~RE~)
RE_RS485_3: R218.2, U206.15 (X2), U209.2 (~RE~)
RE_RS485_4: R223.2, U206.11 (X3), U210.2 (~RE~)
RS485_1_A: FB204.1; also elsewhere on the board
RS485_1_B: FB205.1; also elsewhere on the board
RS485_2_A: FB206.1; also elsewhere on the board
RS485_2_B: FB207.1; also elsewhere on the board
RS485_3_A: FB208.1; also elsewhere on the board
RS485_3_B: FB209.1; also elsewhere on the board
RS485_4_A: FB210.1; also elsewhere on the board
RS485_4_B: FB211.1; also elsewhere on the board
RS485_SEL_A0: U205.10 (A), U206.10 (A); also elsewhere on the board
RS485_SEL_A1: U205.9 (B), U206.9 (B); also elsewhere on the board
RS485_SEL_EN: U205.6 (Inh), U206.6 (Inh); also elsewhere on the board
RX_LIN1: R200.2, U200.12 (X0), U201.1 (TXD)
RX_LIN2: R202.2, U200.14 (X1), U202.1 (TXD)
RX_LIN3: R204.2, U200.15 (X2), U203.1 (TXD)
RX_LIN4: R206.2, U200.11 (X3), U204.1 (TXD)
RX_RS485_1: U205.12 (X0), U207.1 (RO)
RX_RS485_2: U205.14 (X1), U208.1 (RO)
RX_RS485_3: U205.15 (X2), U209.1 (RO)
RX_RS485_4: U205.11 (X3), U210.1 (RO)
RX_SER_1: U215.12 (X0), U216.5 (A3)
RX_SER_2: U215.14 (X1), U216.6 (A4)
RX_SER_3: U215.15 (X2), U217.5 (A3)
RX_SER_4: U215.11 (X3), U217.6 (A4)
SER_SEL_A0: U215.10 (A); also elsewhere on the board
SER_SEL_A1: U215.9 (B); also elsewhere on the board
SER_SEL_EN: U215.6 (Inh); also elsewhere on the board
SLP-LIN1: U201.2 (~SLP~); also elsewhere on the board
SLP-LIN2: U202.2 (~SLP~); also elsewhere on the board
SLP-LIN3: U203.2 (~SLP~); also elsewhere on the board
SLP-LIN4: U204.2 (~SLP~); also elsewhere on the board
STB-CAN: U213.8 (STB); also elsewhere on the board
TTY_RX_1: FB224.1; also elsewhere on the board
TTY_RX_2: FB225.1; also elsewhere on the board
TTY_RX_3: FB228.1; also elsewhere on the board
TTY_RX_4: FB229.1; also elsewhere on the board
TTY_TX_1: FB222.1; also elsewhere on the board
TTY_TX_2: FB223.1; also elsewhere on the board
TTY_TX_3: FB226.1; also elsewhere on the board
TTY_TX_4: FB227.1; also elsewhere on the board
TX_LIN1: U200.1 (Y0), U201.4 (RXD)
TX_LIN2: U200.5 (Y1), U202.4 (RXD)
TX_LIN3: U200.2 (Y2), U203.4 (RXD)
TX_LIN4: U200.4 (Y3), U204.4 (RXD)
TX_RS485_1: U205.1 (Y0), U207.4 (DI)
TX_RS485_2: U205.5 (Y1), U208.4 (DI)
TX_RS485_3: U205.2 (Y2), U209.4 (DI)
TX_RS485_4: U205.4 (Y3), U210.4 (DI)
TX_SER_1: U215.1 (Y0), U216.3 (A1)
TX_SER_2: U215.5 (Y1), U216.4 (A2)
TX_SER_3: U215.2 (Y2), U217.3 (A1)
TX_SER_4: U215.4 (Y3), U217.4 (A2)
USART2_RX_LIN: U200.13 (X); also elsewhere on the board
USART2_TX_LIN: U200.3 (Y); also elsewhere on the board
USART3_RX_SER: U215.13 (X); also elsewhere on the board
USART3_TX_SER: U215.3 (Y); also elsewhere on the board
VBB_1: C227.1, IC200.3 (VBB), L200.1
VBB_2: C228.1, IC201.3 (VBB), L201.1
VBB_3: C229.1, IC203.3 (VBB), L202.1
VBB_4: C230.1, IC204.3 (VBB), L203.1

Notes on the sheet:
I2C-ADR: 0110011
I2C ADR: 0111000
I2C ADR: 0011000
LIN MUX / Transceivers
RS485 MUX / Tranceivers
UART MUX / Transceivers
CAN Transceiver
1-Wire Hub
Analog I2C MUX
I/O I2C MUX
HSS Switch 1-4

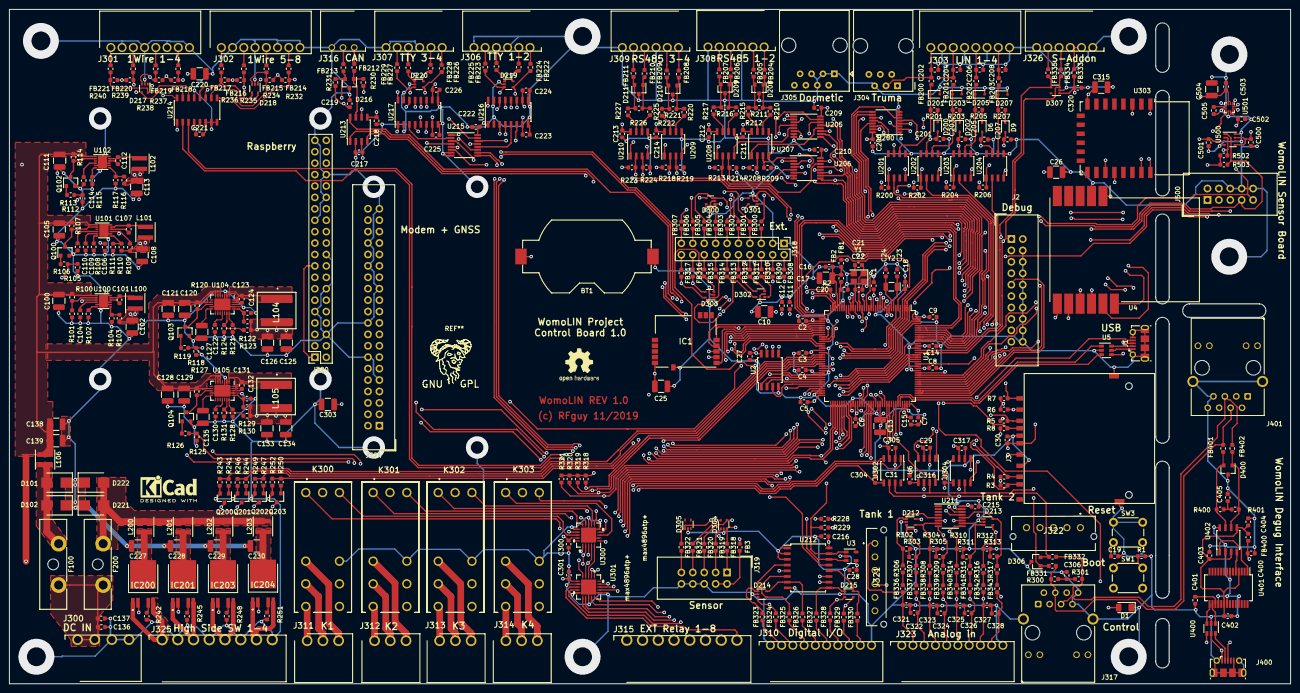
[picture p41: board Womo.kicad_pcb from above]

Board: 4 copper layers, 285.0 x 150.0 mm, 465 parts (0 on the bottom side), 417 nets.

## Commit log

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2019-03-15 KiCad Schematic angelegt, Prozessor und Interface Bausteine ausgewählt.
    [IO.sch, MCU.sch, Power.sch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]
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2019-03-29 Controller auf 100 Pin Version geändert, Pins ersten Funktionen zugeordnet.
    [MCU.sch]
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2019-04-17 Netzliste und Board erstellt, hier sind noch Fehler im Bereich Footprints, BLE Modul nRF8001 hinzugefügt, erste Anschlussklemmen zugefügt
    [Connector.sch, IO.sch, MCU.sch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]
2019-04-26 Änderung CPU auf einen mit Display Controller, vorbereitung zum Anschluss SSD1963 und Digital RGB Displays
    [MCU.sch, Womo.sch]
2019-05-10 Display auf 40 Pin FPC reduziert, nur Verwendung des internen Display Controllers, Library Updates
    [2604-1102.stp, 2604-1103.stp, 2604-1104.stp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]
2019-05-27 Port Bezeichnungen am Prozessor korrigiert, Schnittstellen angepasst.
    [IO.sch, MCU.sch, Power.sch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]
2019-05-28 Octo SPI Flash und RAM zugefügt, weitere Bezeichnungen auf Stand gebracht
    [0201.stp, 0402.stp, 0603.stp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]
2019-05-31 Eine Menge Arbeit auf der GPN, fast fertig im Schaltplan.
    [Connector.sch, IO.sch, MCU.sch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]
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2019-06-12 Resitiven Touch Controller eingefügt, diverse I2C Parts hinzu gefügt, Netze umgenannt
    [Connector.sch, IO.sch, MCU.sch]
2019-06-13 GSM Modul SIM800L eingefügt, Spannung MCU Board umgenannt
    [Connector.sch, IO.sch, MCU.sch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]
2019-06-14 MCU Section fertig, Analog Inputs angelegt, Schaltplan neu organisiert, alte Datenblätter entfernt.
    [Connector.sch, IO.sch, MCU.sch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]
2019-06-27 Trennung MCU und Rest, Footprints fast alles zugewiesen, GSM Modul integriert, viel Kleinkram
    [Connector.sch, IO.sch, MCU.sch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]
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2019-07-02 Alle Footprints definiert, Libs angepasst, Layout gestartet mit Plazierung, Controller und Breakout Netzmäßig getrennt.
    [Connector.sch, IO.sch, MCU.sch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]
2019-07-03 Komplete enummerierung Geändert, Schaltplan zusammengefasst, Layout nochmals reset. BOM zu 75% fertig gestellt
    [Connector.sch, IO.sch, MCU.sch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]
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2019-09-19 Änderung des Konzeptes auf 2 Boards, eines TFT Touch mit STM32L4R9, das rein die Bedienung macht. Control Board mit STM32L476, mit noch mehr Schnittstellen. Bus zwischen Display, Board, Raspberry/ESP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
    [0201.stp, 0402.stp, 0603.stp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]
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2019-09-26 Display Unit Lib Fehler behoben, und noch Zeug raus geworfen Library jetzt projekt spezifisch im Hardware root.. Hauptplatine rund um den Prozessor a bissl was getan, vorbereitung Quadspi Flash und S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
    [0201.stp, 0402.stp, 0603.stp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]
2019-09-27 Alle Busse aus dem Prozessor geroutet, Multplexing der LIN, RS485 und TTY Busse, diverse Aufräumarbeiten.
    [Connector.sch, IO.sch, MCU.sch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]
2019-10-01 Prozessor Pins zugeordnet, 4 bistabile Relais, CAN Control Interface, CAN Debug Adapter, Lagesensor zugefügt, Umwelt Sensor, ISM 868 MHz Tranceiver, ESP and Control Bus. UID Eprom. Etliche Aufräum Ar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
    [Connector.sch, IO.sch, MCU.sch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]
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2019-10-04 Wago Steckverbinder hinzugefügt, Schaltplan erheblich aufgeräumt, Funktionsgruppen bezeichnet, Extension Port (Port PF) als Stecker hinzu gefügt
    [250-202.stp, 250-203.stp, 250-204.stp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]
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2019-10-14 Schaltplan erst mal fertig gestellt, Bilblotheken angepasst, High Side Treiber zugefügt
    [733-363.stp, 733-366.stp, 733-368.stp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]
2019-10-16 Schaltplan: Pulldown bei den Mosfets zugefügt, Fehler Korrektur, Baulteil Footprints zugewiesen und Lib angepasst, Netztliste ohne Fehler zum Layout übertragbar. Board: Auf neues Design angepasst, Be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
    [Connector.sch, IO.sch, MCU.sch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]
2019-10-17 Schaltplan: Kleinere Korrekturen Layout: I/O Ports Gröstenteils platziert
    [IO.sch, Womo.kicad_pcb]
2019-10-18 Grobplatzierung abgeschlossen, Raspberry und GSM/GNSS Bohrungen Platziert, Befestigungsbohrungen festgelegt, Board Outline festgelegt
    [Connector.sch, IO.sch, Womo.kicad_pcb]
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2019-11-12 Layout Arbeit, Project Library sollte jetzt auf allen Rechnern funktionieren. Leerzeichen entfernt.
    [Connector.sch, IO.sch, MCU.sch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]
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2019-11-16 Rechte Seite CPU gerouted, SPI 1 / 2 getauscht.
    [MCU.sch, Womo.kicad_pcb]
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2019-11-24 Displayunit: Fix Libs, fix, Footprints, PCB angelegt, Auf eine Schaltplanseite reduziert.
    [Displayunit.kicad_pcb, Displayunit.sch, Power.sch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]
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2019-11-26 Fix Womo BRD für Produktion, Displayboard Schaltplan weitere Arbeiten.
    [Displayunit.sch]
2019-11-27 Fix: Produktionsdaten Board Arbeiten Schaltplan Displayunit
    [Displayunit.sch]
2019-12-02 Display Board kleinere Schaltplan Anpassung , Board Design an New Heaven Display angepasst, Platzierung zu 95 % abgeschlossen
    [Displayunit.kicad_pcb, Displayunit.sch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]
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2019-12-06 Displayboard: Flex Stecker Position festgelegt, verschiebung von Componenten.
    [Displayunit.kicad_pcb, Displayunit.sch]
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2020-01-07 Fix: behinderten Masse Bug an 3v3 Regler Mainunit und Displayboard
    [Connector.sch, Displayunit.sch, IO.sch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]
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2020-02-21 Displayboard fertig layoutet, kleinere Fehler beseitigt, WomoLin Biblothek senkrechter Würth RJ 45 zugefügt
    [Displayunit.kicad_pcb, Displayunit.sch]
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2020-04-02 Display Board: Fix JTAG REF, LED Treiber > TPS61165, Spulen zurück auf XAL4040 Footprint, Auf Version 2.0 gehoben
    [Displayunit.kicad_pcb, Displayunit.sch]
2020-04-05 Kleinere Änderungen, aufgrund von Kicad Problemen, auf anderem System weiter arbeiten.
    [Connector.sch, IO.sch, MCU.sch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]
2020-04-07 SI8422 Lib angelegt, TTLRS232 einzeln isoliert, Victron VE Bus kompatieble Stecker zugefügt.
    [Connector.sch, IO.sch, MCU.sch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]
2020-04-15 Fix Lib gedrehte FPC Stecker, 10 Pin FPC hinzu gefügt (Buydisplay.com Alternative) Displayboard RS485 und CAN Option hinzu. Beginn Änderung Layout.
    [Displayunit.kicad_pcb, Displayunit.sch, _saved_IO.sch]
2020-04-16 Fix Womolin Lib, ein paar Bauteile fehlte Lötstopmaske. Displayboard stand zweite Prototyp Bestellung.
    [Displayunit.kicad_pcb, Displayunit.sch, Displayunit_prod.csv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]
2020-04-21 Displayunit: Kleiner Fix Mainboard: Netzteil Sektion komplett auf TI umgestellt, Footprints angepasst. Victron kompatible TTY Ports platziert und gerouted, auf Version 2.0 gehoben.
    [Connector.sch, Displayunit.kicad_pcb, IO.sch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]
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2020-04-22 Board: CAN auf 3V umgestellt, neue CAN Treiber, alle auf 3v3 CPU Power, Standby mit Pulll down, ohne PI und ESP keine Blockade des Busses, Schaltbare Abschlüsse vom CAN, Layout Arbeit.
    [Connector.sch, Displayunit_prod.csv, MCU.sch]
2020-04-24 Board: Änderung Footprints, Debug geroutet, Beginn Platzierung Netzteil, Bezeichnungen und Werte aufgeräumt.
    [Connector.sch, IO.sch, MCU.sch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]
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2020-05-03 Board: Partlist mit Mouser und LCSC Partnummer erzeugt, kleiner Änderungen in der Bestückung, Änderung Womo Lib, Daten zur Anfrage an PCBAstore erzeugt.
    [Connector.sch, MCU.sch, Power.sch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]
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2020-10-27 Fix VE direct bug in schematic
    [Connector.sch, IO.sch]
2020-10-28 Patch LIB mit Netzwerk Bauteilen, ESP32 und PY hinzu gefügt, PI Netzteil auf 5A
    [Connector.sch, Power.sch]
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2020-11-16 ESP32 Netzwerk PHY und SD fertig, SD STM32 auf Micro SD, Womo_LIN Lib mit Micro SD gepatcht
    [Connector.sch, MCU.sch]
2020-11-26 Fix LPUART RX TX vertauschung an PB10/11
    [MCU.sch]
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2020-12-27 Display Unit Zusätzliche Buchsen Mini Fit für den Bus, Befestigung um 5mm verschoben, Bauteil Placement.
    [Displayunit.kicad_pcb, Displayunit.sch]
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2020-12-31 Problem Vermischung mit V1 Layoutdaten gefixt, Octo SPI Längenmatching. V3 Produktionsdaten für JCLPCB erzeugt.
    [Displayunit.kicad_pcb, Displayunit_prod.csv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]
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

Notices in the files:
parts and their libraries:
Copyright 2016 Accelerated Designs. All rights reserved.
